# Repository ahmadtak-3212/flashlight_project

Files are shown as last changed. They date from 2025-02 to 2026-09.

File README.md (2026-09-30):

# Flashlight: high-power LED driver

A handheld flashlight built around a **Cree XHP50.3 (6 V)** LED. The repo holds two threads of work:

1. **The power converter** (finished, documented in the final report): a discrete, analog, constant-current **boost converter** that takes 3 V from two alkaline cells up to about 6–6.5 V and regulates the LED at about 1–1.5 A. It uses op-amps, a comparator and a gate driver, with no microcontroller in the loop. It was built as the final project for MIT 6.2222 (fall 2025), including the graduate extension.
2. **The product boards** (in progress): an STM32 controller with shake-to-wake, a USB-PD charger and power-path board, and an integrated v1.1 board meant to put everything on a single 21700-cell PCB.

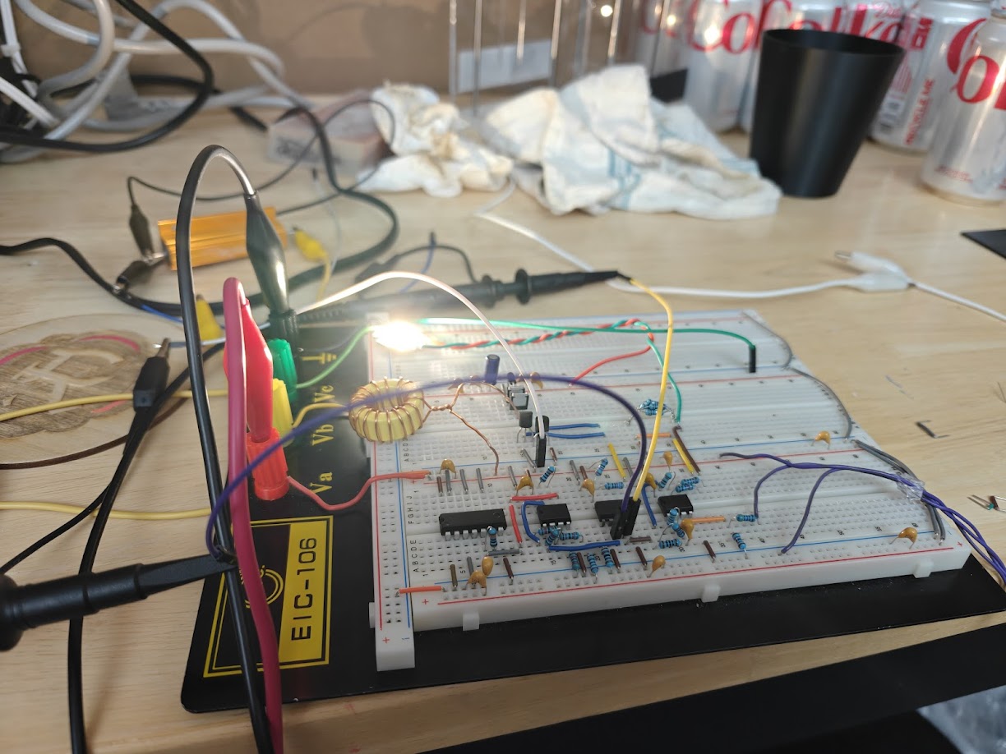
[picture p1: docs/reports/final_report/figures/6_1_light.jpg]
Flashlight running


📄 **Read the final report:** [`docs/reports/final_report/final_report.pdf`](docs/reports/final_report/final_report.pdf) (the Typst source is next to it). The original proposal is in [`docs/reports/proposal/`](docs/reports/proposal).

---

## Contents

- [Status](#status)
- [Repository layout](#repository-layout)
- [How the converter works](#how-the-converter-works)
- [Boards](#boards)
- [Firmware](#firmware)
- [Analysis](#analysis)
- [Mechanical](#mechanical)
- [Reproducing the design](#reproducing-the-design)
- [Results](#results)
- [Known issues and next steps](#known-issues-and-next-steps)

## Status

| Area | Status |
|---|---|
| Boost LED driver (report design) | ✅ Built and measured on the bench (1 A LED current, stable closed loop) |
| Dev boards (`boost-dev`, `boost-dev-2`, `stm32-dev`, `led`) | ✅ Routed, with JLCPCB fab and assembly files |
| USB-PD power-input board | 🟡 Routed (4 layers, KiCad 8/9, May 2026); fab outputs need regenerating (see [known issues](#known-issues-and-next-steps)) |
| Integrated board `flashlight-full-v1-1` | 🟡 Schematic only (14 sheets), not laid out |
| Firmware (STM32 shake-to-wake) | 🟡 Proof of concept (~100 lines) |
| Mechanical (body, head, optic) | 🟡 SolidWorks assembly, not yet built |

## Repository layout

```
flashlight_project/
├── docs/
│   └── reports/
│       ├── final_report/     Typst source + PDF + figures (6.2222 final report)
│       └── proposal/         project proposal (Typst + PDF)
├── electrical/               one KiCad project per board (see "Boards")
├── firmware/
│   └── flashlight-firmware-stm32/   PlatformIO project (STM32L151, Arduino core)
├── analysis/
│   └── sim/boost_transfer.m  MATLAB state-space model of the boost + PI loop
└── mechanical/
    └── cad/flashlight-v1.SLDASM     SolidWorks assembly (body, head, optic, cell)
```

See [docs/STRUCTURE.md](docs/STRUCTURE.md) for the folder conventions shared across my projects.

## How the converter works

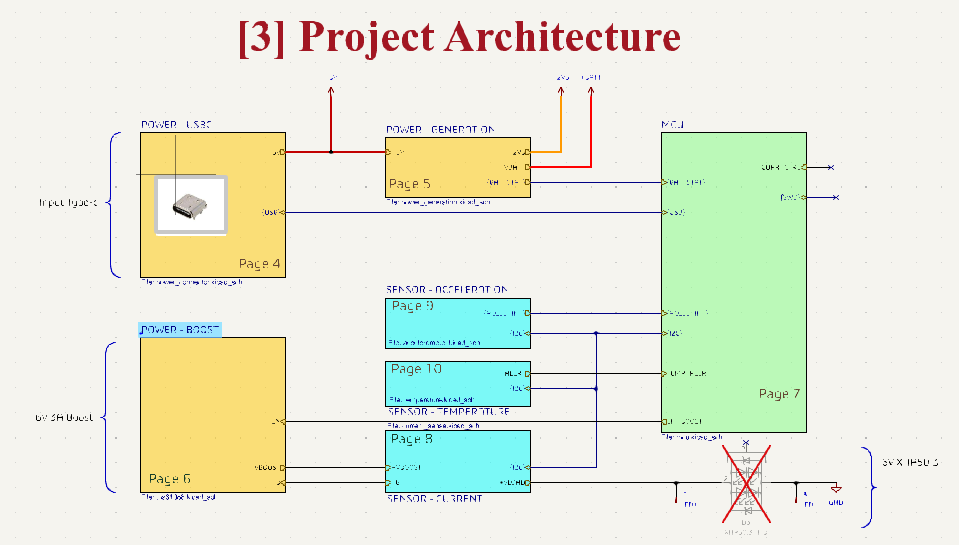
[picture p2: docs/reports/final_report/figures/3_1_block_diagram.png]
Block diagram


**Power stage.** A non-synchronous boost converter: a 22 µH inductor, a low-side switch, a Schottky rectifier and a 120 µF output capacitor. The LED returns to ground through a 0.2 Ω shunt.

| Parameter | Value |
|---|---|
| Input | 3 V (2 × alkaline cells) |
| Output | ≈ 6–6.5 V at the LED, 1–1.5 A (2 A hard ceiling) |
| Switching frequency | ≈ 100 kHz |
| Duty cycle | D ≈ 0.52 |
| Average inductor current | ≈ 3.9 A (ripple ≈ 0.7 A) |
| Inductor sizing | L_min ≈ 18 µH at 20 % ripple, so 22 µH chosen |
| Shunt dissipation | 0.45–0.8 W at 1.5–2 A |

**Control loop.** This is voltage-mode PWM with an outer LED-current loop, all built from analog parts:

1. An **LM358** amplifies the shunt voltage (current sense).
2. A second **LM358** stage acts as a PI controller and outputs V_ctrl. The model maps it with R_in = 10 kΩ and R_f = 680 Ω.
3. A third **LM358** generates a 0–1 V, ~100 kHz triangle.
4. An **LM311** comparator compares V_ctrl with the triangle to produce PWM.
5. An **IR2125** high-current gate driver drives the switch; a 12 V gate supply is needed for the GaN part.

**Switch comparison.** The same power stage was run with a silicon MOSFET (**RFD3055LESM**, ~107 mΩ) and a GaN FET (**GAN041-650WSBQ**, ~41 mΩ). Estimated device loss at the operating point is ≈ 84 mW for Si versus ≈ 18 mW for GaN, and the GaN part ran visibly cooler.

**Graduate extension.** The report adds a switched-capacitor quadrupler that charges a storage capacitor for a "flash" pulse through a 1 Ω series resistor (see “Graduate Extension” in the report).

The report also covers loop-shaping with Black's feedback formula and the boost converter's right-half-plane zero. It compares voltage-mode and current-mode control, drawing on the TI application notes it cites.

## Boards

All boards are KiCad projects under `electrical/`. Board renders are generated from the committed Gerbers.

| Board | What it is | Key parts | PCB |
|---|---|---|---|
| [`flashlight-boost-dev`](electrical/flashlight-boost-dev) | First IC-based LED boost test board | TPS61169 boost LED driver, NSR0240 Schottky, 4.7 µH WE-MAPI | 2 layers, 32 × 32 mm, JLCPCB files |
| [`flashlight-boost-dev-2`](electrical/flashlight-boost-dev-2) | Higher-power IC boost test board | TPS61500, 10 µH CDRH105R, SS36 3 A Schottky | 2 layers, 33 × 33 mm, JLCPCB files |
| [`flashlight-stm32-dev`](electrical/flashlight-stm32-dev) | "STM32L151C8 Battery Dev Board": controller and charging bring-up | STM32L151C8, BQ25185 charger/power path, MMA8452Q accelerometer, 2 × MCP1703A LDO, USB-C, ST-LINK header, 2 × 12 GPIO headers, RGB LED, 8 MHz + 32.768 kHz crystals | 6 layers, 120 × 35 mm, 99 parts, JLCPCB files |
| [`flashlight-led`](electrical/flashlight-led) | Small round LED carrier board | 3 LEDs, +18 V input | 2 layers, JLCPCB files |
| [`flashlight-power-input-dev`](electrical/flashlight-power-input-dev) | "100 W Power Delivery + Charger Module" | CYPD3177 USB-PD sink, BQ25792 buck-boost charger, BQ297xx protector, 4 × CSD16406Q3, 2 × LM5050-1 ideal diodes, TPS61222, TLV733, 21700 cell | 4 layers, 100 × 30 mm, 97 parts |
| [`flashlight-full-v1-1`](electrical/flashlight-full-v1-1) | Integrated flashlight (schematic) | STM32F070F6P, TPS61088 boost, BQ25185, BQ27220 fuel gauge, MMA8452Q, TMP102, INA180A1, MCP4017 digipot, IR2125, LM358 × 3, LM311, 74HC14, 2 × XHP50.3, 21700 cell, USB-C | 6-layer stackup, 14 schematic sheets, not laid out |
| `flashlight-hardware` | Empty placeholder project | — | — |

The early plan used TI boost-LED ICs (the two `boost-dev` boards). They could not deliver the current the XHP50.3 needs, which is why the report design went discrete.

<details>
<summary>Board renders (top and bottom)</summary>

**flashlight-boost-dev** (TPS61169)
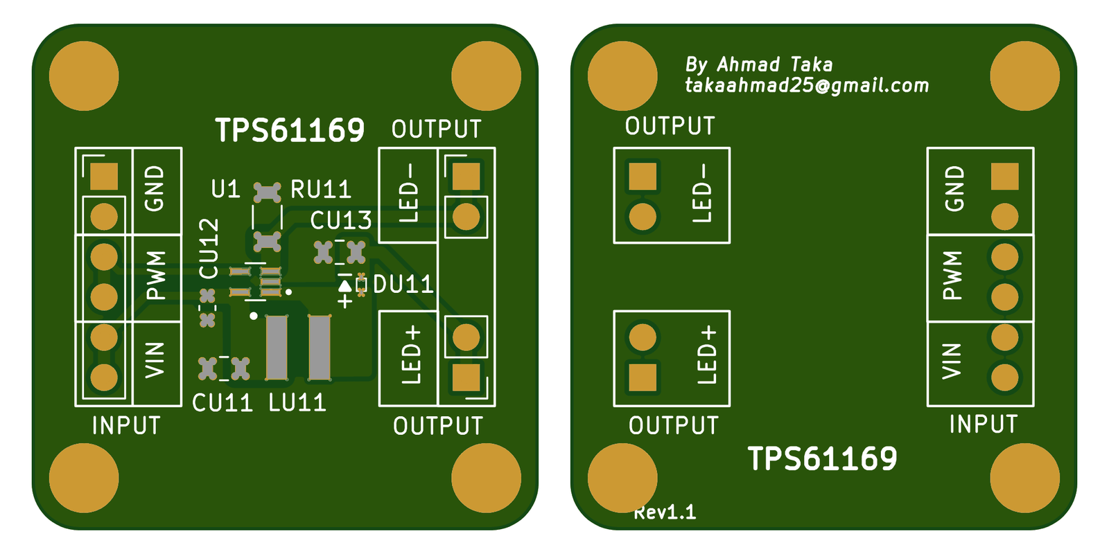
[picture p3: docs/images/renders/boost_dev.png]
boost-dev


**flashlight-boost-dev-2** (TPS61500)
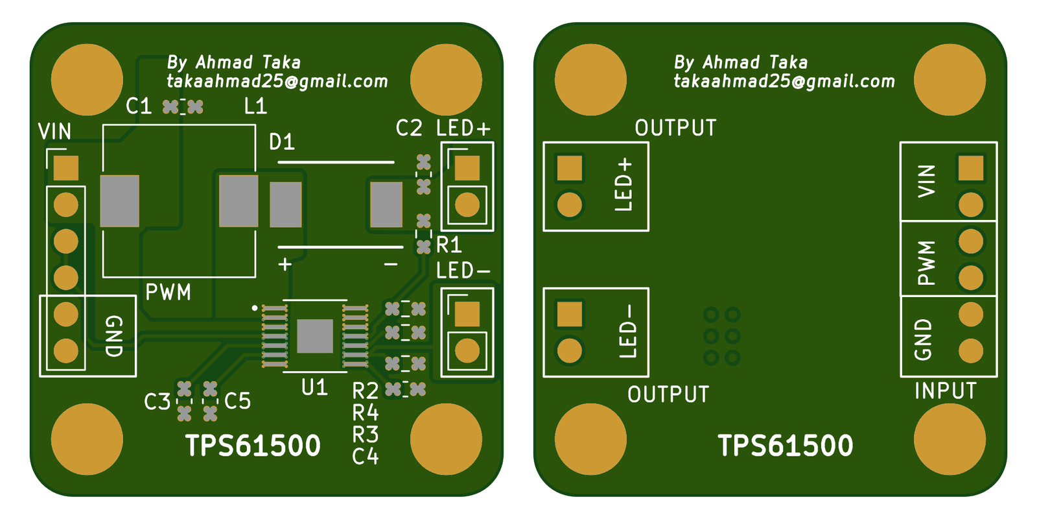
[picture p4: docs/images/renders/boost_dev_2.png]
boost-dev-2


**flashlight-stm32-dev**
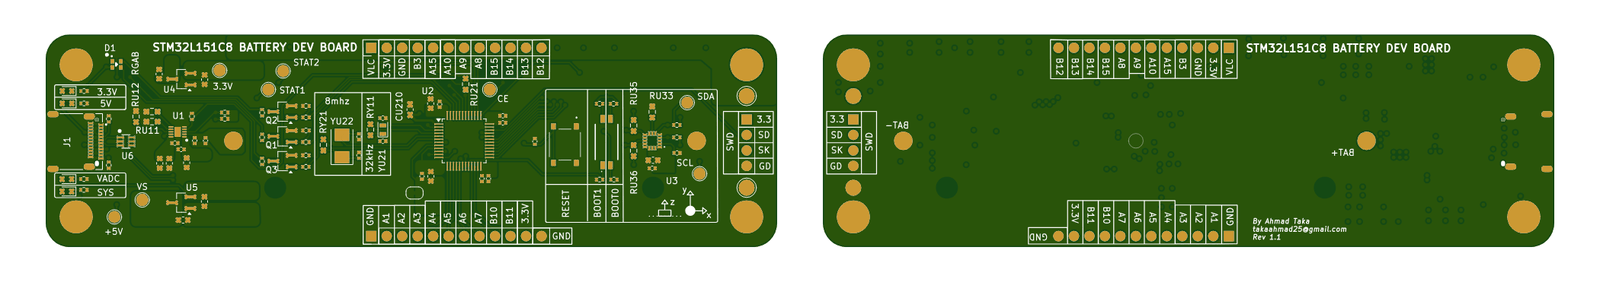
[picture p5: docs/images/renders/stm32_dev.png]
stm32-dev


</details>

## Firmware

`firmware/flashlight-firmware-stm32` is a PlatformIO project for the STM32L151 dev board. It shows the shake-to-toggle behavior:

- It configures the MMA8452Q **transient (shake) detector** over I²C on PB7/PB6: X/Y axes, threshold 12 (≈ 0.75 g), 25 × 20 ms debounce.
- The accelerometer interrupt on **PA0** wakes the MCU from deep sleep through `STM32LowPower`, and each shake toggles the output on **PB9**.

| Setting | Value |
|---|---|
| Platform | `ststm32`, Arduino framework |
| Board definition | `rak811_tracker` (an STM32L151 board used as a stand-in), with a local `boards/` directory |
| Libraries | `sparkfun/SparkFun_MMA8452Q ^1.4.0`, `stm32duino/STM32duino Low Power ^1.4.0` |
| Upload | `serial`: the STM32 ROM UART bootloader (hold BOOT0 high and reset) |

```bash
cd firmware/flashlight-firmware-stm32
pio run                     # build
pio run -t upload           # flash over the UART bootloader
# or use the board's ST-LINK header: set upload_protocol = stlink in platformio.ini
```

## Analysis

`analysis/sim/boost_transfer.m` (MATLAB) builds the averaged small-signal model of the boost, including the RHP zero. It wraps the PI controller around that model as an augmented state-space system, then plots the loop Bode response and the closed-loop setpoint step. Run it in MATLAB with the Control System Toolbox. The listing is also in the report appendix.

| Loop gain | Step response |
|---|---|
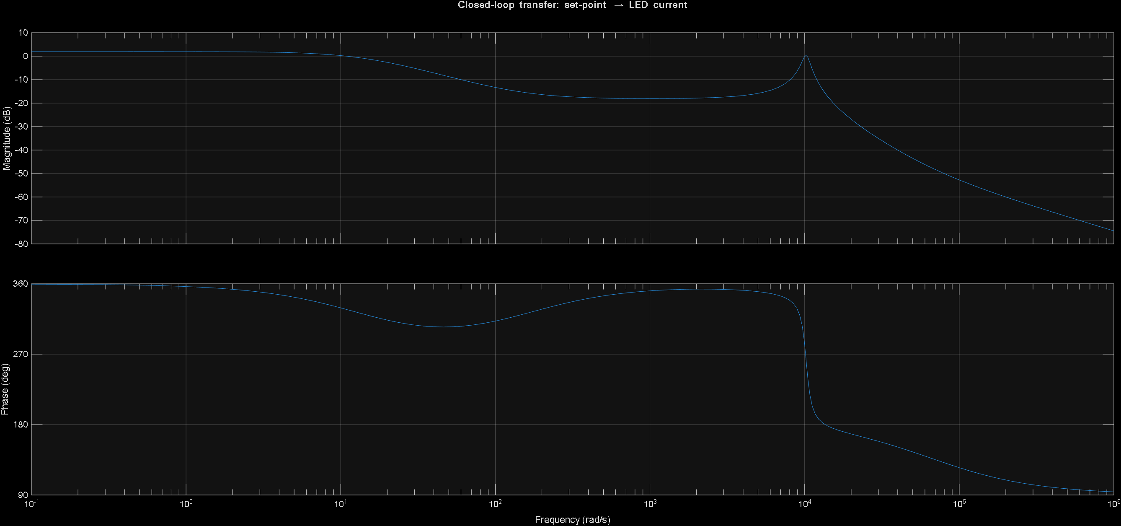
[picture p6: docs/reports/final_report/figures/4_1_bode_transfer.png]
Bode
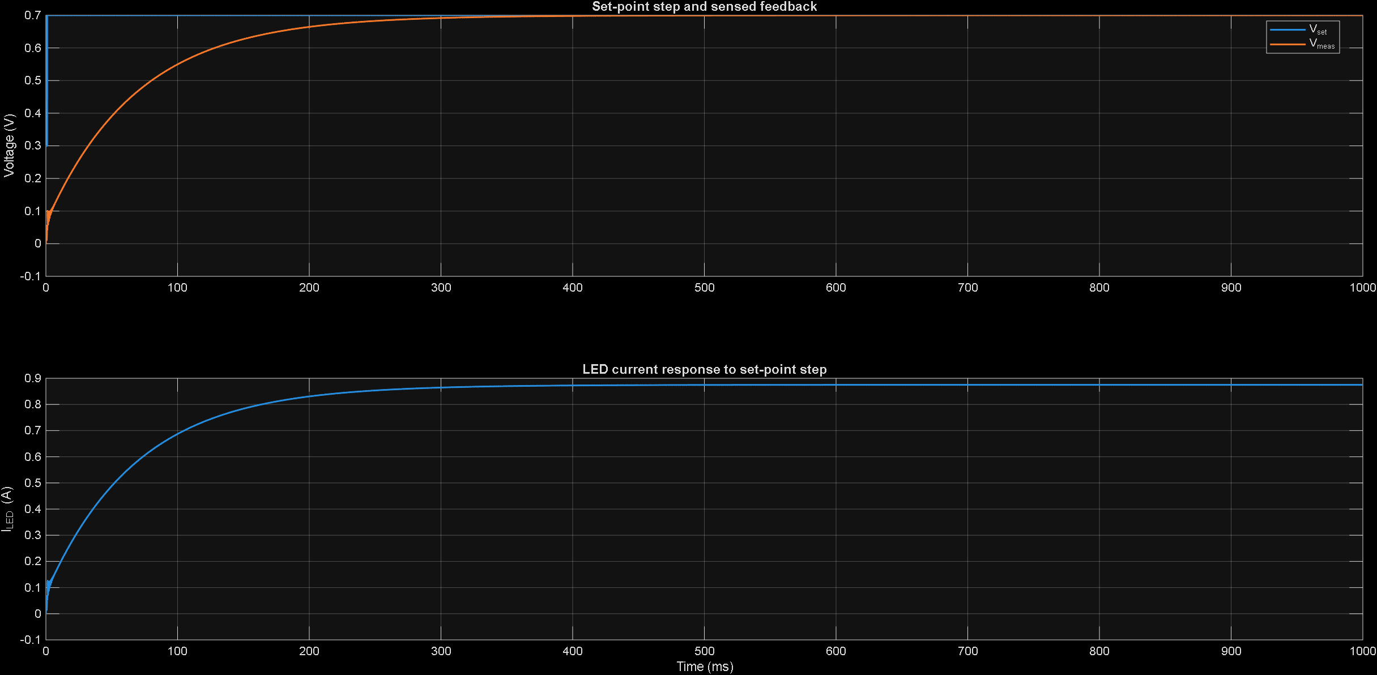
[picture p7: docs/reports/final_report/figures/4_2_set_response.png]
Step
|  |  |

## Mechanical

`mechanical/cad/flashlight-v1.SLDASM` (SolidWorks) contains the body, head, a TIR 60° optic, an 18650 cell model, a copper slug for the LED, and the LED PCB. Mounting holders for the dev boards are in `electrical/<board>/holder/` (SLDPRT and STEP).

## Reproducing the design

| What | Tool |
|---|---|
| Schematics and PCBs | KiCad 8 or newer. `flashlight-power-input-dev` was last saved in KiCad 9. Projects use `${KIPRJMOD}`-relative libraries in each board's `libs/` folder. |
| PCB fab and assembly | Each board has `jlcpcb/gerber/` and `jlcpcb/production_files/` (Gerber zip, BOM and CPL) for JLCPCB. |
| Report | [Typst](https://typst.app) (`typst compile final_report.typ`) |
| Model | MATLAB with the Control System Toolbox |
| Firmware | PlatformIO (VS Code extension or `pio` CLI) |
| CAD | SolidWorks |

**Rebuilding the report converter on a bench.** Component values and schematic blocks are in the report's “Circuit Design and Analysis” chapter, which covers the power stage, current sense and PI loop, magnetics, and switch choice. “Hardware Implementation and Measurement Setup” covers the bench setup.

Bring-up order, from the report:
1. Run the boost open-loop at a fixed duty cycle into a resistive load.
2. Close the current loop at a low setpoint.
3. Raise the setpoint to the LED operating point.

The two fixes that mattered were:
- an RC filter (100 Ω / 1 nF) on the current-sense signal, and
- hysteresis on the LM311 comparator to stop chatter.

## Results

- The loop is closed and stable at about **1 A LED current** from a 3 V input. The output is 6–6.5 V, and the measured duty cycle is ≈ 0.5, close to the 0.52 predicted.
- The setpoint step response is well damped, as the MATLAB model predicts. Remaining differences come from LM358 bandwidth, comparator delay and the non-ideal ramp.
- GaN vs Si: both reach the same operating point, and the GaN FET runs cooler.
- The LED case settles near **70 °C** at the operating point. That is acceptable, but heatsinking through the copper slug is required.

| Bench setup | Thermal |
|---|---|
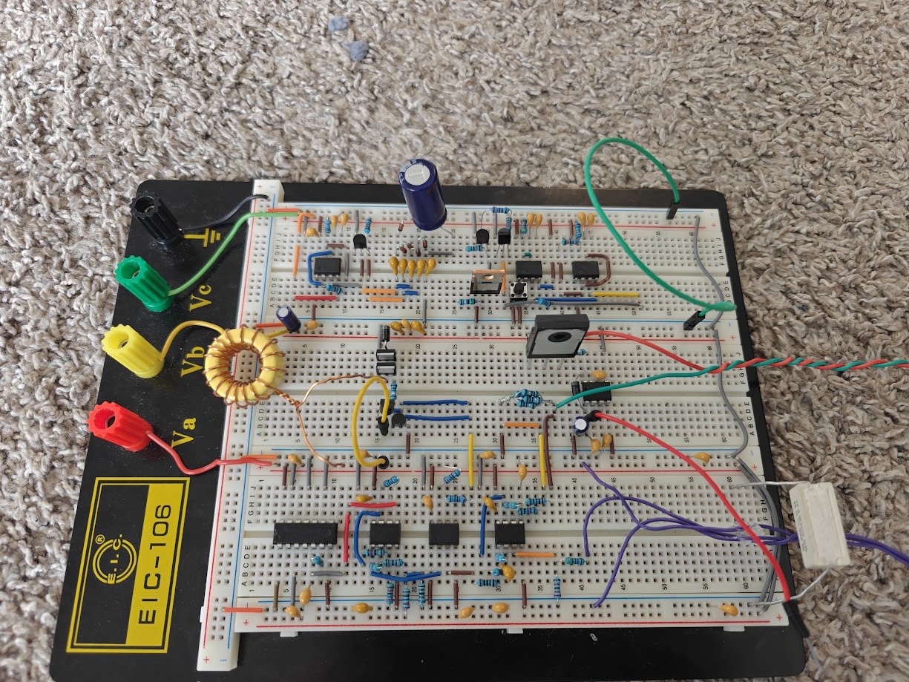
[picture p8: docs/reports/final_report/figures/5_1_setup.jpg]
Setup
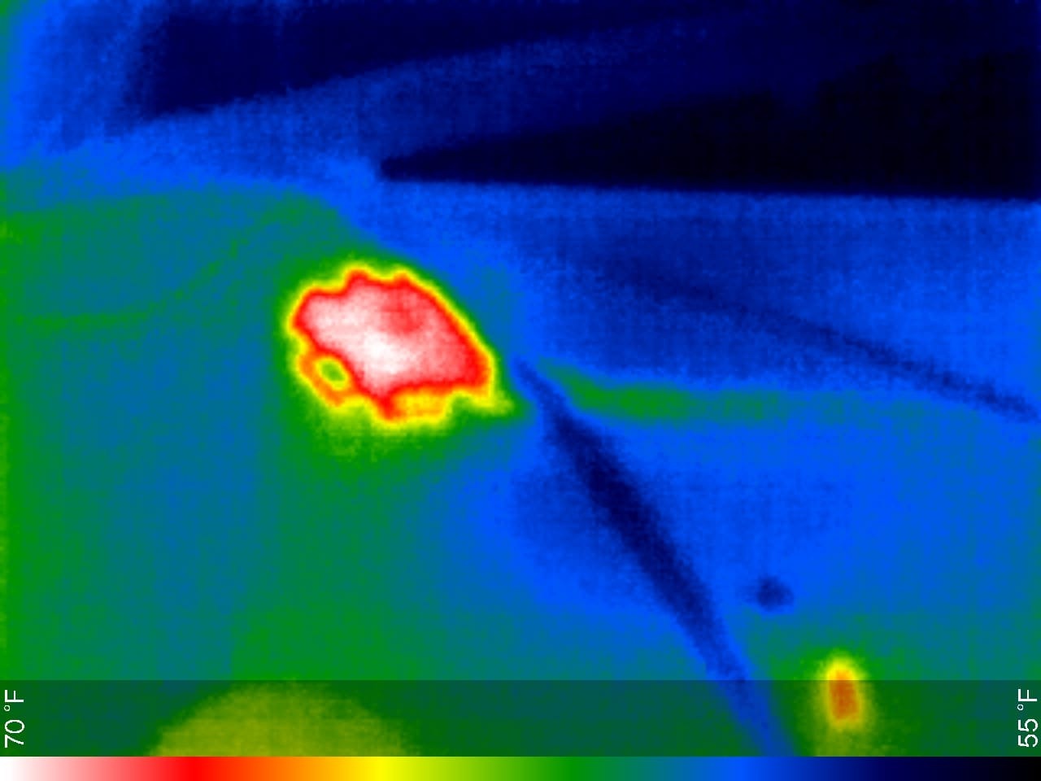
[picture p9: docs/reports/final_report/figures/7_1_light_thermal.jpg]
Thermal
|  |  |

## Known issues and next steps

- The Gerbers in `electrical/flashlight-power-input-dev/jlcpcb/` are **copies of the mp3 player board**, left over from the project template. Regenerate them from `flashlight-power-input-dev.kicad_pcb` before ordering.
- `flashlight-full-v1-1` still needs layout. It merges the report's analog current loop (LM358/LM311/IR2125) with the STM32 controller, charger and fuel gauge.
- Firmware still needs brightness control through the digipot or PWM setpoint, battery reporting from the BQ27220, and thermal limiting from the TMP102.

## Author

Ahmad Taka.

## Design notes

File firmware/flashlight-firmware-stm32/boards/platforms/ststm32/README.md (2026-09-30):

# ST STM32: development platform for [PlatformIO](https://platformio.org)



The STM32 family of 32-bit Flash MCUs based on the ARM Cortex-M processor is designed to offer new degrees of freedom to MCU users. It offers a 32-bit product range that combines very high performance, real-time capabilities, digital signal processing, and low-power, low-voltage operation, while maintaining full integration and ease of development.

* [Home](https://registry.platformio.org/platforms/platformio/ststm32) (home page in the PlatformIO Registry)
* [Documentation](https://docs.platformio.org/page/platforms/ststm32.html) (advanced usage, packages, boards, frameworks, etc.)

# Usage

1. [Install PlatformIO](https://platformio.org)
2. Create PlatformIO project and configure a platform option in [platformio.ini](https://docs.platformio.org/page/projectconf.html) file:

## Stable version

```ini
[env:stable]
platform = ststm32
board = ...
...
```

## Development version

```ini
[env:development]
platform = https://github.com/platformio/platform-ststm32.git
board = ...
...
```

# Configuration

Please navigate to [documentation](https://docs.platformio.org/page/platforms/ststm32.html).

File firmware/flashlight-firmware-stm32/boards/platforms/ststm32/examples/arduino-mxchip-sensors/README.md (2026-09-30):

How to build PlatformIO based project
=====================================

1. [Install PlatformIO Core](https://docs.platformio.org/page/core.html)
2. Download [development platform with examples](https://github.com/platformio/platform-ststm32/archive/develop.zip)
3. Extract ZIP archive
4. Run these commands:

```shell
# Change directory to example
$ cd platform-ststm32/examples/arduino-mxchip-sensors

# Build project
$ pio run

# Upload firmware
$ pio run --target upload

# Clean build files
$ pio run --target clean
```

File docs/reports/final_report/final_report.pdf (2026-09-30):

# Final Project Report: Flashlight Power Converter Design

Ahmad Taka
ahmadtak@mit.edu
MIT EECS

December 9th, 2025

## 1 Introduction and Project Motivation

For the final project, a discrete, low-voltage boost LED driver is designed and built for a Cree XHP50.3 6 V LED (XHP50D-00-0000-0D0UH240G).(Xlamp Xhp50.3 Leds 2025) The objective is to realize a compact, thermally-managed flashlight that is bright enough to illuminate a workspace or driveway while remaining efficient and comfortable to hold. Although high-power LED flashlights are widely available, most commercial designs conceal the internal power-converter behavior and provide little visibility into regulation, transient response, or thermal performance. This work instead emphasizes a transparent, measurement-friendly architecture in which the power electronics are explicitly designed, modeled, and probed, rather than relying on off-the-shelf drivers.

The project builds on prior hardware developed over the summer, where a custom STM32-based board was designed to manage a Li-ion cell, deliver up to 3 A on a power-path rail using the BQ2125, and interface with an onboard accelerometer to implement a “shake-to-wake” LED control gesture. During that effort, several commercial boost LED drivers, including the TPS61169 and TPS61500, were evaluated and found unable to deliver sufficient current to fully drive the Cree XHP50.3. These limitations motivated the development of a higher-power, constant-current architecture in which a boost converter measures LED current via a shunt resistor and regulates it directly to achieve stable brightness and predictable thermal behavior. In the present work, the prototype operates from a single 3 V rail representing a fresh pair of alkaline cells, with no upstream regulation. The converter must boost from 3 V to approximately 6–6.5 V to drive the Cree XHP50.3 in its 6 V configuration (typical forward voltage 5.6–6.2 V at 1.4 A, 3 A continuous rating), while maintaining acceptable component stress and temperature margins.(Xlamp Xhp50.3 Leds 2025)

For the 6.2222 graduate extension, the flashlight driver is used as a laboratory platform for converter modeling, control design, and energy-flow analysis. The implementation uses discrete analog building blocks (LM358 op-amps, comparator, 22 µH inductor, current shunt), alongside small-signal modeling and MATLAB state-space simulation to study loop stability and transient response. Time-domain and frequency-domain measurements (inductor current, switch node voltage, LED current, control signals) will be used to validate the models. In addition, silicon MOSFET and GaN FET devices will be compared in the same boost topology to quantify differences in switching loss and thermal performance. Tellegen’s theorem will be applied to track energy flow through the converter and verify that measured power losses are consistent with theoretical predictions. Finally, a small switched-capacitor voltage doubler will be constructed to generate short, higher-voltage flashes on the LED, extending Lab 3 concepts to examine how brief high-voltage bursts affect brightness and heating.

## 2 Independent Inquiry Background and Control-Theoretic Context

The independent inquiry drew on the 6.2222 notes, Tellegen-based energy flow arguments, and two Texas Instruments application reports on boost converter feedback loops.(Lee 2014a; 2014b) The reference material places the boost in the context of general feedback-system theory, emphasizing loop gain, sensitivity, and the special role of right-half-plane (RHP) zeros in the overall stability of the system.

### 2.1 Black’s feedback theorem and loop-shaping viewpoint

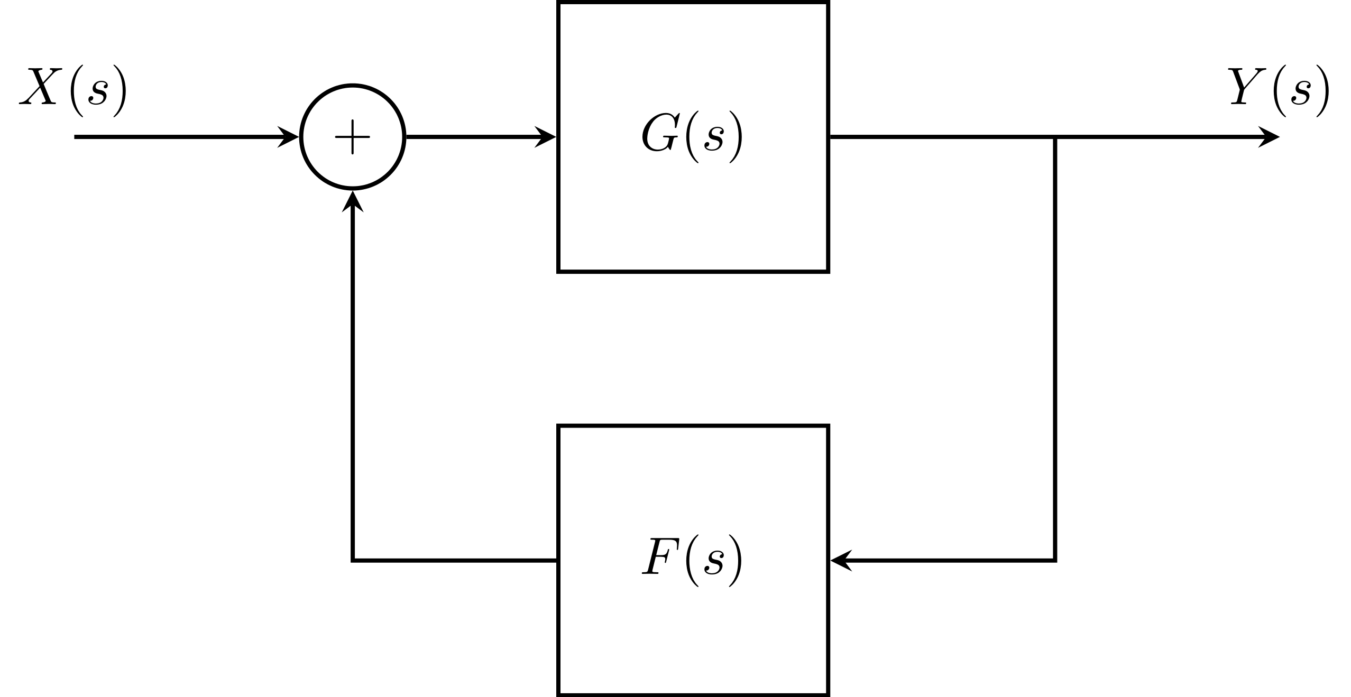
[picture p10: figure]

Figure 1: Blacks formula block diagram

Black’s classical feedback model represents the closed-loop system as a forward plant G(s), a feedback network F(s), and an input X(s) and output Y (s). The basic closed-loop relation is

T (s) =

Y (s)
X(s)

=

G(s)
1 + G(s)F(s)

(1)

Defining the loop gain
L(s) = G(s), F(s) | (2)
the sensitivity and complementary sensitivity functions are

S(s) =

1
1 + L(s)

, q T (s) =

L(s)
1 + L(s)
. | (3)

Low |S(jω)| at low frequency means good disturbance rejection and small steady-state error; the magnitude and phase of L(jω) near crossover control stability and transient behavior. In the LED driver, the plant G(s) is the averaged boost converter plus PWM modulator; the compensator and current-sense network form F(s). The design goal is a loop gain L(s) that achieves accurate current regulation (low-frequency gain and small |S|) and sufficient phase margin at crossover.

### 2.2 Voltage-mode versus current-mode control in boost converters

The TI voltage-mode report models the continuous-conduction boost as an LC output filter with ESR zero and an RHP zero whose location depends on load, inductance, and duty cycle.

(Lee 2014a) Linearization gives a control-to-output transfer function with a moving double pole at the LC resonance and a right-half-plane zero at

frhp = Rload ∗

(1 − D)

2
2 ∗ π ∗ L

(4)

This zero moves to lower frequency at heavy load, low input voltage, or large inductance. It contributes +20 dB/dec of gain but also an additional 90° of phase lag, so Black’s feedback theorem implies that the loop crossover must be kept well below this frequency (typically fc ≤

frhp
5

) to preserve adequate phase margin and avoid instability.(Lee 2014a)

The current-mode report analyzes an alternative architecture with an inner cycle-by-cycle current loop and an outer voltage loop.(Lee 2014b) From the outer-loop perspective, the inductor dynamics are “prelinearized” and the LC double pole collapses to a single dominant pole associated with the output capacitor and load. A Type-II compensator (one pole at the origin plus a pole–zero pair) suffices, with simpler design rules and improved phase margin at a given crossover.

### 2.3 Relevance to a constant-current LED boost driver

Although the final flashlight driver is not a textbook current-mode converter, the LED-current regulation problem is structurally similar to the TI voltage-mode designs: a PI controller and comparator form a voltage-mode outer loop around a boost power stage whose “load” is a nonlinear LED plus shunt resistor. Around a given operating point, the LED may be linearized as an effective resistance, so the plant still exhibits an LC double pole and an RHP zero set by L, duty cycle, and equivalent load resistance.

The inquiry applied the TI voltage-mode model to estimate frhp and the LC resonant frequency for the chosen inductance and LED operating points, setting upper bounds on crossover. It then used the current-mode compensator rules as a template for the PI design: integrator pole at the origin, a zero below crossover to add phase, and a high-frequency pole implicit in the op-amp and PWM modulator. Black’s sensitivity functions S(jω) and T (jω) provide the interpretation: low-frequency gain and small |S| translate into accurate current regulation and good line/load rejection, while adequate phase margin at crossover prevents the duty-cycle adjustments from exciting RHP-zero or half-switching-frequency pathologies.

## 3 System Requirements and Architecture Overview

### 3.1 Electrical and performance requirements

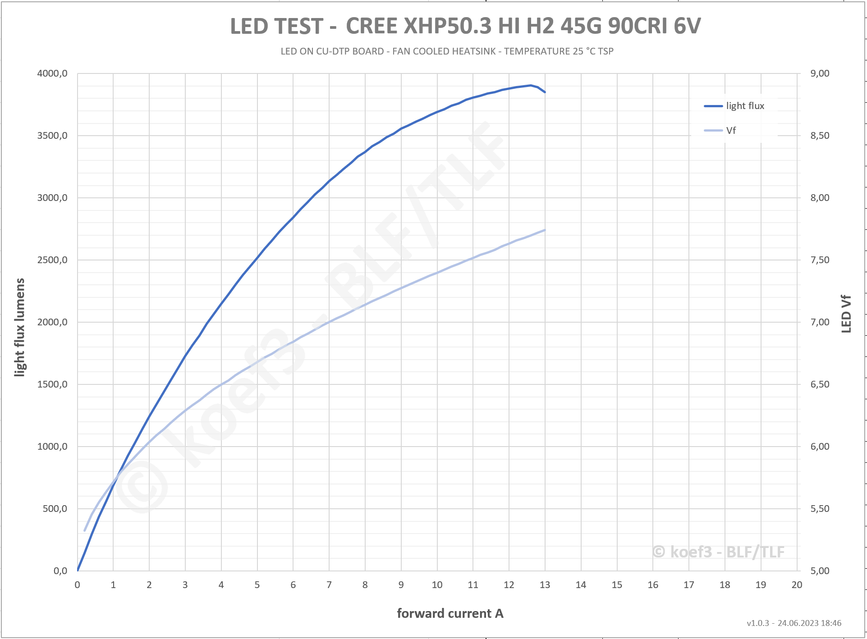
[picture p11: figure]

Figure 2: Plot of LED Load curve and operating points

The driver targets a single 3 V supply (two alkaline cells) and a Cree XHP50.3 6 V LED driven near 1–1.5 A, with a hard upper ceiling around 2 A to respect the 3 A absolute maximum rating and keep junction temperatures reasonable.(Xlamp Xhp50.3 Leds 2025) Around the design operating point the LED forward voltage is about 6 V, so the converter must provide roughly 6–6.5 V from a 3 V input.

For an ideal continuous-conduction boost converter, the dc conversion ratio is

M =

Vout
Vin

=

1
1 − D
, | (5)

so with Vin = 3, V and Vout ≈ 6.2, V the required duty cycle is

D = 1 −

Vin

Vout

≈ 1 −

3
6.2
≈ 0.52. | (6)

At Vout ≈ 6.2, V and Iout ≈ 1.5, A, the output power is ≈9.3 W. With efficiency in the 75–85% range, the input current is roughly 4–4.5 A, which sets the stress on the inductor, switch, diode, and shunt. The design goal is to keep LED current ripple below about 10% of the dc level.

### 3.2 Control and stability requirements

From a control standpoint, the driver should behave as a current regulator: the user sets an LED current, and the loop adjusts duty cycle so that the measured average current tracks over variations in LED forward voltage and input voltage. The specific objectives are:

- Continuous conduction in the main operating region.
- Crossover fc

below both the boost RHP zero and fsw
10

, with at least 45–60° of phase margin.
- Step changes in setpoint that settle without sustained oscillation and with limited overshoot.
- Hardware constraints on maximum duty cycle set by op-amp swing and ramp amplitude, even though no explicit clamp circuit is present.

The implemented structure uses LM358 op-amps at 3 V for current sense, PI controller, and triangle generator, plus a comparator and low-side switch device. The independent inquiry provides the theoretical basis for selecting PI pole and zero locations and the target loop gain shape.

### 3.3 Thermal and mechanical constraints

The LED dissipates roughly 10 W at full brightness, plus several watts of converter loss. The XHP50.3 is rated to 150 °C junction, but practical operation suggests staying well below 100 °C for long life and color stability.(Xlamp Xhp50.3 Leds 2025) The inductor and switch device must handle several amperes of current without saturation or excessive temperature rise.

Mechanically, the prototype is built on a breadboard or prototyping PCB with careful attention to minimizing loop inductances on the high-di/dt paths and providing accessible test points (Vmeas, Vset, V_tri, V_ctrl, switch node). A future PCB version would fit into a flashlight host, but the electrical requirements are already based on that form factor.

### 3.4 Architecture overview

The system is partitioned into:

1. Input stage (3 V source and local decoupling),
2. Boost power stage (22 µH inductor, rectifier diode, 120 µF output capacitor, LED, 0.2 Ω shunt),
3. Current-sense and signal-conditioning (0–1 V range),
4. PI controller and reference generation (0–1 V setpoint),
5. PWM modulator and gate drive (100 kHz ramp and comparator),
6. Measurement hooks for scope-based loop analysis.

This architecture links the requirements to specific circuit blocks and provides a clean mapping to the modeling and simulations that follow.

## 4 Circuit Design and Analysis

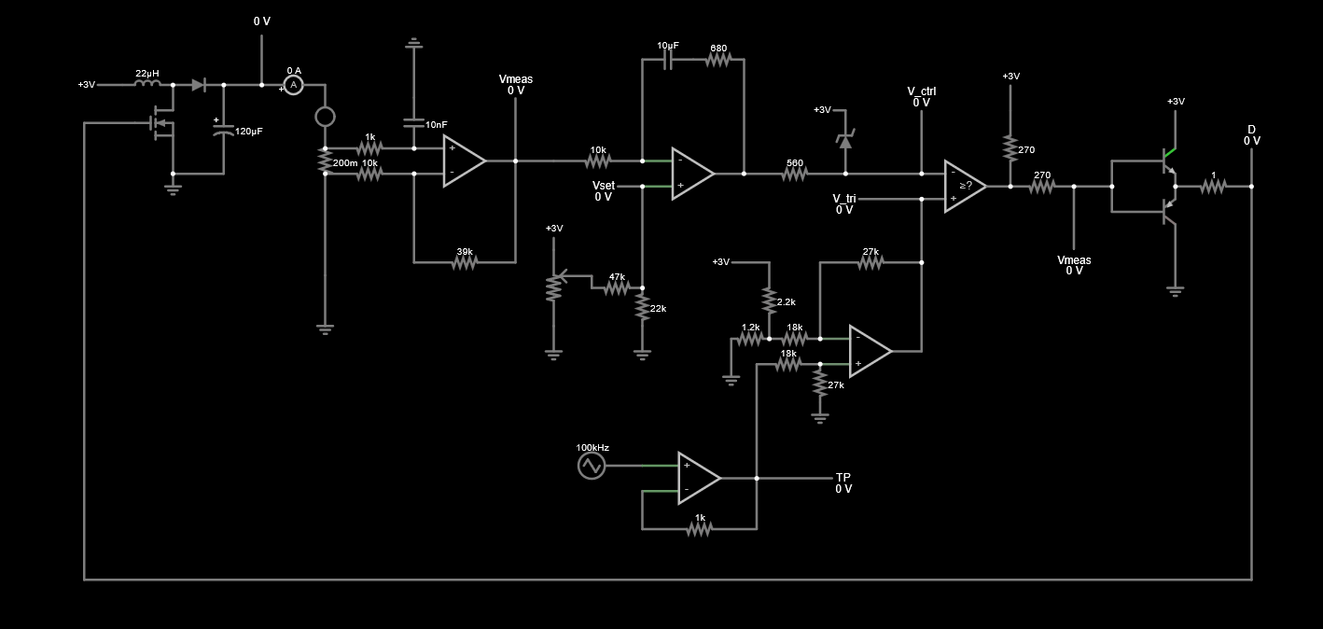
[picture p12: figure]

Figure 3: schematic of boost converter circuit

### 4.1 Power Stage (Boost Converter)

The power stage in figure 3 is a non-synchronous boost converter that steps a single 3 V source up to ≈6–6.5 V for the XHP50.3 LED.(Xlamp Xhp50.3 Leds 2025) The inductor (L = 22, µH) sits in series with the input, followed by a Schottky rectifier and an output capacitor (Cout = 120, µF) feeding the LED and 0.2 Ω sense resistor. A low-side switch periodically connects the inductor to ground; in the on interval the inductor current ramps up, and in the off interval the stored energy is delivered to the output.

Assuming Iout ≈ 1.5, A and efficiency η ≈ 0.8, the average inductor current is

IL,avg ≈ Iin ≈ Vout ∗

Iout
η ∗ Vin

≈ 6.2 ∗

1.5
0.8 ∗ 3
≈ 3.9, | (7)

The inductor ripple is set by the input voltage and duty cycle:

ΔIL = Vin ∗

D
L ∗ fsw
. | (8)

With Vin = 3, V , D ≈ 0.52, L = 22, µH, and fsw ≈ 100, kHz, this gives

ΔIL ≈ 3 ∗

0.52
22e − 6 ∗ 100e3
≈ 0.7, | (9)

so the ripple is ≈18% of IL,avg, keeping the stage comfortably in continuous conduction.

The small-signal dynamics follow the standard voltage-mode boost model. The equivalent inductance seen by the output is

Leq =

L
(1 − D)

2

, | (10)

so the power-stage double pole is at

f0 = (

1
2 ∗ π

) ∗ √
(1 − D)

2
L ∗ Cout
. | (11)

The RHP zero is

frhp = Rload ∗

(1 − D)

2
2 ∗ π ∗ L
, | (12)

where Rload is the linearized LED plus series resistance. For the chosen parameters this places f0

in the low-kilohertz range and frhp at several kilohertz, which constrains the allowable loop crossover.

### 4.2 Current Sense and PI Control Loop

The LED current flows through a fixed shunt Rs = 0.2, Ω. With ILED in the 0–2 A range, the shunt voltage vs = ILED ∗ Rs

spans 0–0.4 V. A differential amplifier with gain Asense translates this into a ground-referenced 0–1 V signal:

vmeas(s) ≈ Asense ∗ Rs ∗ ILED(s) ≡ Ksense ∗ ILED(s)

, | (13)

where Ksense = Asense ∗ Rs
is the effective current-sense gain. The setpoint is generated by a potentiometer from 0–3 V and then scaled down by a small divider to 0–1 V:

vset = vpot ∗

Rbot

Rtop + Rbot

, | (14)
with | Rbot
Rtop+Rbot

≈

1/3. An LM358 buffer provides a low impedance reference. When vmeas = vset, the loop enforces
ILED ≈

vset

Ksense

=

vset

Asense ∗ Rs

, | (15)

which matches the MATLAB normalization where vset in the 0–1 V range corresponds to the desired 0–1.25 A LED current.

The error e(t) = vset(t) − vmeas(t)
is processed by an LM358 configured as a PI controller. The input resistor Rin feeds e(t) into the inverting input, and the feedback consists of Rf in parallel
with Cf
, giving the feedback impedance

Zf(s) = Rf =

Rf
1 + s ∗ Rf ∗ Cf
. | (16)

The resulting compensator is

Gc(s) =

Vctrl(s)
E(s)

= −

Zf(s)
Rin

= −(

Rf
Rin ) ∗

1
1 + s ∗ Rf ∗ Cf
, | (17)

where the overall sign is chosen so that the feedback is negative at the comparator input. The LM311 PWM compares Vctrl to a 0–1 V triangle wave, so around the operating point the small-signal duty-cycle perturbation can be approximated as
d(s) ≈ Vctrl(s) = Gc(s) ∗ E(s). | (18)

To relate duty cycle to LED current, the boost converter is modeled in continuous conduction mode with an equivalent LED resistance Rload ≈

VLED
ILED

and steady-state duty ratio D. The averaged small-signal plant from duty perturbation d(s) to LED current is written in the standard two-pole, one right-half-plane-zero form

Gp(s) ≡

ILED(s)
D(s)

= (

Vin
Rload ∗ (1 − D)

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
Q∗ω0

+ 1

, | (19)

with

ω0 =

1 − D
√
L ∗ C

, q Q = (1 − D) ∗

Rload

√L
C

, q ωz = (1 − D)

2 ∗

Rload
L
, | (20)

where ω0

is the LC natural frequency, Q is the damping factor, and ωz is the right-half-plane
zero associated with the boost topology.

Combining the sense amplifier, compensator, and power stage yields the loop equations

e(s) = vset(s) − Ksense ∗ ILED(s)

, q d(s) = Gc(s) ∗ e(s), q ILED(s) = Gp(s) ∗ d(s). (21)

Eliminating e(s) and d(s) gives the closed-loop transfer function from setpoint to LED current:

ILED(s)

vset(s)

= Gp(s) ∗

Gc(s)

1 + Ksense ∗ Gp(s) ∗ Gc(s)

, | (22)

and, equivalently, the transfer from setpoint to sensed voltage is

vmeas(s)

vset(s)

= Ksense ∗ Gp(s) ∗

Gc(s)

1 + Ksense ∗ Gp(s) ∗ Gc(s)

. | (23)

These expressions explicitly show how the closed-loop behavior depends on the design variables L, C, Rload, Rs

, Asense, Rin, Rf

, Cf

, and the operating duty ratio D.

### 4.3 Magnetics and Component Sizing

The inductor value is chosen from a ripple constraint: ΔIL

IL,avg

= Vin ∗

D
L ∗ fsw ∗ IL,avg
≤ ρ, | (24)

with ρ the desired fractional ripple. Rearranging,

L ≥ Vin ∗

D
ρ ∗ fsw ∗ IL,avg
. | (25)

Using Vin = 3, V , D ≈ 0.52, fsw = 100, kHz, IL,avg ≈ 3.9, A, and ρ ≈ 0.2 gives a minimum L of about 18 µH; 22 µH is a natural choice.

The output capacitor size follows from ripple:

ΔVout ≈ Iout ∗

D
Cout ∗ fsw
. | (26)

With the chosen Cout, the ripple is only tens of millivolts, and the (L, C“out”, R“load”) combination yields f0

and frhp consistent with the control design.

The shunt dissipates
Ps ≈ I

2
out ∗ Rs
, | (27)
which at 1.5–2 A and 0.2 Ω is 0.45–0.8 W. This is acceptable for a 1 W sense resistor over short lab runs and provides a relatively large 1 V full-scale sense signal.

### 4.4 GaN vs Si FET comparison

The project compares an onsemi RFD3055LESM MOSFET and a Nexperia GAN041-650WSBQ GaN FET as candidate switches.(Rfd3055le, Rfd3055lesm n-Channel Logic Level Power MOSFET 2002; Gan041–650wsb / Gan041–650wsbq: 650 V, 35 m\ohm{} Gallium Nitride (Gan) FET in a TO-247 Package 2024) The RFD3055LESM has Rds,on ≈ 107mΩ at VGS = 5, V and total gate charge Qg ≈ 11.3, nC; the GAN041-650WSBQ has Rds,on ≈ 41, mΩ (35 mΩ typical) and faster edges.

Conduction loss is approximated by
Pcond ≈ D ∗ I

2
L,avg ∗ Rds,on, | (28)
so with D ≈ 0.52 and IL,avg ≈ 3.9, A:

Pcond,Si ≈ 0.52 ∗ 3.9

2 ∗ 0.107 ≈ 0.85, | (29)

Pcond,GaN ≈ 0.52 ∗ 3.9

2 ∗ 0.041 ≈ 0.32. | (30)

Switching loss is estimated as
Psw ≈ 0.5 ∗ Vin ∗ IL,avg ∗ (tr + tf
) ∗ fsw. | (31)

At 3 V, 3.9 A, 100 kHz, and ≈144 ns total edge time, the silicon device dissipates ≈84 mW; the GaN device at ≈31 ns totals ≈18 mW. At 100 kHz both are conduction-dominated, but the GaN FET cuts total device losses by more than 2×. At higher fsw the GaN advantage grows.

### 4.5 Graduate Extension: Switched-Capacitor Quadrupler Flash Supply

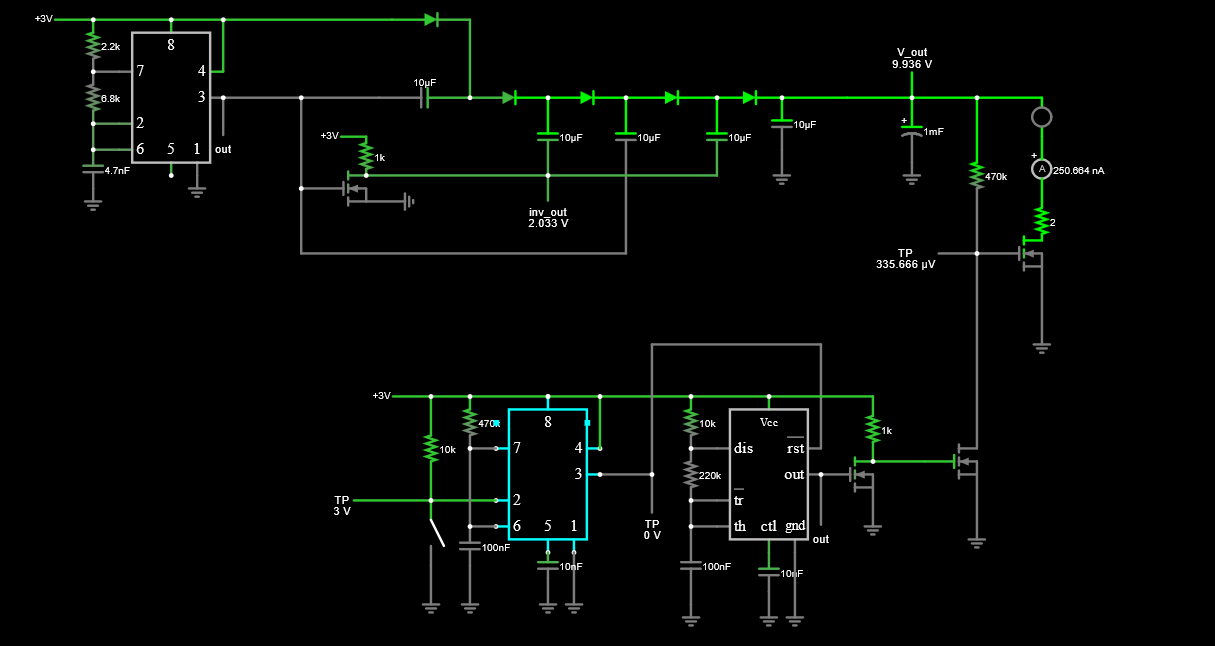
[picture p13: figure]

Figure 4: schematic of switched-capacitor quadrupler flash circuit

In this prototype the network is driven from Vin = 3V and uses four flying-capacitor stages to charge a storage capacitor Cflash to approximately Vflash,hi ≈ 10V . The flash path consists of this storage capacitor, a 1,Ω series resistor, the 6,V, 3,A LED, and a MOSFET switch. During a flash the MOSFET connects Cflash to the LED so that the capacitor discharges from Vflash,hi down toward some lower voltage Vflash,lo.

The energy extracted from the storage capacitor by a single flash is

Eflash =

1
2

⋅ Cflash(V
2
flash,hi − V

2

flash,lo). | (32)

For the measured values Cflash = 1000 μF, Vflash,hi ≈ 10V , and Vflash,lo ≈ 8V , the energy per flash is

Eflash ≈

1
2

⋅ 1000 · 10

−6 ∗ (10

2 − 8

2
) = 0.5 ⋅ 10

−3
⋅ 36 ≈ 18 mJ. | (33)

Two flashes therefore remove roughly 36 mJ from the storage capacitor before it is recharged by the switched-capacitor network.

The instantaneous LED current is set by the voltage left across the series resistance. Approximating the LED as a 6,V drop and taking the series resistance to be dominated by the explicit 1,Ω resistor (the MOSFET on-resistance and LED dynamic resistance are much smaller), the peak current at the start of the pulse is

Iflash,pk ≈

Vflash,hi − VLED
Req

≈

10 − 6
1
≈ 4A, | (34)

and the current then decays as the capacitor discharges. The decay time constant of the flash is set by the same resistance and Cflash:
τ ≈ ReqCflash ≈ 1 · 1000 · 10
−6 ≈ 1ms, | (35)

so most of the visible light is produced in the first few hundred microseconds, consistent with the short, high-current flashes seen in measurement.

The finite energy in Cflash limits how many such flashes can be produced before the voltage collapses close to the LED forward voltage. If each flash has average current Iavg over duration tp

, the charge removed per flash is ΔQ = Iavgtp
, and the resulting voltage droop is

ΔV =

ΔQ

Cflash

=

Iavgtp

Cflash

. | (36)

After N identical flashes the total droop is NΔV , so the minimum capacitor voltage is Vflash,min = Vflash,hi − NΔV . To maintain a clearly visible flash the capacitor voltage must stay at least a few volts above the LED forward voltage; here a margin of Vmargin ≈ 2V is used, so Vflash,min > VLED + Vmargin ≈ 8V . This requirement bounds the number of flashes:

N <

Vflash,hi − Vflash,min
ΔV

=

[(Vflash,hi − Vflash,min)(Cflash)]
Iavgtp
. | (37)

Using Vflash,hi = 10V , Vflash,min = 8V , Cflash = 1000 μF, Iavg ≈ 3A, and a pulse width tp ≈ 0.3 ms gives

N <

(10 − 8) ⋅ 10

−3
3 ⋅ 0.3 ⋅ 10

−3

≈ 2.2, | (38)

so in practice only two short flashes can be delivered before the capacitor voltage falls too close to the LED forward voltage and the current (and brightness) collapse. Because the charge pump feeding Cflash can only supply a small average current from the 3,V input, the capacitor recharges slowly between flash events, keeping the additional average thermal load modest while still allowing high instantaneous flash current.

## 5 Modeling, Simulation, and Control Analysis

The MATLAB script boost_cc_led_PI_stable.m encodes the averaged boost plant, the sense path, and the PI controller, and simulates both frequency response and step behavior using the same parameters as the hardware design.

### 5.1 Small-signal boost model and transfer function

With state vector x = (iL

, vC)

T
and Rload =

Vout,nom

Iout,nom

, the ON and OFF subcircuits over a switching period yield matrices A1

, A2

and input vectors b1

, b2
:
A1 = (0, 0; 0, −

1
Rload ∗ C
), | (39)

A2 = (0, −

1
L

;

1
C

, −

1
Rload ∗ C
), | (40)

Averaging gives

A = DA1 + (1 − D)A2 = (0, −

1 − D
L

;

1 − D
C

, −

1
Rload ∗ C
). | (41)

Linearizing around (IL

, Vout,nom, D) and writing small perturbations ^iL , ^vC, ^d yields
̇ ^x = A^x + Bd^d, | (42)

with
Bd = (

Vout,nom
L

; −

IL
C
). | (43)

Selecting v̂C as the output,
Cv = (0, 1), | (44)
the duty-to-output transfer function is

Gvd(s) =

(V̂out(s))

d̂(s)

= Cv

(sI − A)

−1Bd
. | (45)

This simplifies to the canonical boost form

Gvd(s) =

Vout,nom
1 − D

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
Q∗ω0

+ 1

| , | (46)

with

ω0 =

1 − D
√
L ∗ C
, | | (47)

Q = (1 − D) ∗

Rload

√L
C
, | (48)

sz = Rload ∗

(1 − D)

2
L
, frhp = | sz
| 2 ∗ π
. | (49)

The numerical values used in the script (Vin = 3, V , Vout,nom = 6, V , Iout,nom = 1, A, L = 22, µH, C = 120, µH) match the design and set ω0

and frhp in the expected ranges.(Lee 2014a)

### 5.2 State-space model used in MATLAB

The script constructs A1, A2, A, and Bd exactly as above, with Rload = Vout_nom/Iout_nom and

D = 1 −

Vin

Vout,nom

. | (50)

The steady-state inductor current is computed as

IL =

Vin
Rload ∗ (1 − D)

2

, | (51)

and the duty-perturbation input is coded as Bd = (

Vout,nom
L

; −

IL
C
). | (52)

The current sense output is modeled by

Cvsense = (0,

Rsense ∗ Ksense,amp
Rload | ), | (53)

with

Ksense,amp =

1 Rsense ∗ Imax,real | , | (54)

so that 0–1.25 A corresponds to 0–1 V at Vmeas. This matches the 0–1 V hardware scaling.

### 5.3 PI controller mapping and augmented closed-loop system

The PI controller is implemented as

GPI(s) = Kp +

Ki
s
, | (55)

with an inverting op-amp mapping

Kp =

Rf
Rin

, Ki =

1
Rin ∗ Cf
. | (56)

In the script, representative values are
Rin = 10, kΩ, Rf = 680, Ω, Cf = 10, µF, | (57)
leading to modest Kp

and Ki
consistent with stability and the hardware values.

The augmented closed-loop state is xcl = (iL

, vC, z)

T
, | (58)
where z is the integrator state. With normalized PWM gain Kpwm = 1, the closed-loop matrices are
Acl = (A − BdKpKpwmCvsense, BdKiKpwm; −Cvsense, 0), | (59)
Bcl = (BdKpKpwm; 1), | (60)

with output matrices
Cy = (Cvsense, 0), Dcl = 0, | (61)

for Vmeas, and

Ci =

Cy

Rsense ∗ Ksense,amp

, | (62)

for ILED. The MATLAB systems sysvsense = ss(Acl, Bcl, Cy

, Dcl), | (63)

sysiout = ss(Acl, Bcl, Ci

, Dcl), | (64)
are used for Bode and time-domain plots.

### 5.4 Frequency response and loop properties

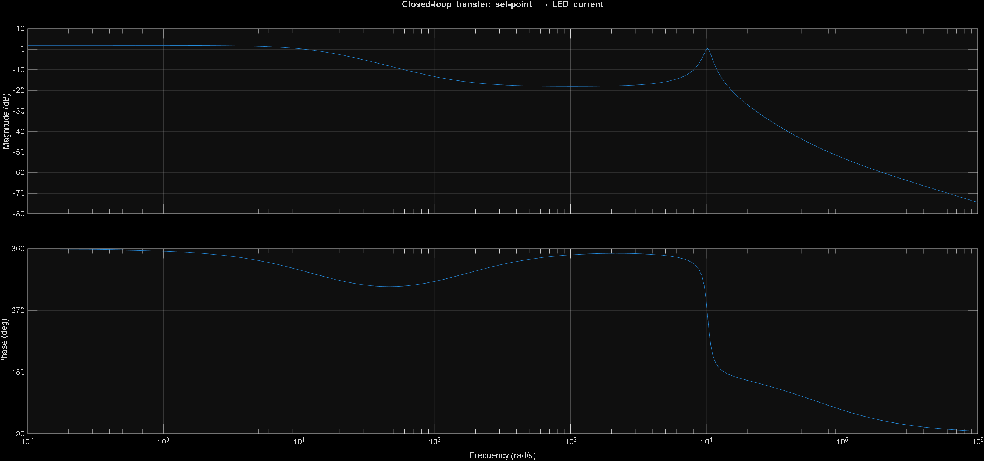
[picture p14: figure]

Figure 5: Plot of simulated Bode transfer functions from setpoint to measured voltage and LED current

The Bode plot of sys_iout (setpoint → LED current) shows a crossover frequency in the low-kilohertz range, well below both frhp and fsw
10

, and a phase margin around 50–60°. This matches the TI loop design guidelines and the qualitative goals stated earlier: low-frequency gain for good current regulation, and enough phase margin for a well-damped step response.(Lee 2014a; 2014b)

### 5.5 Step-response simulation

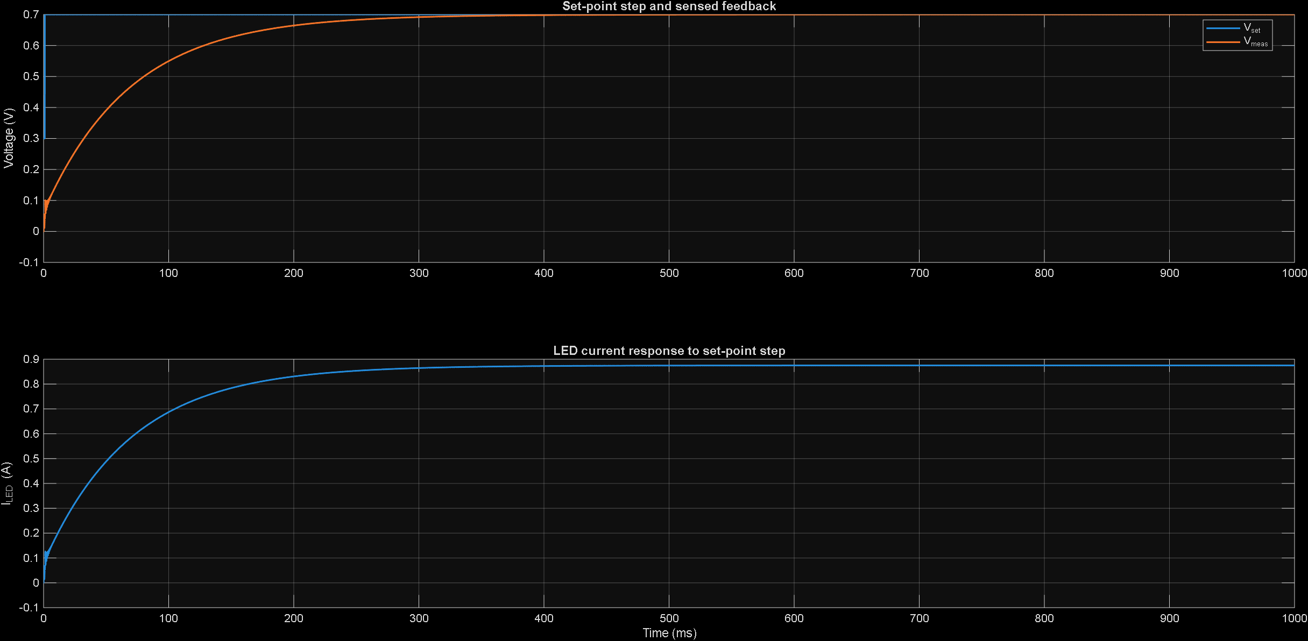
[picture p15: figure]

Figure 6: Plot of simulated step response in LED current and measured voltage

The script simulates a step in Vset from 0.3 V to 0.7 V at t = 1, ms and uses lsim to compute Vmeas and I_LED. The responses show the sensed voltage tracking the setpoint with small steady-state error and the LED current moving smoothly to the new level with modest overshoot and settling within a few milliseconds. This behavior is consistent with the Bode analysis and provides a reference for interpreting the measured scope waveforms in the hardware section.

## 6 Hardware Implementation and Measurement Setup

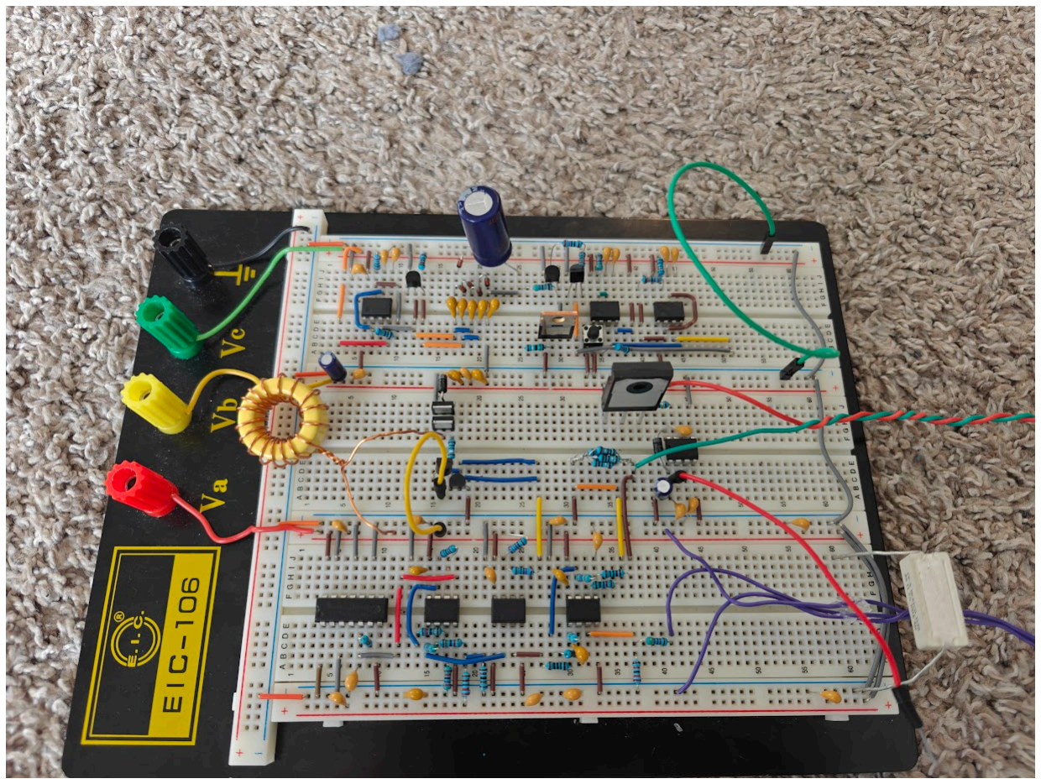
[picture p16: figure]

Figure 7: Photograph of prototype hardware setup

The prototype was built on a breadboard using the discrete boost stage and control loop from figure 3. The layout was chosen to keep the high di/dt loops compact and to expose key internal nodes for probing:

- Switch node (inductor diode switch junction),
- LED cathode (for measuring output ripple),
- Sense amplifier output Vmeas,
- Setpoint Vset,
- PI output Vctrl,
- Triangle ramp Vtri.

The 3 V input was provided by a bench supply configured to emulate a fresh pair of alkaline cells. A second channel supplied gate-drive / comparator logic during early bring-up; in the final configuration the LM358 and comparator run directly from the same 3 V rail as the power stage.

A digital oscilloscope with 10× probes was used for all waveforms. To reduce loop inductance in the high-frequency current paths, the inductor, diode, and switch device were clustered physically near each other, and short ground returns were used for both the input and output capacitors. The 0.2 Ω sense resistor was mounted with short Kelvin connections to the sense amplifier to minimize error from trace resistance.

Before closing the loop, the following incremental tests were performed:

- Open-loop switching of the boost stage at ≈100 kHz with fixed duty cycle, verifying expected duty/voltage relation and switch-node waveform.
- Standalone verification of the triangle generator (Vtri) and comparator behavior, confirming clean, monotonic PWM.
- DC transfer of the sense path (LED current → Vmeas) and setpoint path (Vset), verifying that both span 0–1 V over the intended current range.

Only after these blocks matched the model was the PI controller closed around the current sense to form a complete LED driver.

### 6.1 Implementation Challenges

During the bring-up phase, several challenges were encountered that required design iterations:

1. Noise on the Sense Line: Initially, the switching noise from the main boost loop coupled into the high-impedance input of the current sense op-amp, causing the PWM to jitter. This was resolved by adding a small R-C low-pass filter (100Ω, 1nF) at the op-amp input and improving the ground layout to separate the power ground from the signal ground.
2. Comparator Hysteresis: The comparator initially triggered multiple times on the noisy triangle wave peaks. A small amount of hysteresis was added via a positive feedback resistor to ensure clean switching transitions.

## 7 Experimental Results and Comparison to Simulation

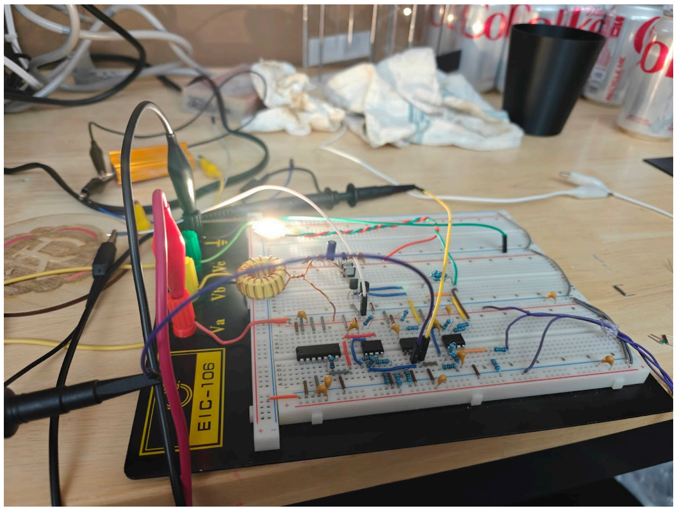
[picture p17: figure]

Figure 8: Photograph of prototype flashlight driver in operation

This section summarizes the key measured waveforms and compares them qualitatively to the MATLAB simulations of Section 5. Scope plots are referred to by figure number; each was captured at the nominal operating point with Vin ≈ 3V and the LED current in the 1–1.5 A range.

### 7.1 Operating point and steady-state waveforms

In steady state, with the setpoint adjusted to a mid-range value, the measured LED current (via the 0.2 Ω shunt) is on the order of 1 A and the output voltage approximately 6–6.5 V, consistent with the design. The switch-node waveform (not explicitly shown here but observed) shows the expected boost behavior: during the on-time the switch node is near ground; during the off-time it rises above the output voltage as the inductor current commutates through the diode.

Figure 10 shows the key signals for the PWM generation: the PI controller’s output voltage (Vctrl) (blue), which is nearly a DC level in steady-state, is compared against the sawtooth/ triangle wave (yellow). The intersection of these two signals determines the switch’s turn-off point.

The resulting gate drive signal (duty cycle) is shown in Figure . The measured duty cycle at this operating point is close to the predicted D ≈ 0.5 from

D = 1 −

Vin

Vout

. | (65)

The inductor current, reconstructed from the shunt voltage and sense gain, shows triangular ripple consistent with the 0.7 A peak-to-peak value predicted in Section 4 (actual inductor current is not shown in the figures).

The output voltage ripple is small (tens of millivolts) and primarily high-frequency, confirming that the chosen 120µF capacitance is sufficient for both LED visual performance and small-signal modeling assumptions.

—

### 7.2 Setpoint step response

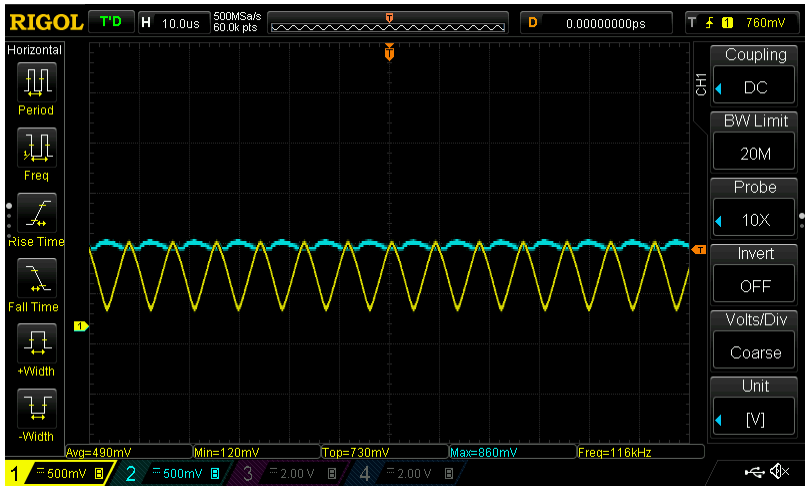
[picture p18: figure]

Figure 9: Waveform capture of the Pulse Width Modulation (PWM) generator signals. Blue (Channel 2) is the PI controller output Vctrl (the control voltage), and yellow (Channel 1) is the triangle wave (ramp signal) at 100 “kHz”.

A key test is the response to a step in Vset. On the bench, the setpoint was changed by adjusting the potentiometer from a lower to a higher voltage command, roughly analogous to the 0.3 to 0.7 V step simulated in MATLAB.

The measured Vset, Vmeas, and LED current waveforms show:

- Vmeas tracks Vset with small steady-state error, confirming that the PI controller successfully drives the sensed current toward the reference.
- The LED current exhibits a single, well-damped rise from its initial to final value, with modest overshoot and settling within a few milliseconds.
- The duty cycle increases smoothly during the transient; no subharmonic oscillations or sustained ringing near half the switching frequency were observed, which is consistent with the absence of a current-mode inner loop and the conservative choice of crossover frequency.

Qualitatively, the measured step response matches the MATLAB predictions: the simulated sysiout step in Section 5 shows a similar rise time, overshoot, and settling behavior. Small discrepancies (slightly slower settling and slightly higher overshoot on hardware) are attributable to LM358 finite bandwidth, comparator propagation delay, and nonideal ramp shape—effects that were neglected in the idealized averaged model.

### 7.3 Comparison of GaN vs Si switch behavior

GaN Gate Waveform | Si Gate Waveform

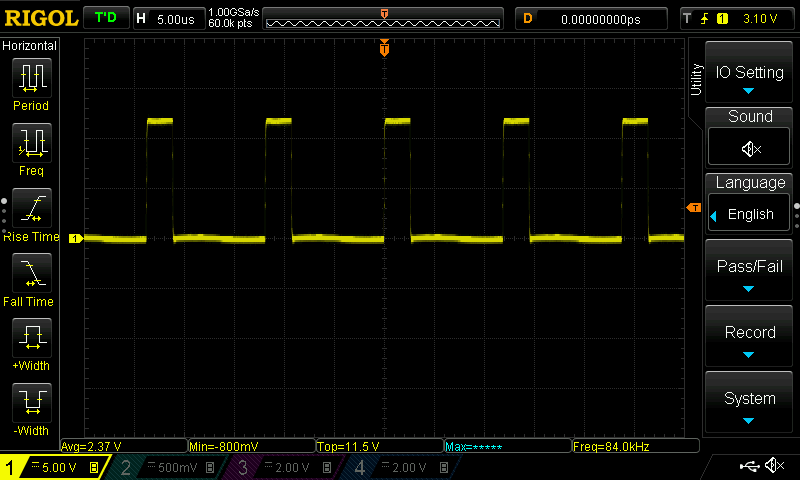
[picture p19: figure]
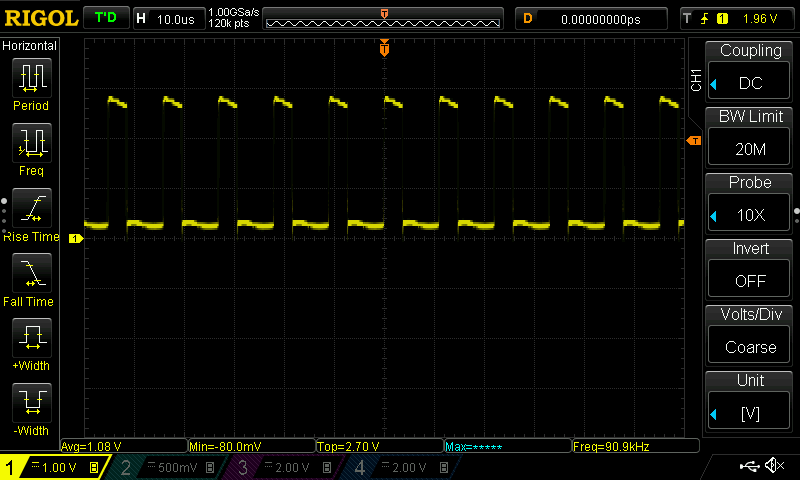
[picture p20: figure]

Table 1: Post-synthesis SAIF-based power breakdown at 10 ns.

When the silicon MOSFET was replaced with the GaN FET, the primary observable differences on the scope were:

- Faster switch-node transitions (shorter rise/fall times),
- Slightly reduced switching-node ringing due to lower charge storage,
- Lower device temperature for the same output current, consistent with the reduced conduction and switching losses discussed in Section 4.

At the relatively low 100 kHz switching frequency, both devices allowed the converter to reach the same operating point, but the GaN FET did so with noticeably less self-heating over a multi-minute run. This matches the loss-estimation trends and illustrates how even at a few volts and a few amps, device parasitics and transition speeds are important.

## 8 Energy-Flow and Graduate Extension Discussion

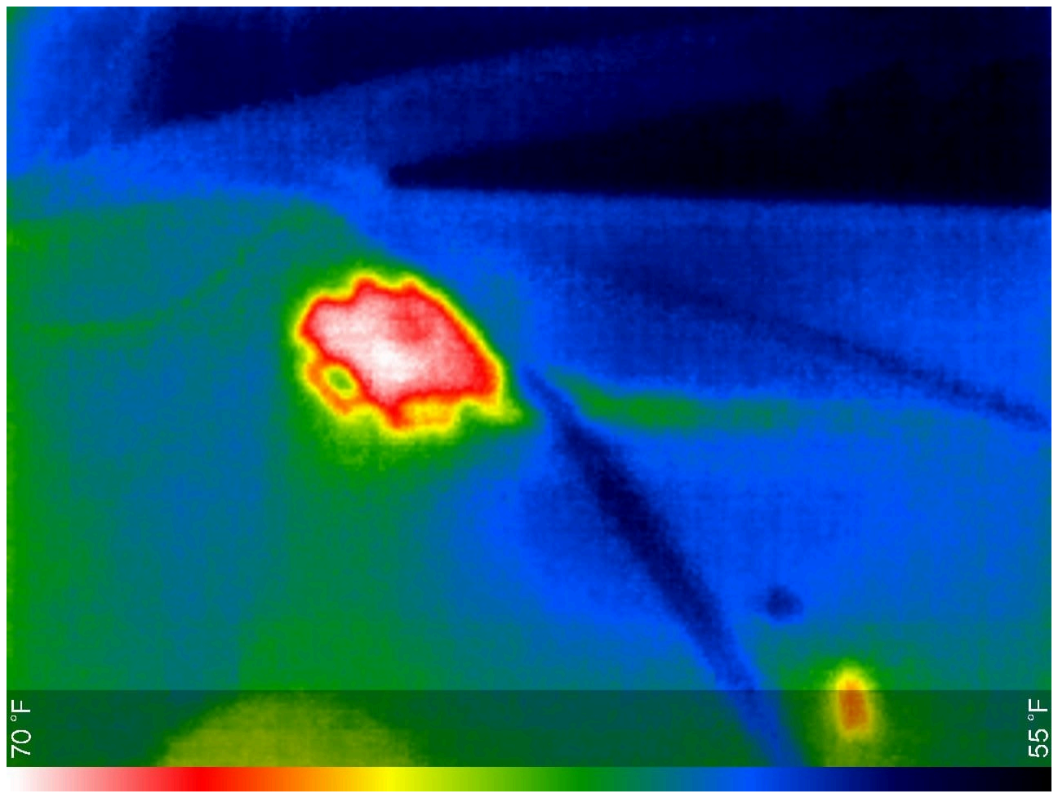
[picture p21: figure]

Figure 12: Thermal performance of LED

A central 6.2222 theme is energy conservation and Tellegen-style reasoning about networks. For the flashlight driver, it is natural to divide the steady-state input power into useful LED power and losses in individual elements. Figure 12 illustrates the measured thermal behavior of the LED: at the nominal operating point the LED case stabilizes near 70,°C, which is consistent with the expected electrical-to-thermal conversion and the measured optical output.

At a representative operating point, the input power is
Pin = Vin ∗ Iin, | (66)
the LED optical/electrical power is approximated by
PLED ≈ Vf ∗ ILED, | (67)
and the remainder is partitioned into conduction and switching losses in the switch, diode, inductor copper loss, control power, and sense resistor loss. Section 4 provided analytical estimates for the switch and shunt losses; qualitative thermal observations on the bench are consistent with those estimates (the shunt runs warm, the silicon MOSFET runs appreciably warmer than the GaN device).

From a Tellegen perspective, the averaged boost network plus control circuitry form a larger multiport network in which the sum over all branch power vk ∗ ik
is zero at each instant.
Integrating over a switching period and grouping terms by element yields
Pin = PLED + Pswitch + Pdiode + PL,loss + Psense + Pctrl, | (68)

where each term can be estimated either from measured currents and voltages or from datasheet parameters. The GaN vs Si comparison is naturally expressed in these terms: substituting a lower–Rds,on, faster device reduces Pswitch for fixed Pin, allowing either a higher PLED at the same thermal limit or a cooler-running converter for the same LED power.

The switched-capacitor flash extension can also be viewed through energy flow. Over a full charge–discharge cycle, the net energy delivered to the LED during the flash must be drawn from the 3 V input via the doubler network. The “equivalent resistance” of the doubler chain determines how much extra input power is needed to support repeated flashes, and Tellegen ensures that averaged over many cycles, this additional power appears as either extra LED optical output or additional losses in the charge pump elements.

## 9 Discussion and Conclusion

This project implemented and analyzed a discrete boost converter for a high-power LED, with emphasis on modeling, loop design, and energy-flow interpretation rather than purely maximizing flux. Starting from a 3 V “battery” and a 6 V Cree XHP50.3 LED, the design chose a 22 µH inductor, a 120 µF output capacitor, a 0.2 Ω sense resistor, and LM358-based current sense, PI control, and PWM generation to build a complete current-regulated driver.(Xlamp Xhp50.3 Leds 2025)

The independent inquiry into TI voltage-mode and current-mode boost controllers, together with Black’s feedback theorem and the 6.2222 reference material, provided a framework for choosing loop crossover frequency and PI parameters that respect the boost RHP zero and LC resonance.(Lee 2014a; 2014b) A small-signal averaged model was derived and encoded in MATLAB, and the resulting Bode plots and step responses matched the measured hardware behavior to first order. The main discrepancies were attributable to nonidealities intentionally omitted from the model (op-amp bandwidth limits, comparator delay, ramp distortion).

On the device side, comparing a silicon MOSFET to a GaN FET in the same topology highlighted that even in a “low-voltage” 3→6 V converter, parasitic resistances and transition times significantly affect efficiency and thermal performance. The GaN device reduced total switch loss by a factor of about two at 100 kHz, and the benefit would grow at higher frequency.

From a 6.2222 perspective, the project demonstrates how a familiar consumer object—a flashlight—can be used as a concrete platform for applying classical control, averaged converter modeling, energy-flow reasoning, and device-level loss analysis. Possible extensions include a PCB implementation with improved layout, a fully current-mode control scheme with slope compensation, closed-loop flash control using the switched-capacitor quadrupler, and more systematic efficiency measurements across load and input-voltage conditions.

## 10 Appendix section

### 10.1 Matlab Code Listing

%% boost_cc_led_PI_stable.m
% Small-signal averaged model of boost -> current sense -> PI -> PWM

clear; clc; close all;

%% ====== Power stage and sense parameters ===============================
Vin | = 3; | % V, battery
Vout_nom = 6; | % V, nominal LED voltage
Iout_nom = 1; | % A, nominal LED current (you can leave this)
L | = 22e-6;
C | = 120e-6;
fsw | = 100e3;
Rload | = Vout_nom / Iout_nom;
Rsense | = 0.2; | % Ohm, current-sense resistor
Imax_real | = 1.25; | % A, max LED current you see in hardware
K_sense_amp = 1/(Rsense * Imax_real); | % => 0..1 V for 0..1.25 A
% K_sense_amp = 4 in this case

%% ====== PI controller as hardware ===================================== % We implement: G_PI(s) = Kp + Ki/s
% with a series Rf-Cf in the feedback and an input resistor Rin:
% Kp = Rf/Rin, Ki = 1/(Rin*Cf)
Rin = 10e3; | % Ohm
Rf = 680; | % Ohm
Cf = 10e-6; | % F
Kp | = Rf / Rin;
Ki = 1/(Rin * Cf);

% (These values give roughly Kp = 0.5, Ki = 500 – stable for this plant.)

%% ====== Linearized CCM boost converter model =========================== % Steady-state
D | = 1 - Vin / Vout_nom; | % duty
V_o = Vout_nom;
I_o = V_o / Rload;
I_L = Vin / (Rload * (1-D)^2);
% ON: | diL/dt = Vin/L, dvC/dt = -vC/(R C)
A1 = [ 0, | 0;
0, | -1/(Rload*C) ];

% OFF: diL/dt = (Vin - vC)/L, dvC/dt = iL/C - vC/(R C)
A2 = [ 0, | -1/L;
1/C, | -1/(Rload*C) ];

% Duty-averaged A
A = D*A1 + (1-D)*A2;

% Duty perturbation input (Erickson/Maksimovic form) Bd = [ V_o / L;
-I_L / C ];

% Sense output: Vmeas = K_sense_amp * Rsense * i_out, i_out ≈ vC/Rload C_vsense = [0, (Rsense*K_sense_amp)/Rload]; % 1×2
D_vsense = 0;

%% ====== Build loop in state space (add PI integrator state) ============ K_pwm = 1; % normalized PWM gain (0–1 V triangle & control)

% States: [ x ; z ], x = [iL; vC], z = integrator state
% x_dot = A x + Bd*K_pwm*(Kp*(r - y) + Ki*z)
% z_dot = r - y, | y = C_vsense x
%
% => A_cl = [A - Bd*Kp*K_pwm*C, | Bd*Ki*K_pwm;
% | -C_vsense, | 0]
A_cl = [A - Bd*Kp*K_pwm*C_vsense, | Bd*Ki*K_pwm;
-C_vsense, | 0 | ];

B_cl = [Bd*Kp*K_pwm;
1 | ]; | % input is setpoint r
C_y | = [C_vsense, 0]; | % output y = Vmeas
C_i | = C_y / (Rsense * K_sense_amp); % LED current (A) from Vmeas

D_cl = 0;

% State-space systems
sys_vsense = ss(A_cl, B_cl, C_y, D_cl); | % Vmeas / Vset
sys_iout | = ss(A_cl, B_cl, C_i, D_cl); | % I_LED / Vset

%% ====== Check poles and frequency response ============================ fprintf('Closed-loop poles (Vset -> Vmeas):\n'); disp(pole(sys_vsense));

figure;
bode(sys_iout);
grid on;
title('Closed-loop transfer: set-point \rightarrow LED current');

%% ====== Time-domain step in set-point ==============================
t_end = 1000e-3; | % 5 ms total sim time
Ts | = 1e-5; | % 10 us sample time | << 1.2e-4 from warning
t | = 0:Ts:t_end; | % time vector
Vset_low | = 0.3;
Vset_high = 0.7;
t_step = 1e-3;

r = Vset_low * ones(size(t)); r(t >= t_step) = Vset_high;

[y_vsense, ~] = lsim(sys_vsense, r, t);
y_iout | = lsim(sys_iout, | r, t);

figure;
subplot(2,1,1);
plot(t*1e3, r, 'LineWidth', 1.5); hold on; plot(t*1e3, y_vsense, 'LineWidth', 1.5); ylabel('Voltage (V)');
legend('V_{set}','V_{meas}','Location','Best'); grid on;
title('Set-point step and sensed feedback');

subplot(2,1,2);
plot(t*1e3, y_iout, 'LineWidth', 1.5); xlabel('Time (ms)');
ylabel('I_{LED} (A)');
grid on;
title('LED current response to set-point step');

## Bibliography

[1] “XLamp XHP50.3 LEDs.” 2025.
[2] S. W. Lee, “Practical Feedback Loop Analysis for Voltage-Mode Boost Converter,” technical report SLVA633, 2014a.
[3] S. W. Lee, “Practical Feedback Loop Analysis for Current-Mode Boost Converter,” technical report SLVA636, 2014b.
[4] “RFD3055LE, RFD3055LESM N-Channel Logic Level Power MOSFET.” 2002.
[5] “GAN041–650WSB / GAN041–650WSBQ: 650 V, 35 m\ohm{} Gallium Nitride (GaN) FET in a TO-247 package.” 2024.

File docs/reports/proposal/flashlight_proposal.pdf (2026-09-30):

# Flashlight Project Proposal

Ahmad Taka
ahmadtak@mit.edu
MIT EECS

October 28, 2025

## 1 Summary

For my final project, I will design and build a compact, thermally-managed boost LED driver for a Cree XHP50.3 6V LED (XHP50D-00-0000-0D0UH240G). The goal is to create a highpowered flashlight that is practical for everyday use, bright enough to light up a workspace or driveway, but efficient and cool enough to hold comfortably. I’ve always liked the idea of having a personal, custom-built light that’s powerful yet portable, and I want to design the power electronics myself rather than rely on off-the-shelf flashlight drivers.

Over the summer, I prototyped the lipo and controller on an STM32 dev board I designed. It can charge a Li-ion cell, supply up to 3 A on a Power Path rail (Built using the BQ2125), and read an onboard accelerometer that I used to turn on an LED with a simple “shake-to-wake” gesture. I also tested several commercial boost drivers, including the TPS61169 and TPS61500, but they failed to deliver enough current to reach full LED brightness. That experience pushed me toward developing my own higher-power, constant-current driver architecture. The new design uses a boost converter that measures LED current through a shunt resistor and regulates it directly for consistent brightness and thermal performance. Initially for this project, it will run from 3 V to 4.3 V rail from a bench top power supply. The battery and digital control integration planned as a later extension once the converter stage is proven stable and thermally efficient.

For the graduate extension of the project, I plan to use Tellegen’s theorem to track how energy moves through the converter and confirm that the measured power losses match the theory. This approach will help ensure that every part of the circuit, from the switches to the inductor contributes predictably to the total energy flow, making it easier to identify where thermal improvements can be made. I also want to build a small switched capacitor voltage doubler to create short, high-voltage flashes on the LED and study how these quick bursts affect brightness and heat (Building on the work in Lab 3).

## 2 Hardware and System Diagram

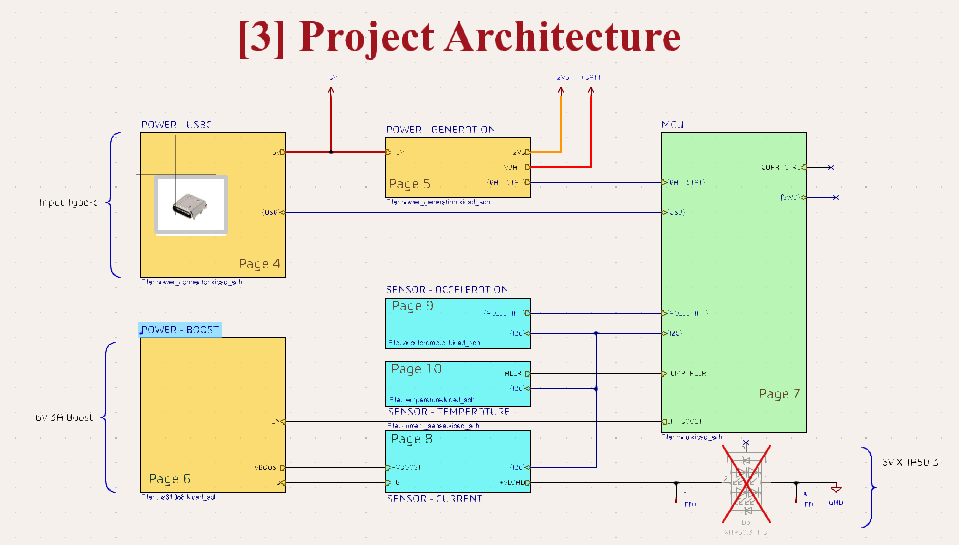
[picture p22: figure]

Figure 1: Block diagram of the flashlight system, showing power and control subsystems.

This block diagram outlines the overall flashlight system, including power input, sensing, and control subsystems. For the final project, the primary focus is on the Boost Converter block, shown as the section responsible for stepping up the voltage and providing constant-current regulation to drive the Cree XHP50.3 LED. The converter senses output current through a shunt resistor and feeds this information back to maintain stable LED brightness across varying input voltages.

This design is an initial draft architecture, where only the boost stage will be developed, tested, and characterized within the current project scope. Future integration with the STM32-based logic, sensors, and battery management circuitry will come later. A key part of this phase is evaluating whether GaN FETs or traditional silicon MOSFETs offer better performance in terms of thermal handling, switching frequency, and overall circuit footprint for the synchronous boost topology.

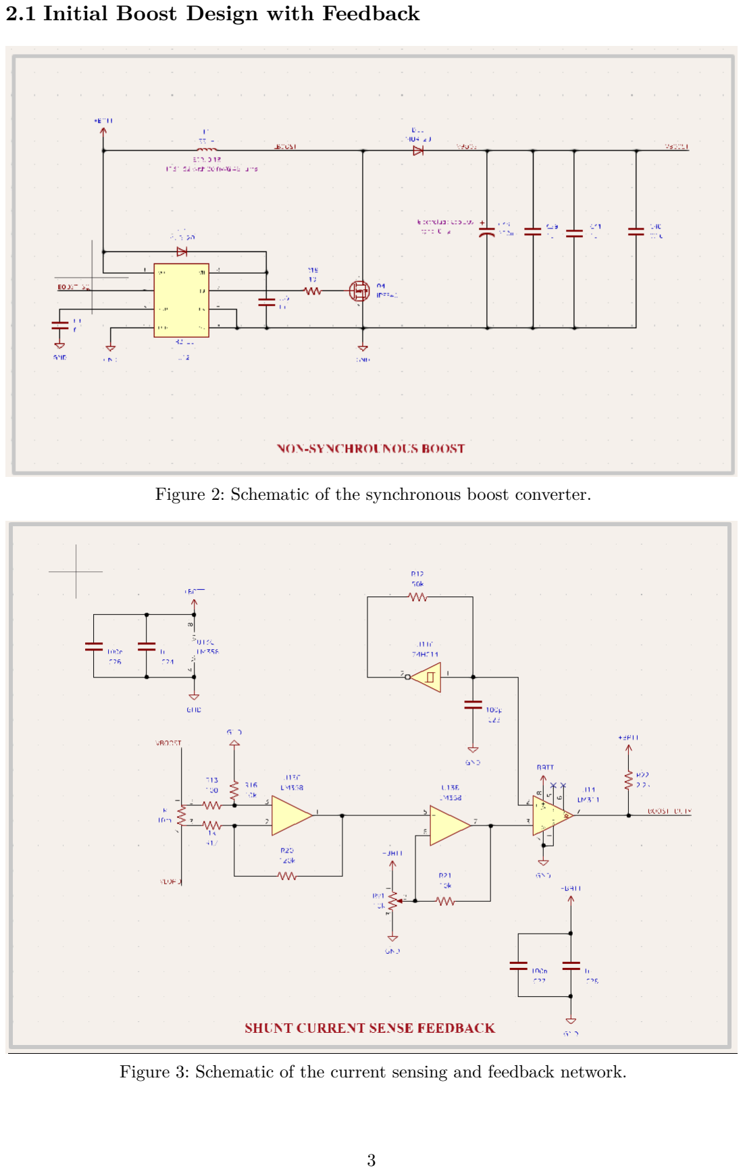
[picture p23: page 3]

### 2.1 Initial Boost Design with Feedback

Figure 2: Schematic of the synchronous boost converter.

Figure 3: Schematic of the current sensing and feedback network.

This initial design uses a version of the boost converter in Lab 2, a high-current, nonsynchronous boost converter, as the main power stage that steps the input voltage (3–4.3 V) up above the 5.6 V (forward-voltage) required by the Cree XHP50.3 LED. However unlike the lab, the conververter operates in current-mode control. The LED current is sensed through a high-side shunt resistor, whose voltage drop represents the real-time LED current. The high-side placement of the shunt allows for accurate current measurement without interfering with the LED ground reference.

That sense voltage feeds into a dual op-amp circuit configured as a differential amplifier and comparator. The amplifier conditions the shunt voltage and compares it against a reference voltage generated by a potentiometer. By adjusting the potentiometer, the reference voltage changes, effectively controlling the output current setpoint. The op-amp’s output is routed through a variable duty cycle control circuitry where the duty cyvle can range from 0.5 to 0.85 to maintain the desired LED current.

In summary, the system forms a closed-loop constant-current boost converter, where the boost stage supplies the main power conversion, and the op-amp plus digital potentiometer network provides adjustable current regulation.

### 2.2 GaN Vs Tradional FETs

GaN lets you push 3× higher switching frequency, which cuts L or output cap size by 3× and lowers total FET heat at this power. Silicon at lower fSW pays more in switching and gate-drive loss, so even with similar RDS(on), total FET loss is higher. Although not a fair comparison the table below shows how a QFN GaN Chip (EPC2302) stacks up against a larger, older Si FET (IRF540N) in this application. Estimates below isolate the power switches only and ignores how the gate is driven.

Parameter | Si FET (IRF540N) | GaN FET (EPC2302)
fSW (MHz) | 0.4 | 1.2
L (µH), Vin=3.3V | 2.27 | 0.76
RDS(on) (mΩ) | 44 | 3.8
Qg·Vg (nC·V) | 630 | 40
Switching (W) | 0.79 | 0.12
Gate-drive loss (W) | 0.50 | 0.10
Total loss (W) | 1.29 | 0.22
Size note | Baseline | 3× smaller L/C

Table 1: Table comparing estimated losses and component sizes between Silicon and GaN FETs in the boost converter application.

## 3 Special Components and BOM

TC4426 High-speed Low side driver for the GaN FET.

Current-sense shunt R1 = 10 mΩ Sets LED current for the op-amp loop. Requires Kelvin sense.

Part | Quantity | Price $
TC4426 (Sync Boost IC, U6) | 1 | 2.20
Shunt Resistor 10 mΩ (R1) | 1 | 0.54
EPC2302 eGaN FET | 10 | 34.58
INA180A1 (Current-Shunt Amp, U8) | 1 | -
Cree XHP50.3 HD 6 V LED (D3) | 5 | 37.95

Table 2: Bill of materials excerpt highlighting the essential boost IC, sense shunt, GaN option (EPC2302), and notable system parts used in the flashlight driver

## 4 Project Scope and Management

For this project, I will focus on designing, building, and testing the boost converter stage with constant-current feedback to drive the Cree XHP50.3 LED. I will also design two other supplies to explore the use of alternate power converters. The first is the same boost topology however with GaN FETts to compare performance and thermal characteristics against the traditional silicon FET design. The second is a small switched-capacitor voltage doubler to create high-voltage pulses for the LED, building on the switched-capacitor concepts from Lab 3.

In the first phase, I’ll build a basic prototype using the Totem Board from Lab 4 and a 250 kHz switching circuit with current feedback, implemented entirely in analog. This setup will build directly on the work from Lab 3, where I developed and tested the fundamental switching and sensing stages. The goal is to verify that the constant-current feedback loop operates as expected before integrating the full boost converter. Once the analog prototype is stable, I’ll measure temperature rise and efficiency across different loads and input voltages to guide the final design.

In the second phase, I’ll build a GaN-based version of the boost converter to compare performance. Using GaN FETs should allow higher switching frequencies, reducing inductor/ capacitor size and improving thermal performance. I’ll follow a similar testing procedure to evaluate efficiency and heat dissipation.

Finally, I’ll design and test a switched-capacitor voltage doubler to create short, high-voltage pulses for the LED. This stage will explore how pulsed operation affects brightness and thermal characteristics, building on the switched-capacitor concepts from Lab 3.

## 5 Timetable

- Week starting Nov 10: Lock in Schematic and design choices. Finalize BOM and order parts (DONE).
- Week starting Nov 17: Began modeling and circuit construction (IN PROGRESS).
- Week starting Nov 24: Design mechanical enclosure. Make GaN version and switchcap version.
- Week starting Dec 1: Test Boards and integrate into system.

- Week starting Dec 8: Show off flashlight.

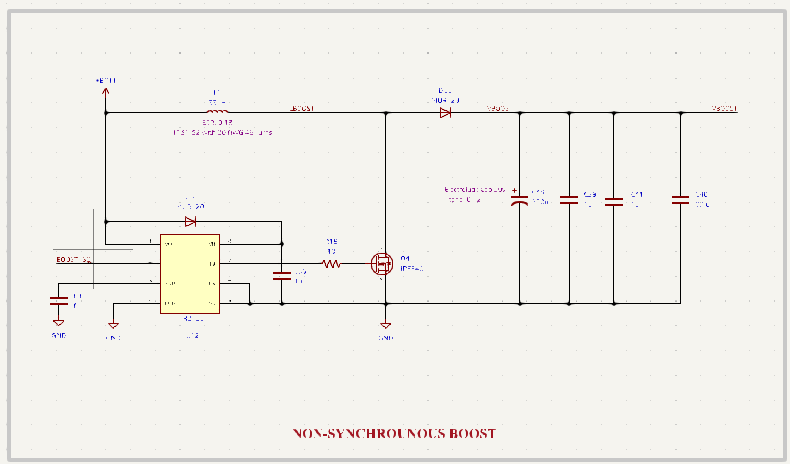
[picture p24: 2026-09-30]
docs/reports/proposal/figures/boost.png

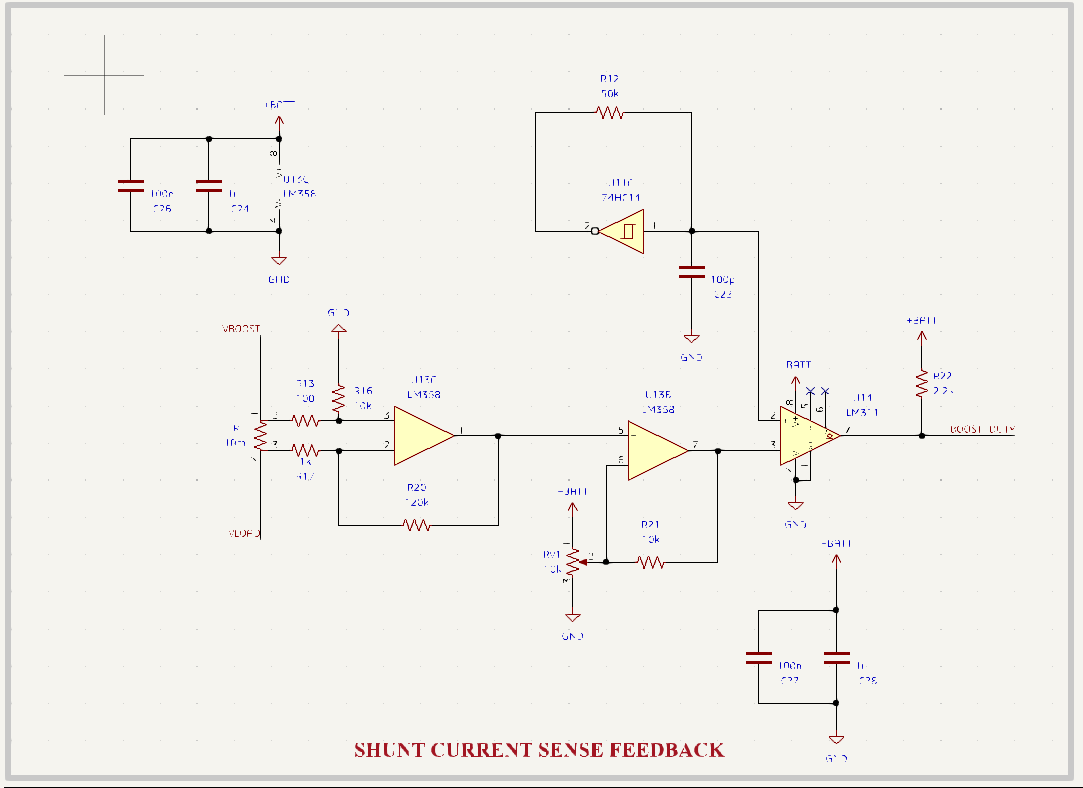
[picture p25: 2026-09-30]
docs/reports/final_report/figures/3_3_current_sense.png

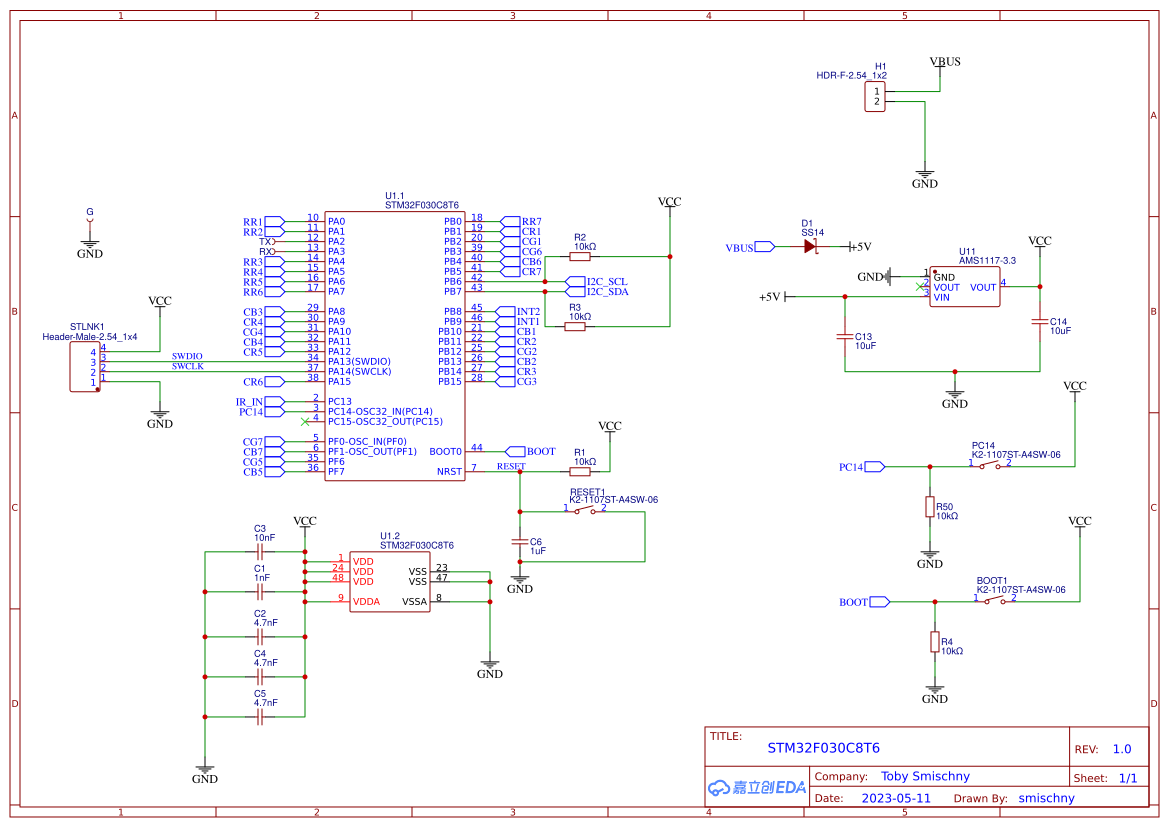
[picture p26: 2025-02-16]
electrical/flashlight-hardware/docs/reference-design-stm32.png

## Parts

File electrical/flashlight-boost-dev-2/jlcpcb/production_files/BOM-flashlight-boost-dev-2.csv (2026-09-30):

Comment | Designator | Footprint | LCSC | Quantity
1u | C5 | C_0603_1608Metric_Pad1.08x0.95mm_HandSolder | C15849 | 1
47n | C3 | C_0603_1608Metric_Pad1.08x0.95mm_HandSolder | C1622 | 1
470n | C4 | C_0603_1608Metric_Pad1.08x0.95mm_HandSolder | C1623 | 1
10uH | L1 | L_10.4x10.4_H4.8 | C171589 | 1
4.7u | C1 | C_0603_1608Metric_Pad1.08x0.95mm_HandSolder | C19666 | 1
150k | R1 | R_0603_1608Metric_Pad0.98x0.95mm_HandSolder | C22807 | 1
51k | R4 | R_0603_1608Metric_Pad0.98x0.95mm_HandSolder | C23196 | 1
10k | R2 | R_0603_1608Metric_Pad0.98x0.95mm_HandSolder | C25804 | 1
60V 3A | D1 | DIOM7959X262N | C35722 | 1
400m | R3 | R_0603_1608Metric_Pad0.98x0.95mm_HandSolder | C57344 | 1
TPS61500PWPR | U1 | IC_TPS27S100BPWPR | C71160 | 1
10u | C2 | C_0603_1608Metric_Pad1.08x0.95mm_HandSolder | C96446 | 1

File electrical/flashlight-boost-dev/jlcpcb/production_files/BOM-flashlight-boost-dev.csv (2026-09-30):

Comment | Designator | Footprint | LCSC | Quantity
1u | CU12 | C_0603_1608Metric | C15849 | 1
4.7u | CU11,CU13 | C_0805_2012Metric_Pad1.18x1.45mm_HandSolder | C1779 | 2
0.5 | RU11 | R_1206_3216Metric_Pad1.30x1.75mm_HandSolder | C25340 | 1
WE-MAPI_4030 | LU11 | WE-MAPI_4030 | C6707914 | 1
TPS61169DCKR | U1 | SOT65P210X110-5N | C71045 | 1
NSR0240P2T5G | DU11 | SOD-923 | C896425 | 1

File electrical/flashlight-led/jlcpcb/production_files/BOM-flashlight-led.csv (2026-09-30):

Comment | Designator | Footprint | LCSC | Quantity
GND | J3 | TestPoint_THTPad_D3.0mm_Drill1.5mm |  | 1
GND | J2 | TestPoint_THTPad_D3.0mm_Drill1.5mm |  | 1
+18V | J1 | TestPoint_THTPad_D3.0mm_Drill1.5mm |  | 1
LED_WARM | D1 | JR5050CWTEB30EB0000N0000001 |  | 1
LED_WARM | D2 | JR5050CWTEB30EB0000N0000001 |  | 1
LED_WARM | D3 | JR5050CWTEB30EB0000N0000001 |  | 1

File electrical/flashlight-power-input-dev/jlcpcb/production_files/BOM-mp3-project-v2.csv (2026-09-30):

Comment | Designator | Footprint | LCSC | Quantity
600 @100MHz | FB1,FB2 | L_0603_1608Metric | C1002 | 2
PAM8302AADCR | U10 | SOP-8_L4.9-W3.9-P1.27-LS6.0-BL | C112137 | 1
NC7WZ16P6X | U9 | SC-70-6_L2.2-W1.3-P0.65-LS2.1-BR | C114148 | 1
1k | RS11,RS21,RY11 | R_0402_1005Metric | C11702 | 3
100n | CU45 | C_0402_1005Metric | C1525 | 1
33p | CY11,CY12 | C_0402_1005Metric | C1562 | 2
1u | CU101,CU102,CU106,CU44,CU74 | C_0603_1608Metric | C15849 | 5
SMF05CT1G | U6 | SOT65P210X110-6N | C15879 | 1
220p | CU103,CU104 | C_0603_1608Metric | C1603 | 2
TYPE-C-31-M-12 | J1 | USB-C_SMD-TYPE-C-31-M-12 | C165948 | 1
47u | CU93,CU95 | C_0805_2012Metric | C16780 | 2
27 | RU11,RU12 | R_0805_2012Metric | C17594 | 2
4.7u | CU41,CU42,CU46,CU47 | C_0603_1608Metric | C19666 | 4
10u | CJ21,CU31,CU32,CU43,CU51,CU52,CU81,CU82 | C_0603_1608Metric | C19702 | 8
BQ25185DLHR | U4 | SON40P220X200X80-11N | C19725033 | 1
RP2040 | U1 | QFN-56-1EP_7x7mm_P0.4mm_EP3.2x3.2mm | C2040 | 1
13k | RU45 | R_0603_1608Metric | C22797 | 1
RED | D1 | LED_0603_1608Metric | C2286 | 1
300 | RU46 | R_0603_1608Metric | C23025 | 1
470 | RD21,RD22 | R_0603_1608Metric | C23179 | 2
2.2u | CU71 | R_0603_1608Metric | C23630 | 1
100 | RU92,RU95 | R_0402_1005Metric | C25076 | 2
220 | RU91,RU94 | R_0402_1005Metric | C25091 | 2
470 | RD11 | R_0402_1005Metric | C25117 | 1
10K | RU13,RU14,RU15,RU17,RU18,RU19,RU42 | R_0402_1005Metric | C25744 | 7
10k | RJ27,RU44,RU72 | R_0603_1608Metric | C25804 | 3
47k | RJ21,RJ22,RJ23,RJ24,RJ25,RJ26 | R_0603_1608Metric | C25819 | 6
5.1k | RJ11,RJ12 | R_0402_1005Metric | C25905 | 2
LTST-S310F2KT | D2 | LED-SMD_4P-L3.2-W1.5_LTST-S310F2KT | C284950 | 1
TLV733285PDBV | U3,U8 | SOT-23-5 | C2860615 | 2
100n | CBT11,CU11,CU12,CU17,CU18,CU21,CU72,CU91,CU92,CU94 | C_0402_1005Metric | C307331 | 10
BOOT | S1,S2 | TS1187ABAB | C318884 | 2
1.8k | RU93,RU96 | R_0603_1608Metric | C4177 | 2
Micro_SD_Card_Det2 | J2 | TF-008 | C428465 | 1
BQ27220YZFR | U7 | DSBGA-9_L1.7-W1.6-R3-C3-P0.50-BL | C528617 | 1
1u | CBT12,CU110,CU111,CU13,CU14,CU15,CU16,CU19 | C_0402_1005Metric | C52923 | 8
XC6206PxxxMR | U5 | SOT-23-3 | C5446 | 1
10m | RU71 | R_1206_3216Metric | C7467248 | 1
2N7002 | Q1,Q2 | SOT-23 | C8545 | 2
Crystal_GND24 | Y1 | Crystal_SMD_Abracon_ABM8G-4Pin_3.2x2.5mm | C9002 | 1
10u | CU105 | C_0603_1608Metric | C96446 | 1
W25Q128JVS | U2 | SOIC-8_5.3x5.3mm_P1.27mm | C97521 | 1

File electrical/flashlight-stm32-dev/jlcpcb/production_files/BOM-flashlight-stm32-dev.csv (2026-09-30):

Comment | Designator | Footprint | LCSC | Quantity
MMA8452QR1 | U3 | PQFN50P300X300X100-16N | C11360 | 1
LED_BARG | D1 | LED-SMD_4P-L1.6-W1.6-BR-RD | C114830 | 1
8mHz 20pf | YU22 | Crystal_SMD_5032-2Pin_5.0x3.2mm | C115962 | 1
100n | CU210 | C_0603_1608Metric_Pad1.08x0.95mm_HandSolder | C14663 | 1
100n | CSW11,CU13,CU15,CU23,CU24,CU25,CU26,CU27,CU29,CU32,CU33 | C_0402_1005Metric | C1525 | 11
8p | CY11,CY12 | C_0402_1005Metric | C1578 | 2
1u | CU12,CU28 | C_0603_1608Metric | C15849 | 2
SMF05CT1G | U6 | SOT65P210X110-6N | C15879 | 1
BQ25185DLHR | U1 | SON40P220X200X80-11N | C19725033 | 1
0 | RU33,RY11,RY21 | R_0603_1608Metric_Pad0.98x0.95mm_HandSolder | C21189 | 3
13k | RU11 | R_0603_1608Metric_Pad0.98x0.95mm_HandSolder | C22797 | 1
RED | D2,D3,D4,D5 | LED_0603_1608Metric | C2286 | 4
374 | RU12 | R_0603_1608Metric_Pad0.98x0.95mm_HandSolder | C23149 | 1
100 | RQ12,RQ22,RQ32,RSW22,RSW32 | R_0402_1005Metric | C25076 | 5
220 | RD11,RD12,RD13,RD21,RD31,RD41,RD51 | R_0402_1005Metric | C25091 | 7
10k | RQ11,RQ21,RQ31,RSW21,RSW31,RU13,RU14,RU15,RU31,RU32 | R_0402_1005Metric | C25744 | 10
5.1k | RJ12 | R_0402_1005Metric | C25768 | 1
10k | RU16 | R_0603_1608Metric_Pad0.98x0.95mm_HandSolder | C25804 | 1
5.1k | RJ11 | R_0402_1005Metric | C25905 | 1
BOOT | SW2 | 2182LPSTR | C2961921 | 1
RESET | SW1 | TS1187ABAB | C318884 | 1
USB_C_Receptacle | J1 | AMPHENOL_12401832E402A | C464604 | 1
1u | CU14,CU17 | C_0402_1005Metric | C52923 | 2
MCP1703Ax-120xxTT | U4,U5 | SOT-23_Handsoldering | C5446 | 2
20p | CY21,CY22 | C_0402_1005Metric | C76959 | 2
2N7002H | Q1,Q2,Q3 | SOT-23_Handsoldering | C8545 | 3
STM32L151C8Tx | U2 | LQFP-48_7x7mm_P0.5mm | C95578 | 1
32.768 kHz 9pf | YU21 | Crystal_SMD_2012-2Pin_2.0x1.2mm | C96341 | 1
10u | CU11,CU16,CU22,CU31,CU41,CU42,CU51,CU52 | C_0603_1608Metric | C96446 | 8

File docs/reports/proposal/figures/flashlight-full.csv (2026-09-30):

Reference | Value | Footprint | Datasheet | Qty | DNP
BT1 | 21700 5000mah | BISTOOK_BATTERY_HOLDER_21700:BISTOOK_BATTERY_HOLDER_21700 | ~ | 1
CBT11,CSW11,CU1,CU2,CU3,CU45,CU53,CU66,CU67,CU611 | 100n | Capacitor_SMD:C_0402_1005Metric,Capacitor_SMD:C_0603_1608Metric | ~ | 10
CBT12,CU5,CU41,CU44,LU61 | 1u | Capacitor_SMD:C_0402_1005Metric,Capacitor_SMD:C_0603_1608Metric,Inductor_SMD:L_Sunlord_MWSA0603S | ~ | 5
CU6,CU31,CU32,CU42,CU43,CU52 | 10u | Capacitor_SMD:C_0603_1608Metric | ~ | 6
CU62,CU63,CU612 | 47u | Capacitor_SMD:C_1210_3225Metric | ~ | 3
CU64 | 2.2u | Capacitor_SMD:C_0603_1608Metric | ~ | 1
CU65 | 47p | Capacitor_SMD:C_0603_1608Metric | ~ | 1
CU68 | 47n | Capacitor_SMD:C_0603_1608Metric | ~ | 1
CU71 | 100P | Capacitor_SMD:C_0603_1608Metric | ~ | 1
CU101 | 10n | Capacitor_SMD:C_0402_1005Metric | ~ | 1
CY11,CY12 | 20p | Capacitor_SMD:C_0402_1005Metric | ~ | 2
D1,D2 | RED | LED_SMD:LED_0603_1608Metric | ~ | 2
D3 | XHP50.3_HD | LED_SMD:LED_Cree-XHP50_6V | http://www.cree.com/%7E/media/Files/Cree/LED%20Components%20and%20Modules/XLamp/Data%20and%20Binning/ds%20XHP50.pdf | 1 | DNP
J1 | USB_C_Receptacle | 12401832E402A:AMPHENOL_12401832E402A | https://www.usb.org/sites/default/files/documents/usb_type-c.zip | 1
J2 | LED+ | Connector_Wire:SolderWire-0.25sqmm_1x01_D0.65mm_OD2mm | ~ | 1
J3 | LED- | Connector_Wire:SolderWire-0.25sqmm_1x01_D0.65mm_OD2mm | ~ | 1
RD1,RD2 | 470 | Resistor_SMD:R_0402_1005Metric | ~ | 2
RJ11,RJ12 | 5.1k | Resistor_SMD:R_0402_1005Metric | ~ | 2
RSW21 | 1000k | Resistor_SMD:R_0402_1005Metric | ~ | 1
RSW22,RU41,RU42,RU43,RU44 | 10k | Resistor_SMD:R_0402_1005Metric,Resistor_SMD:R_0603_1608Metric_Pad0.98x0.95mm_HandSolder | ~ | 5
RU11,RU12,RU64,RU101 | 4.7k | Resistor_SMD:R_0402_1005Metric,Resistor_SMD:R_0603_1608Metric_Pad0.98x0.95mm_HandSolder | ~ | 4
RU45 | 13k | Resistor_SMD:R_0603_1608Metric_Pad0.98x0.95mm_HandSolder | ~ | 1
RU46 | 300 | Resistor_SMD:R_0603_1608Metric_Pad0.98x0.95mm_HandSolder | 375 | 1
RU53 | 0 | Resistor_SMD:R_0603_1608Metric_Pad0.98x0.95mm_HandSolder | ~ | 1
RU61 | 470k | Resistor_SMD:R_0603_1608Metric_Pad0.98x0.95mm_HandSolder | ~ | 1
RU62 | 118k | Resistor_SMD:R_0603_1608Metric_Pad0.98x0.95mm_HandSolder | ~ | 1
RU63 | 24k | Resistor_SMD:R_0603_1608Metric_Pad0.98x0.95mm_HandSolder | ~ | 1
RU65 | 110k | Resistor_SMD:R_0603_1608Metric_Pad0.98x0.95mm_HandSolder | ~ | 1
RU66 | 270k | Resistor_SMD:R_0603_1608Metric_Pad0.98x0.95mm_HandSolder | ~ | 1
RU71 | 10K | Resistor_SMD:R_0603_1608Metric_Pad0.98x0.95mm_HandSolder | ~ | 1
RU72 | 50 | Resistor_SMD:R_0603_1608Metric_Pad0.98x0.95mm_HandSolder | ~ | 1
RU81 | 10m |  | ~ | 1
SW1 | RESET | TS-1187A-B-A-B:TS1187ABAB | ~ | 1
SW2 | BOOT0 | TS-1187A-B-A-B:TS1187ABAB | ~ | 1
TP1 | STAT1 | TestPoint:TestPoint_Pad_D1.0mm | ~ | 1
TP2 | STAT2 | TestPoint:TestPoint_Pad_D1.0mm | ~ | 1
TP3 | INT1 | TestPoint:TestPoint_Pad_D1.0mm | ~ | 1
TP4 | INT2 | TestPoint:TestPoint_Pad_D1.0mm | ~ | 1
TP5 | VSENSE | TestPoint:TestPoint_Pad_D1.0mm | ~ | 1
TP6 | FB | TestPoint:TestPoint_Pad_D1.0mm | ~ | 1
TP7 | EN_BOOST | TestPoint:TestPoint_Pad_D1.0mm | ~ | 1
TP8 | TEMP_ALERT | TestPoint:TestPoint_Pad_D1.0mm | ~ | 1
TP9 | CURR_CTRL | TestPoint:TestPoint_Pad_D1.0mm | ~ | 1
U1 | STM32F070F6Px | Package_SO:TSSOP-20_4.4x6.5mm_P0.65mm | https://www.st.com/resource/en/datasheet/stm32f070f6.pdf | 1
U2 | SMF05CT1G | SMF05CT1G:SOT65P210X110-6N |  | 1
U3 | MCP1700x-250xxTT | Package_TO_SOT_SMD:SOT-23-3 | http://ww1.microchip.com/downloads/en/DeviceDoc/20001826D.pdf | 1
U4 | BQ25185DLHR | BQ25185DLHR:SON40P220X200X80-11N | https://www.ti.com/lit/ds/symlink/bq25185.pdf?ts=1706857561339 | 1
U5 | MMA8452QR1 | MMA8452QR1:PQFN50P300X300X100-16N |  | 1
U6 | TPS61088RHLR | TPS61088:IC_TPS61088RHLR |  | 1
U7 | LTC721XT5/R6 | LTC721XT5R6:SOT-23-5_L2.9-W1.6-P0.95-LS2.8-BL |  | 1
U8 | INA180A1 | Package_TO_SOT_SMD:SOT-23-5 | http://www.ti.com/lit/ds/symlink/ina180.pdf | 1
U9 | MCP4017T-103E/LT | Package_TO_SOT_SMD:SOT-363_SC-70-6 | http://ww1.microchip.com/downloads/en/DeviceDoc/22147a.pdf | 1
U10 | TMP102xxDRL | Package_TO_SOT_SMD:SOT-563 | https://www.ti.com/lit/ds/symlink/tmp102.pdf | 1
Y1 | 8MHz 20pf | Crystal:Crystal_SMD_5032-2Pin_5.0x3.2mm | ~ | 1

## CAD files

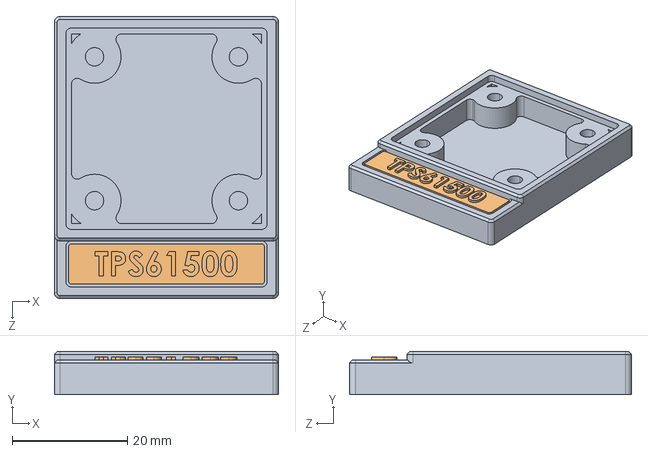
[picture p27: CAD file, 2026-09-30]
electrical/flashlight-boost-dev-2/holder/pcb-mural-board-holder-tps61500.STEP
39.0 x 7.50 x 49.0 mm

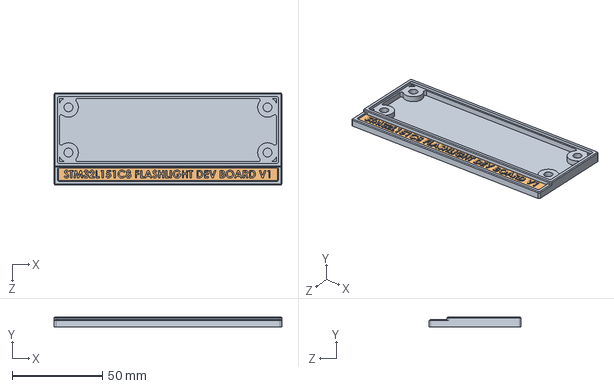
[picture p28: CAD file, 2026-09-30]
electrical/flashlight-full-v1-1/cad/holder/pcb-mural-board-holder-stm32-dev.STEP
126.0 x 5.50 x 51.0 mm

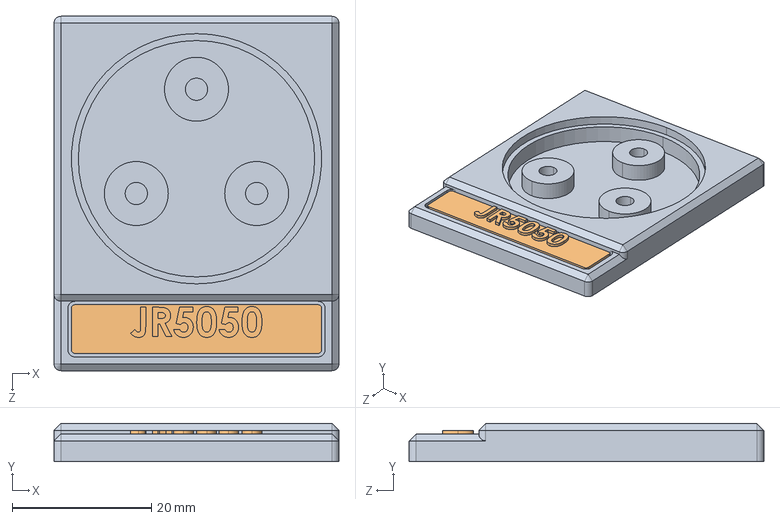
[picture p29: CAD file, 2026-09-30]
electrical/flashlight-led/holder/pcb-mural-board-holder-led.STEP
41.0 x 5.50 x 51.0 mm

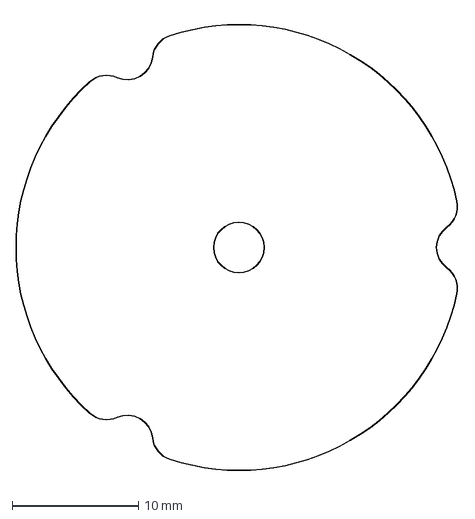
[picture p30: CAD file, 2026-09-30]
electrical/flashlight-led/outline_dxf.DXF
35.1 x 36.6 mm

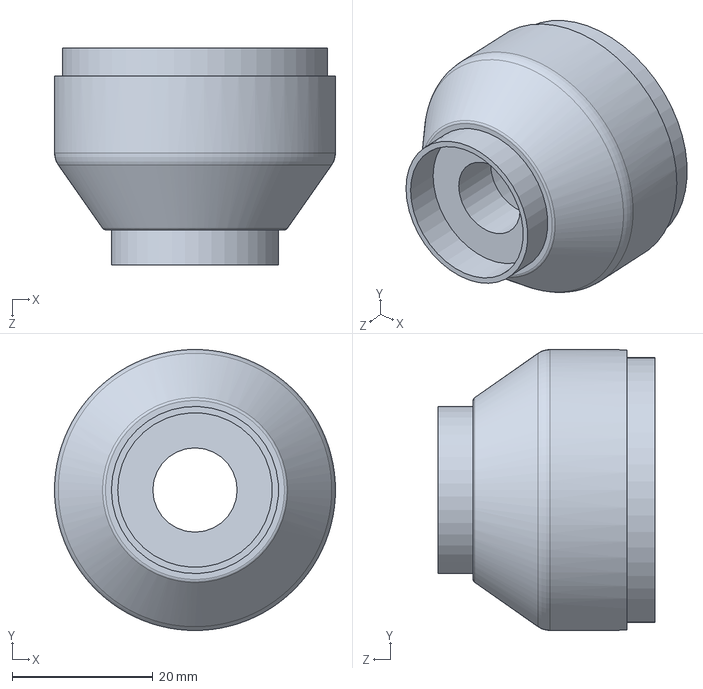
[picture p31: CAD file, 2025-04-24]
mechanical/cad/parts/head.SLDPRT
40.0 x 40.0 x 30.9 mm

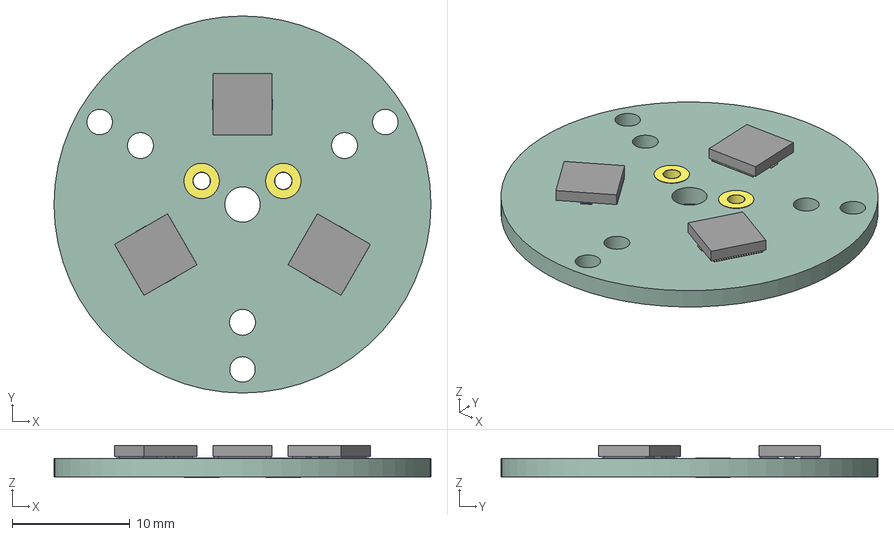
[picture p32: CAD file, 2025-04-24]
electrical/flashlight-led/flashlight-led.step
32.0 x 32.0 x 2.74 mm
ASSEMBLY x 3
flashlight-led_pad_1
flashlight-led_pad_2
flashlight-led_pad_3
flashlight-led_pad_4
flashlight-led_pad_5
flashlight-led_pad_6
flashlight-led_pad_7
flashlight-led_pad_8
flashlight-led_pad_9
flashlight-led_pad_10
flashlight-led_pad_11
flashlight-led_pad_12
flashlight-led_pad_13
flashlight-led_pad_14
flashlight-led_pad_15
flashlight-led_pad_16
flashlight-led_pad_17
flashlight-led_pad_18
flashlight-led_pad_19
flashlight-led_pad_20
flashlight-led_pad_21
flashlight-led_PCB

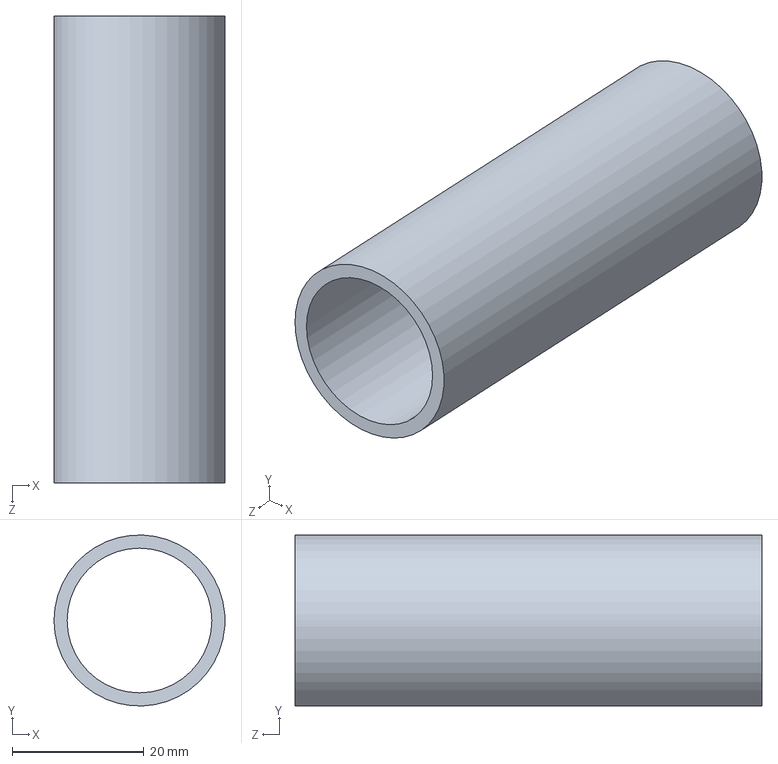
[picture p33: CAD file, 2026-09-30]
mechanical/cad/body.SLDPRT
26.0 x 26.0 x 71.0 mm

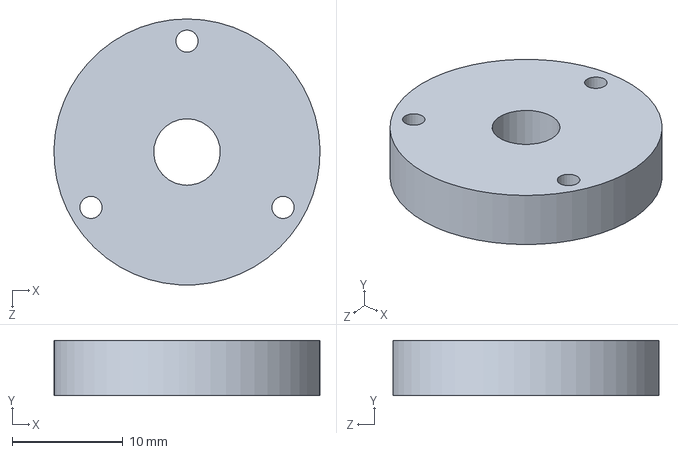
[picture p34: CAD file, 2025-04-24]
mechanical/cad/parts/slug.SLDPRT
24.0 x 5.00 x 24.0 mm

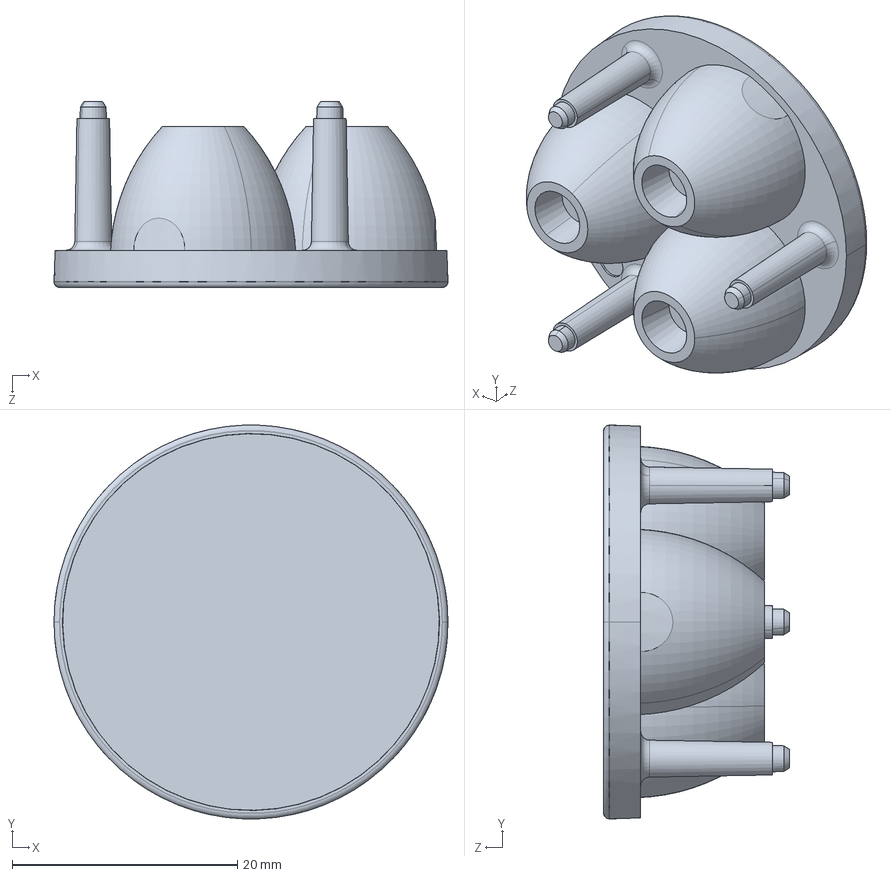
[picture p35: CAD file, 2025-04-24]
mechanical/cad/parts/TIR_60D.SLDPRT
35.0 x 35.0 x 16.5 mm

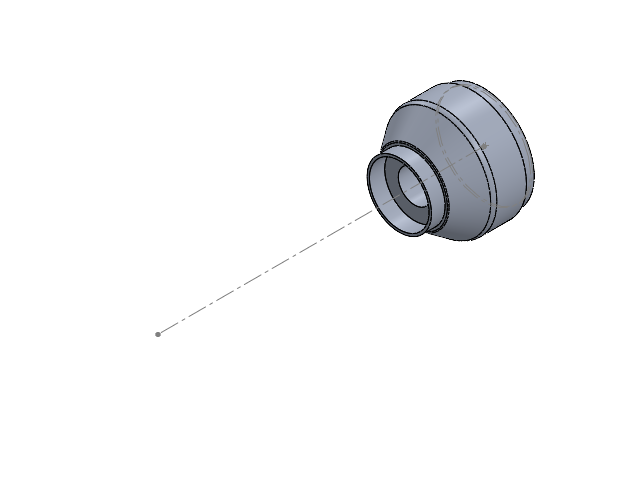
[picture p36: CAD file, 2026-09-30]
mechanical/cad/flashlight-v1.SLDASM
TIR_60D
ASSEMBLY x 3
flashlight-led_pad_1
flashlight-led_pad_2
flashlight-led_pad_3
flashlight-led_pad_4
flashlight-led_pad_5
flashlight-led_pad_6
flashlight-led_pad_9
flashlight-led_pad_10
flashlight-led_pad_11
flashlight-led_pad_14
flashlight-led_pad_15
flashlight-led_pad_16
flashlight-led_pad_19
flashlight-led_pad_20
flashlight-led_pad_21
flashlight-led_PCB
head

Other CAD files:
mechanical/cad/parts/pcbs/led/ASSEMBLY.SLDPRT
mechanical/cad/parts/pcbs/led/JR5050CWT-E-B30EB0000-N0000001.SLDASM
mechanical/cad/parts/pcbs/led/flashlight-led_pad_6.SLDPRT
mechanical/cad/parts/pcbs/led/flashlight-led_pad_10.SLDPRT
mechanical/cad/parts/pcbs/led/flashlight-led_pad_1.SLDPRT
mechanical/cad/parts/pcbs/led/flashlight-led_pad_21.SLDPRT
mechanical/cad/parts/pcbs/led/flashlight-led_pad_16.SLDPRT
electrical/flashlight-boost-dev-2/holder/pcb-mural-board-holder-tps61500.SLDPRT
electrical/flashlight-full-v1-1/cad/holder/pcb-mural-board-holder-stm32-dev.SLDPRT
electrical/flashlight-led/holder/pcb-mural-board-holder-led.SLDPRT
electrical/flashlight-stm32-dev/holder/pcb-mural-board-holder-stm32-dev.SLDPRT
mechanical/cad/parts/18650-battery.SLDPRT
mechanical/cad/parts/pcbs/led/flashlight-led(2).SLDASM
mechanical/cad/parts/pcbs/led/flashlight-led.SLDASM
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

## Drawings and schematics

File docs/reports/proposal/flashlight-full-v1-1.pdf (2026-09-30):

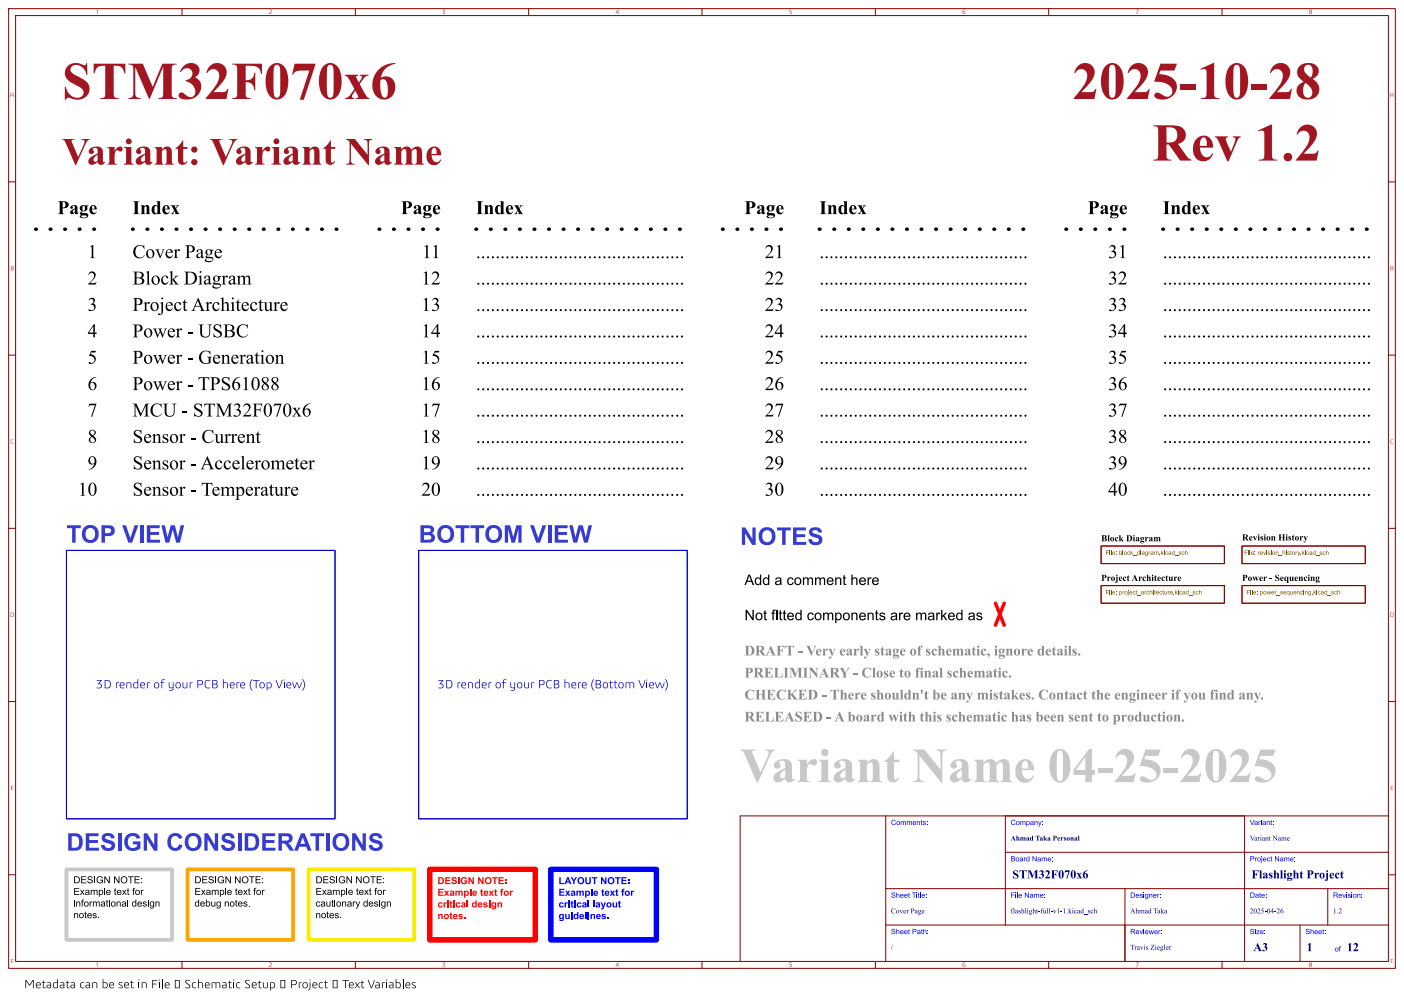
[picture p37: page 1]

Not fitted components are marked as

DRAFT - Veryearlystageof schematic,ignoredetails.
PRELIMINARY - Closetofinal schematic.
VariantName04-25-2025

Revision: 1.2 Date: Project Name: 2025-04-26 Reviewer: TravisZiegler

Metadata canbe setin Fileþÿ!’ SchematicSetupþÿ!’ Projectþÿ!’ TextVariables

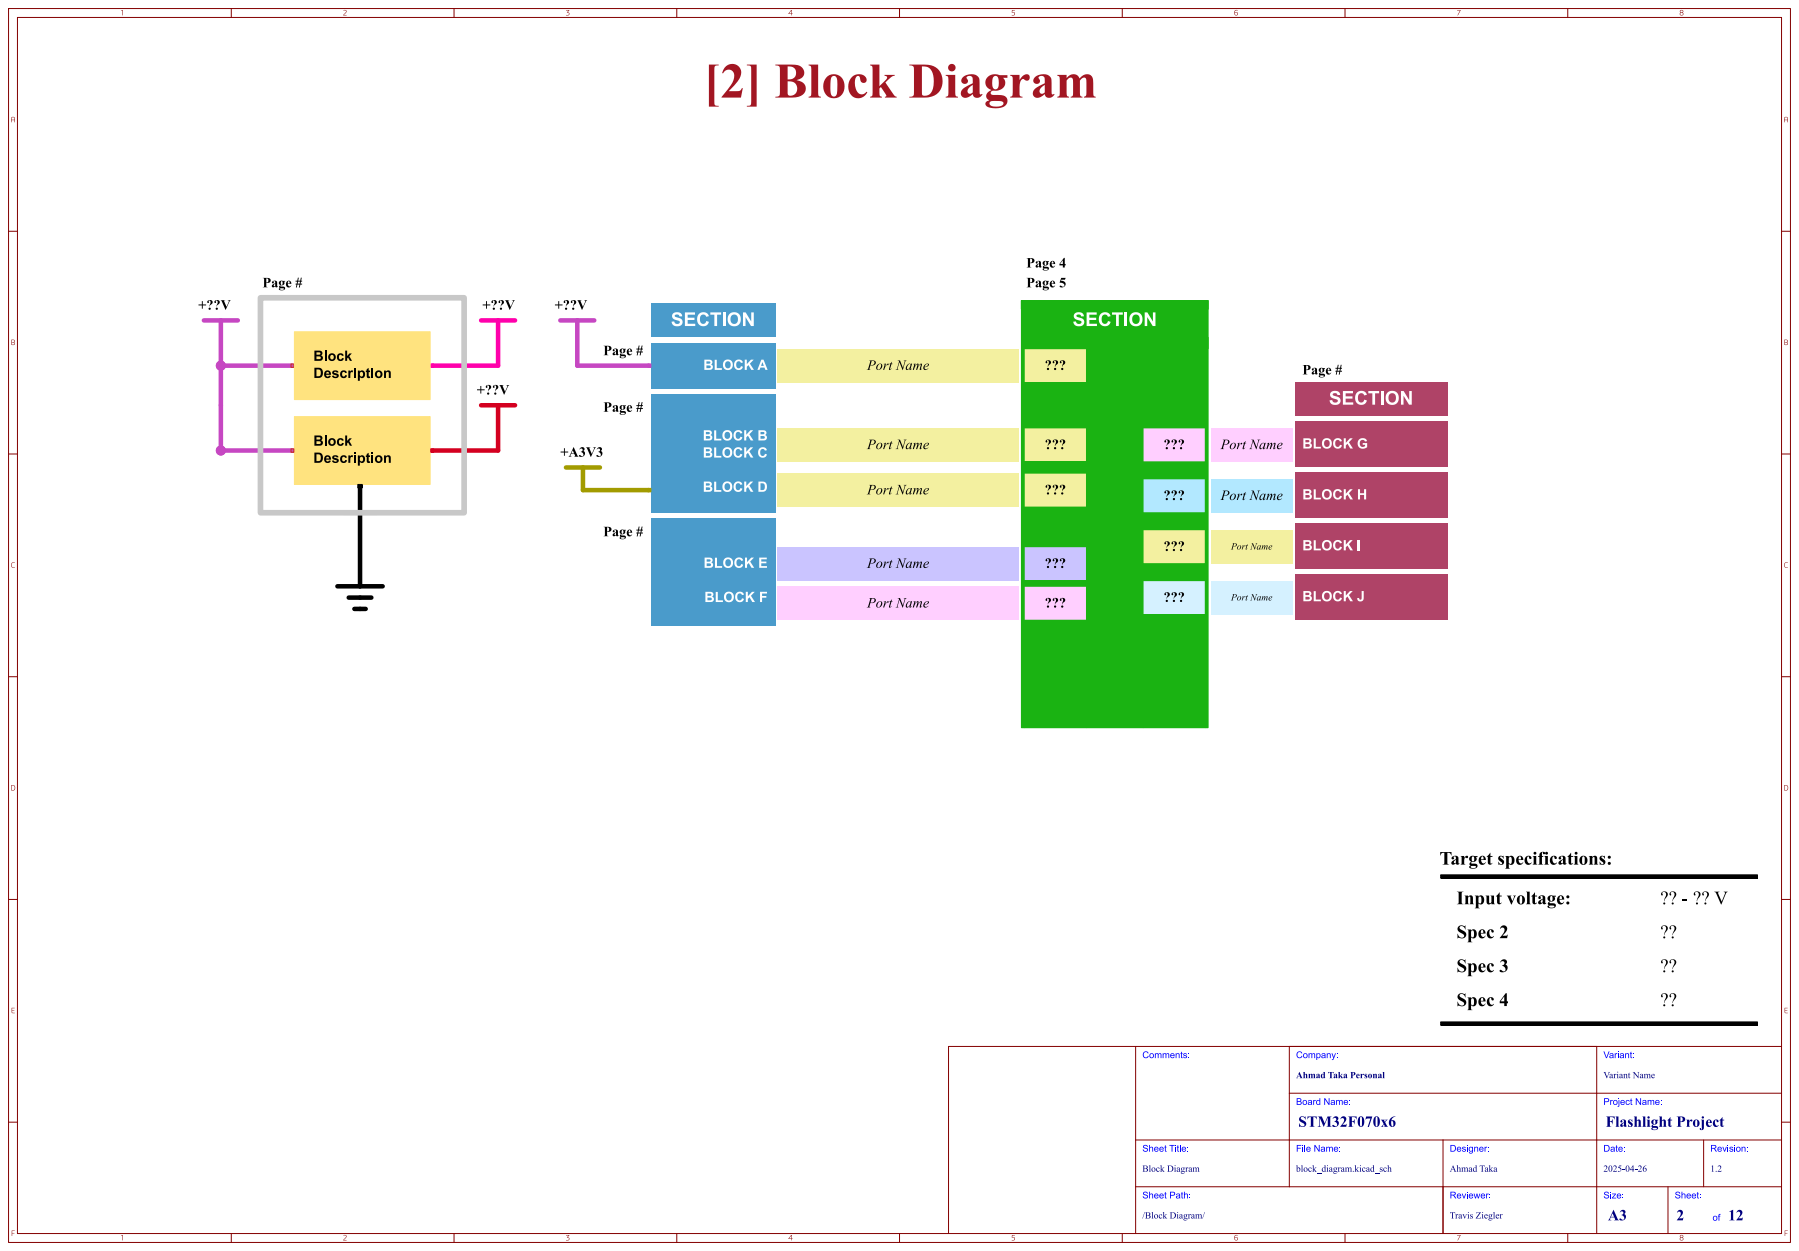
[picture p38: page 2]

Port Name | ??? | ??? | Port Name

BLOCK G

Revision: 1.2 Date: Project Name: 2025-04-26 Reviewer: TravisZiegler

/Block Diagram/ Sheet Path: Block Diagram

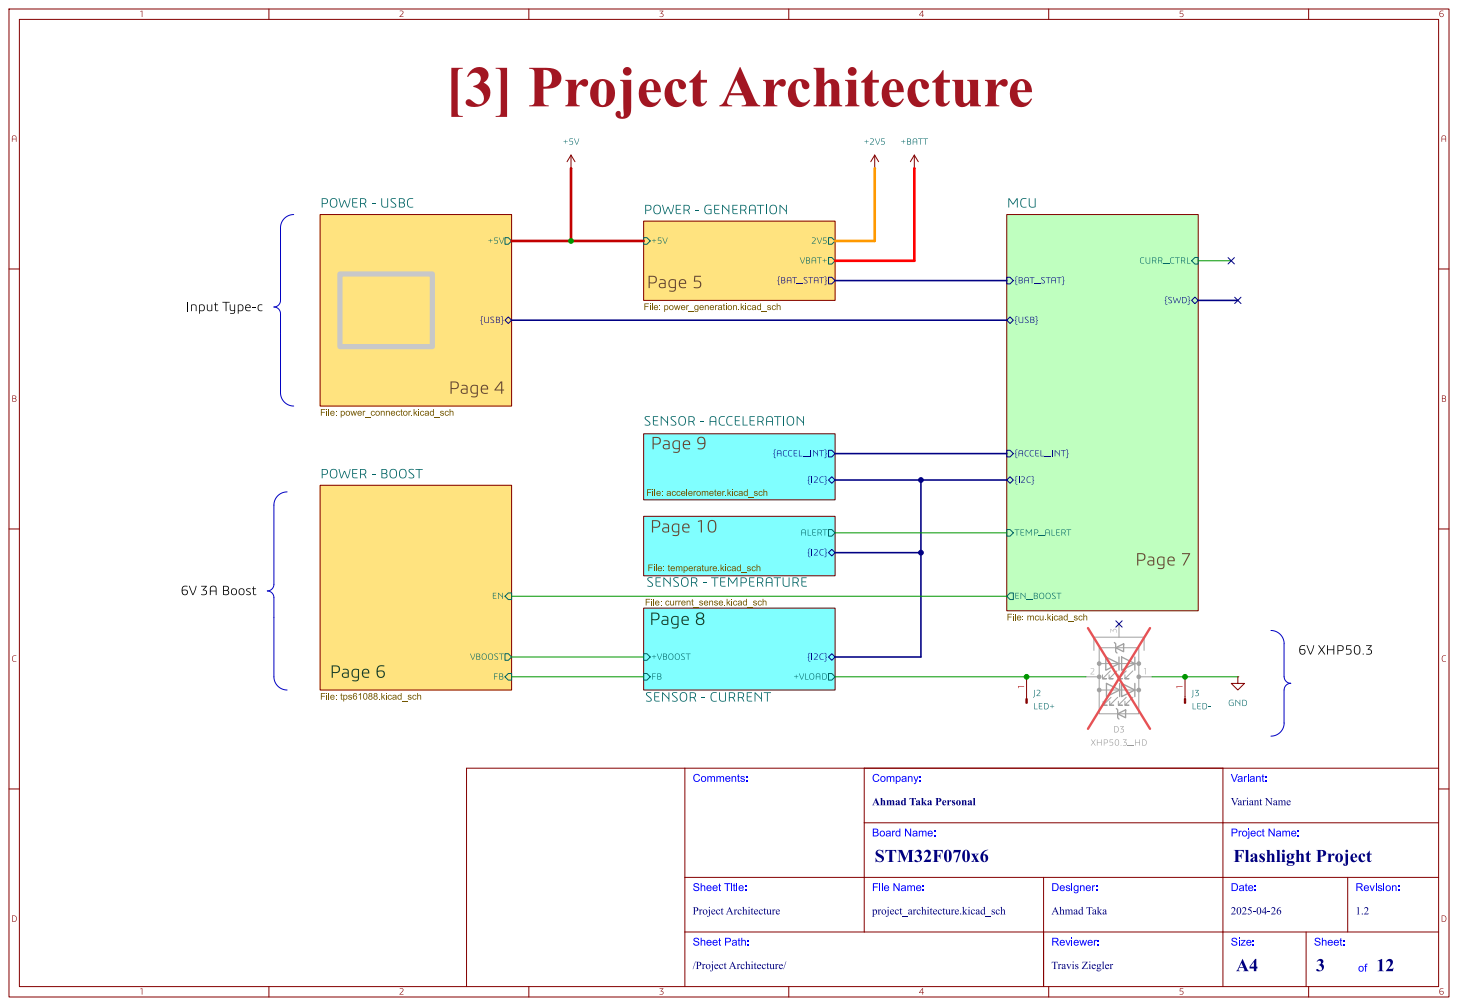
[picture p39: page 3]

/ProjectArchitecture/ Sheet Path: ProjectArchitecture Comments: FB
SENSOR- CURRENT

Revision: 1.2 Date: Project Name: 2025-04-26 Reviewer: TravisZiegler

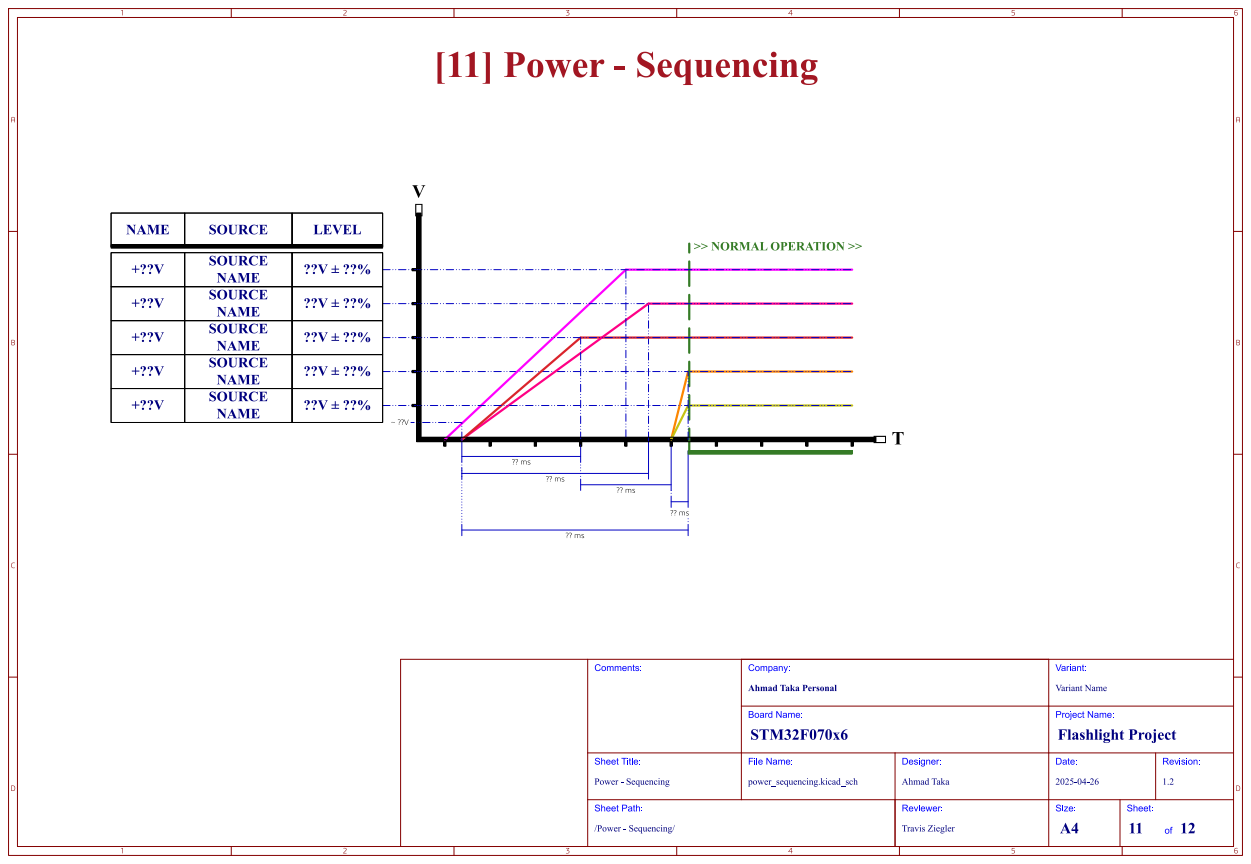
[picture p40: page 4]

SOURCE NAME +??V | ??Vþÿ±??%

+??V | SOURCE NAME | ??Vþÿ±??%

SOURCE NAME | ??Vþÿ±??% | ~ ??V +??V

/Power- Sequencing/ Sheet Path: Power- Sequencing Comments: ??ms Tip:you cansetNetClassColorsfor differentvoltagerailsin Fileþÿ!’ SchematicSetupþÿ!’ Projectþÿ!’ Net Classes

Revision: 1.2 Date: Project Name: 2025-04-26 Reviewer: TravisZiegler

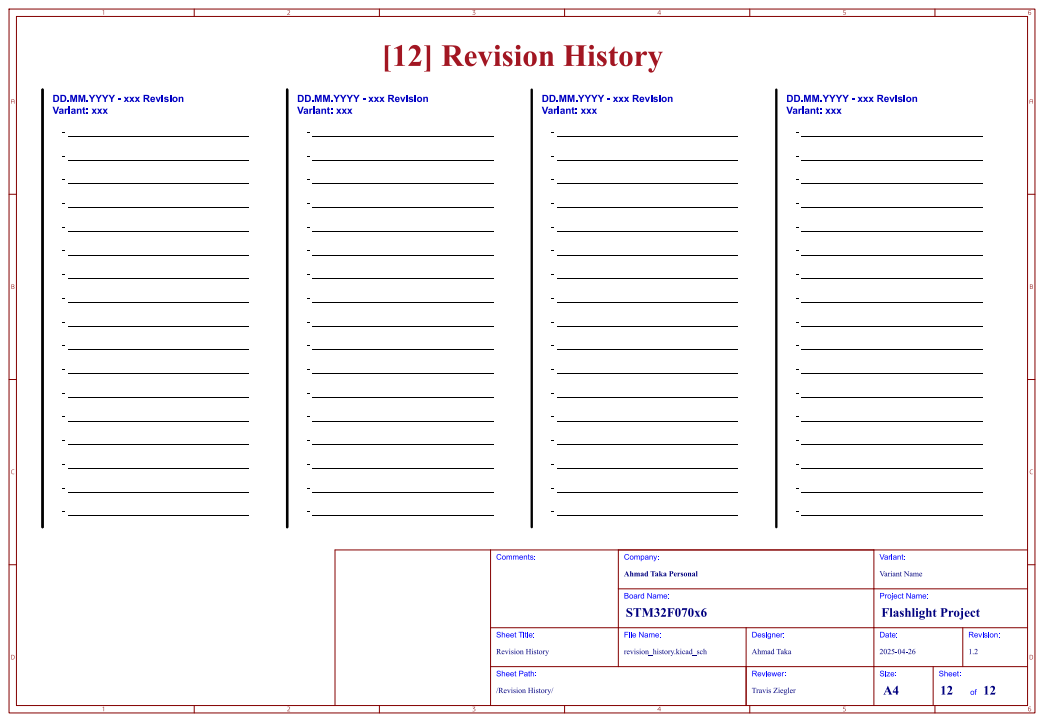
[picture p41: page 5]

- _________________________________ DD.MM.YYYY - xxx Revision

DD.MM.YYYY - xxx Revision
Variant: xxx

/RevisionHistory/ Sheet Path: RevisionHistory Comments:

Revision: 1.2 Date: Project Name: 2025-04-26 Reviewer: TravisZiegler

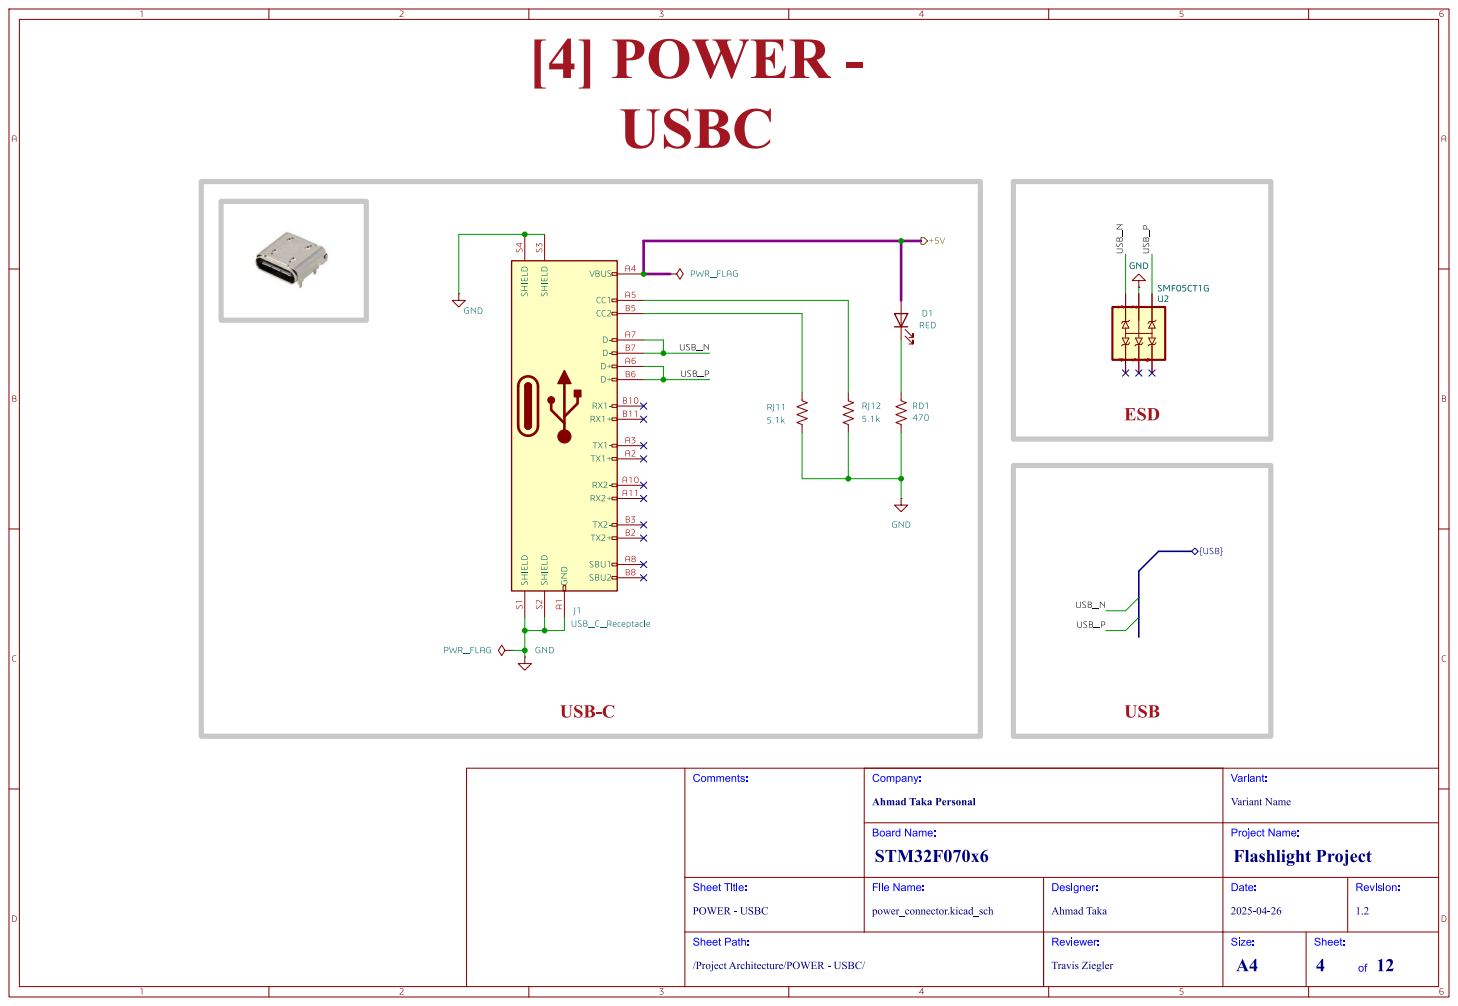
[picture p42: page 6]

Revision: 1.2 Date: Project Name: 2025-04-26 Reviewer: TravisZiegler

/ProjectArchitecture/POWER- USBC/ Sheet Path: POWER- USBC

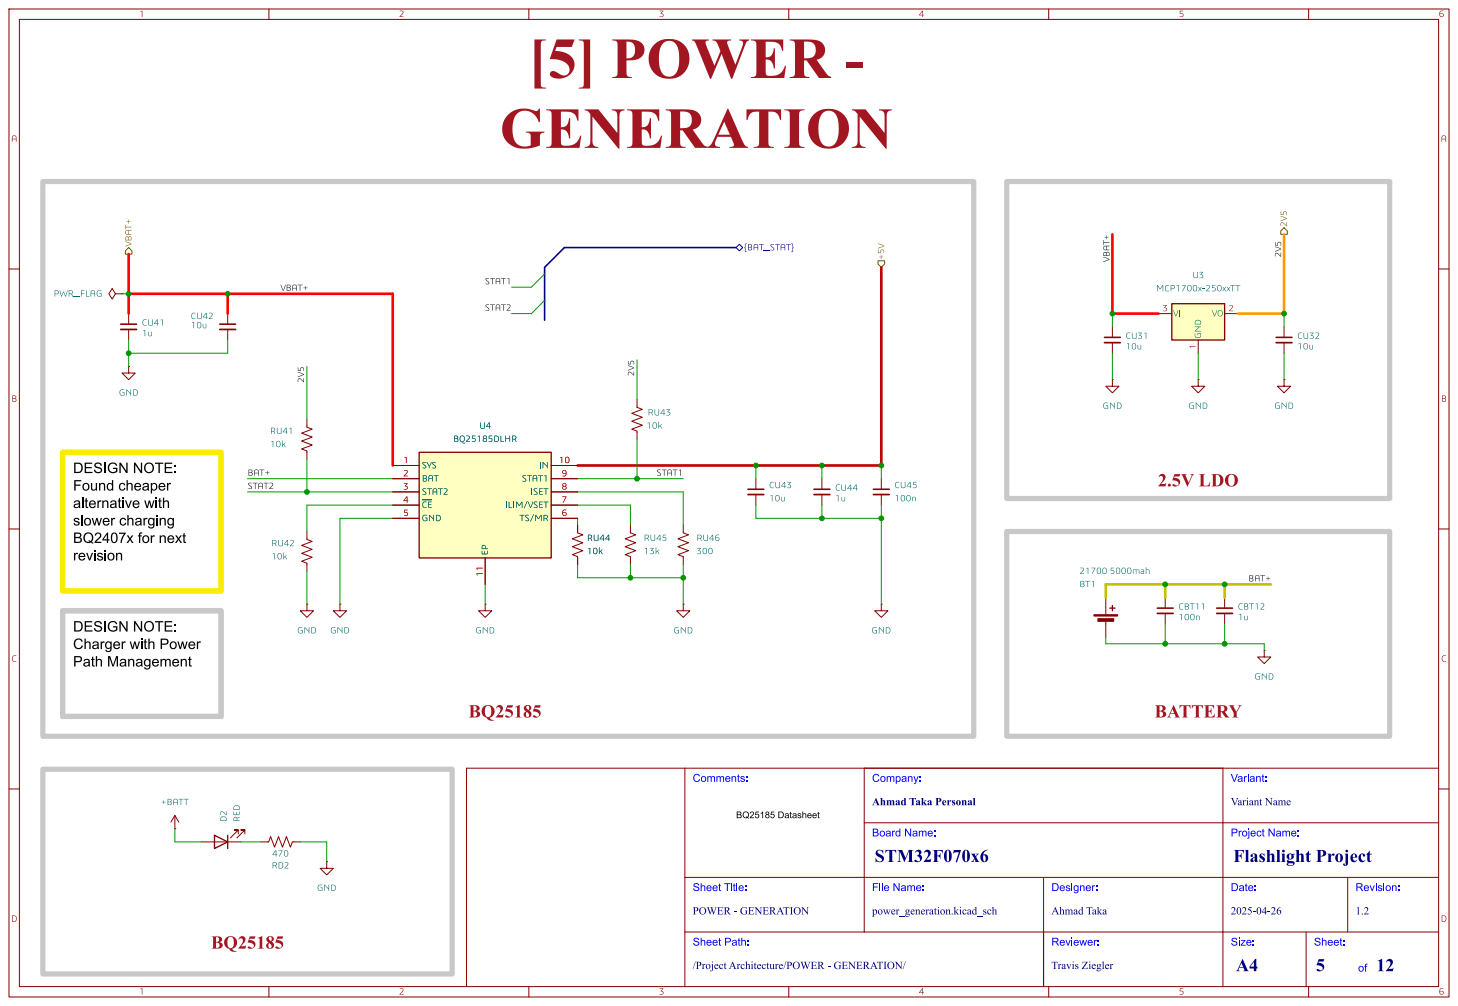
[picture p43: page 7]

Revision: 1.2 Date: Project Name: 2025-04-26 Reviewer: TravisZiegler

/ProjectArchitecture/POWER- GENERATION/ Sheet Path: POWER- GENERATION

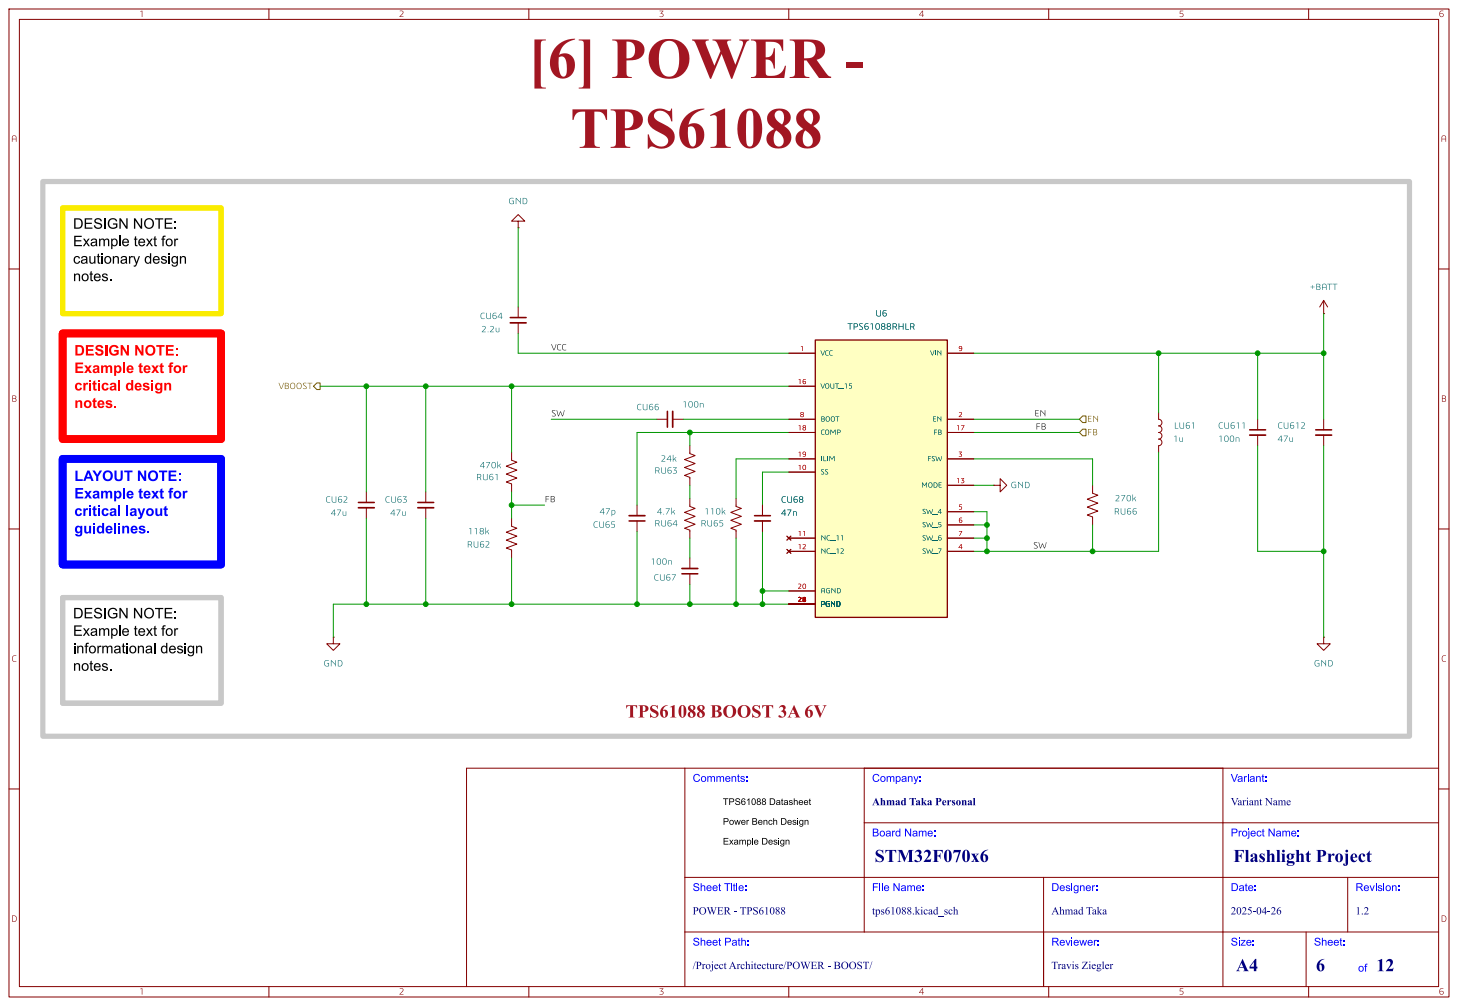
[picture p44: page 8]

/ProjectArchitecture/POWER- BOOST/ Sheet Path: POWER- TPS61088 Comments: CU63

Example Design (https://loneoceans.com/labs/sales/gxb20v1/) Power Bench Design TPS61088 Datasheet

Revision: 1.2 Date: Project Name: 2025-04-26 Reviewer: TravisZiegler

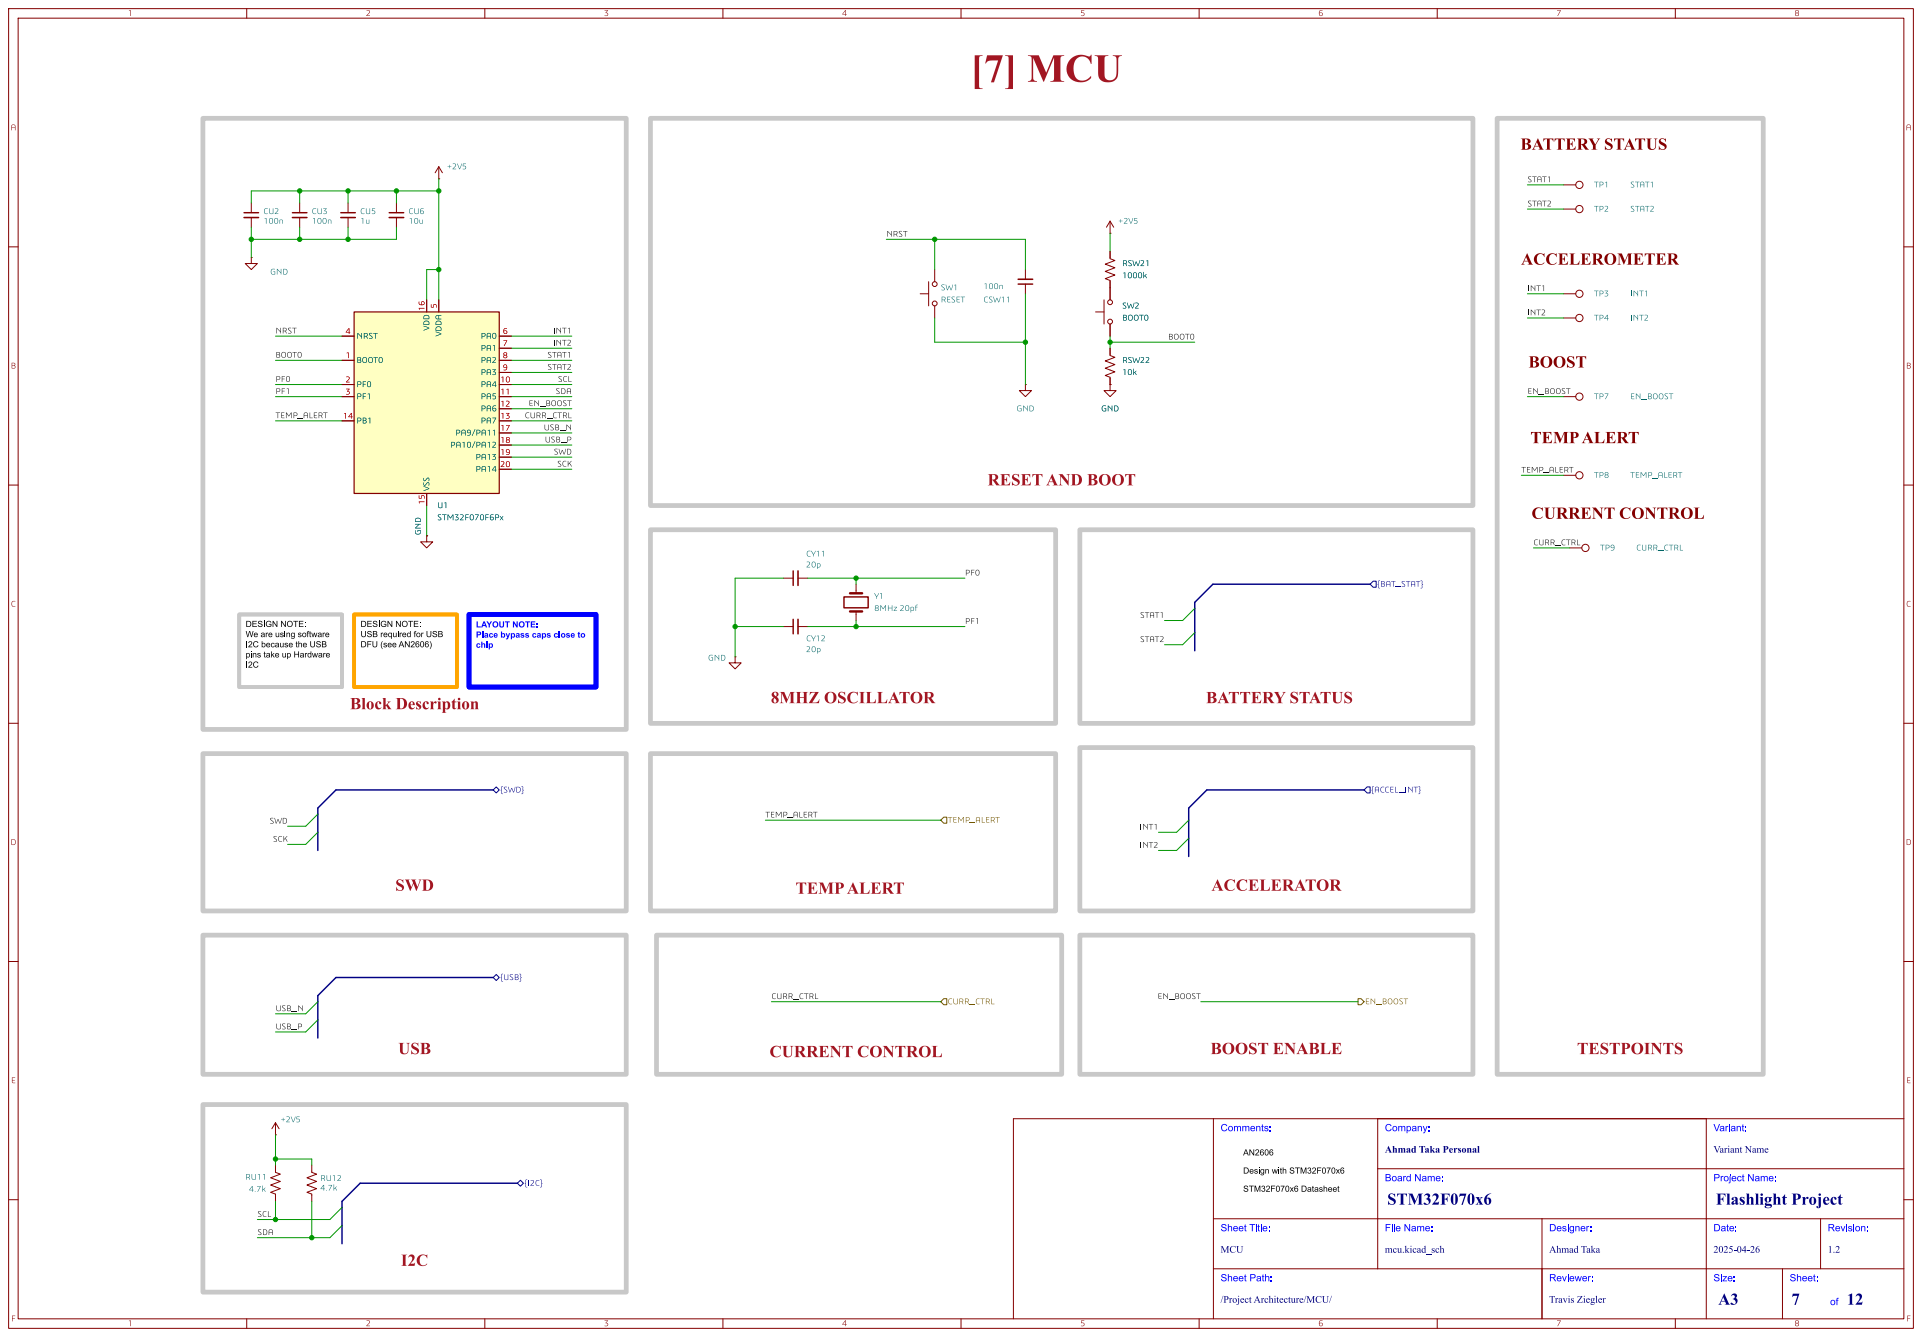
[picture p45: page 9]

DESIGN NOTE: We are using software

DESIGN NOTE: USB required for USB DFU (see AN2606)

LAYOUT NOTE: Place bypass caps close to

I2C because the USB
pins take up Hardware

Revision: 1.2 Date: Project Name: 2025-04-26 Reviewer: TravisZiegler

/ProjectArchitecture/MCU/ Sheet Path: MCU

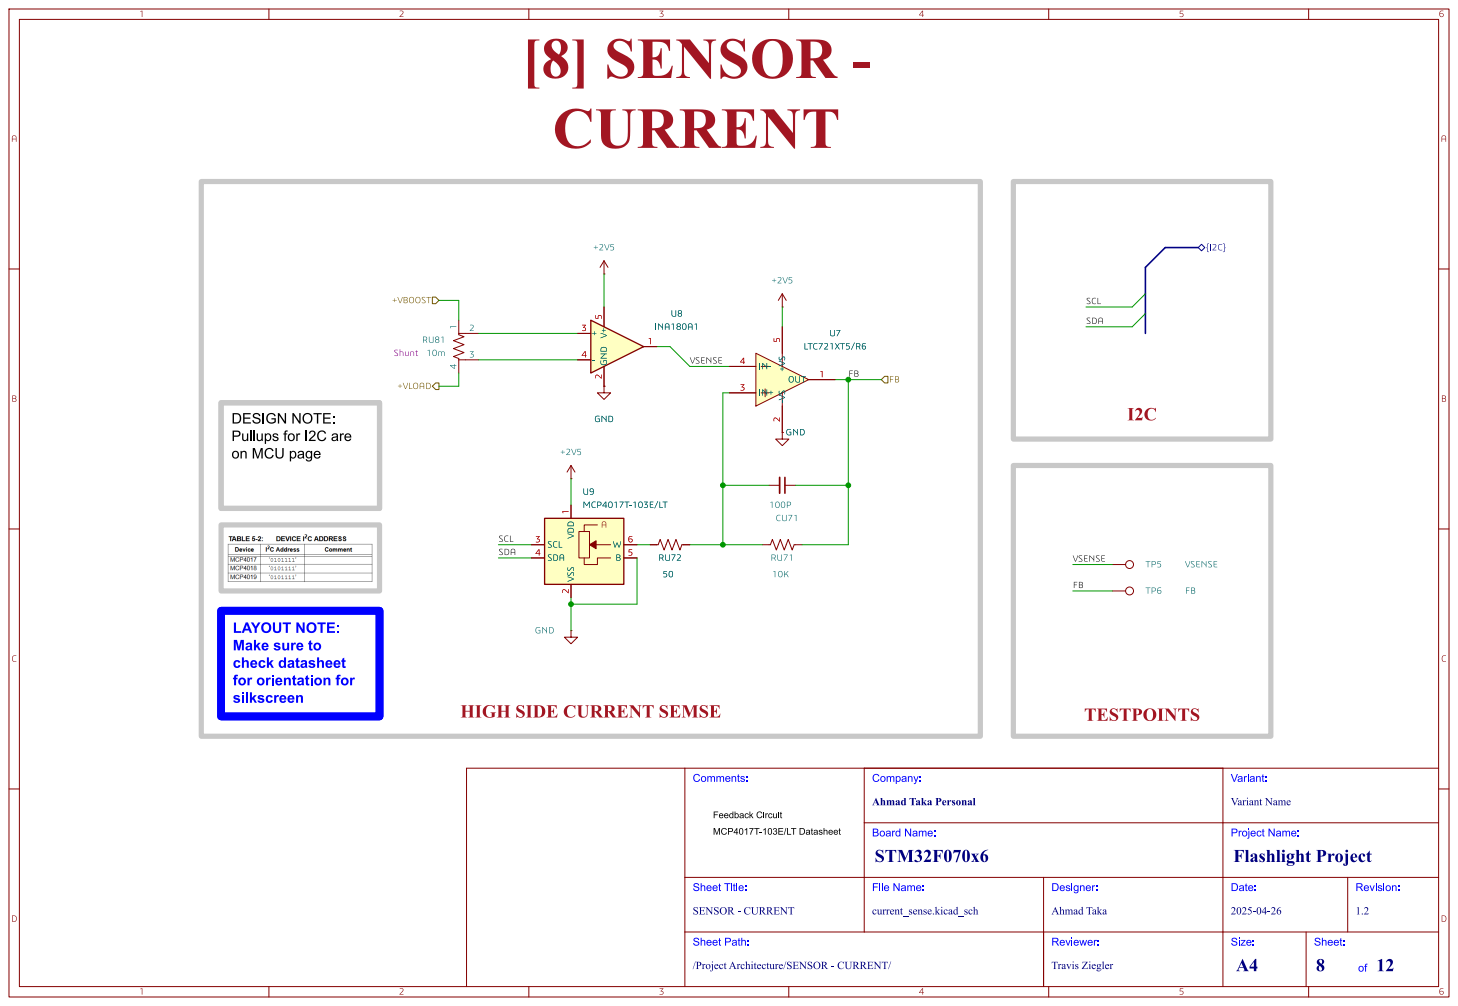
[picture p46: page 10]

Feedback Circuit (https://tinyurl.com/2a93747n) MCP4017T-103E/LT Datasheet GND

HIGH SIDE CURRENT SEMSE

Revision: 1.2 Date: Project Name: 2025-04-26 Reviewer: TravisZiegler

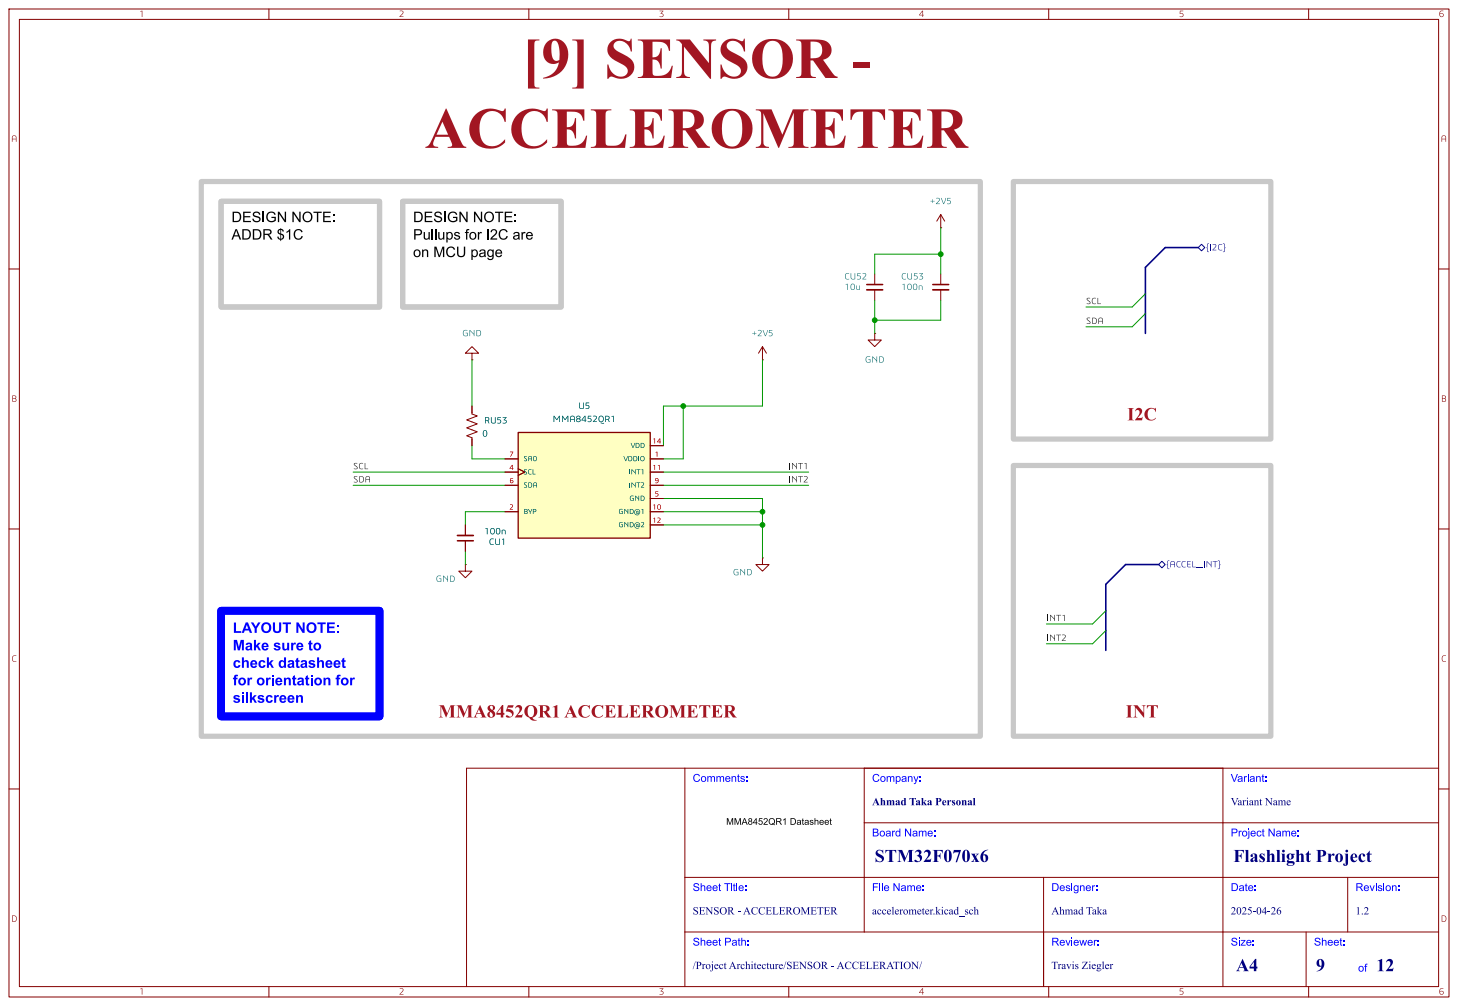
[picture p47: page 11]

Revision: 1.2 Date: Project Name: 2025-04-26 Reviewer: TravisZiegler

/ProjectArchitecture/SENSOR- ACCELERATION/ Sheet Path: SENSOR- ACCELEROMETER

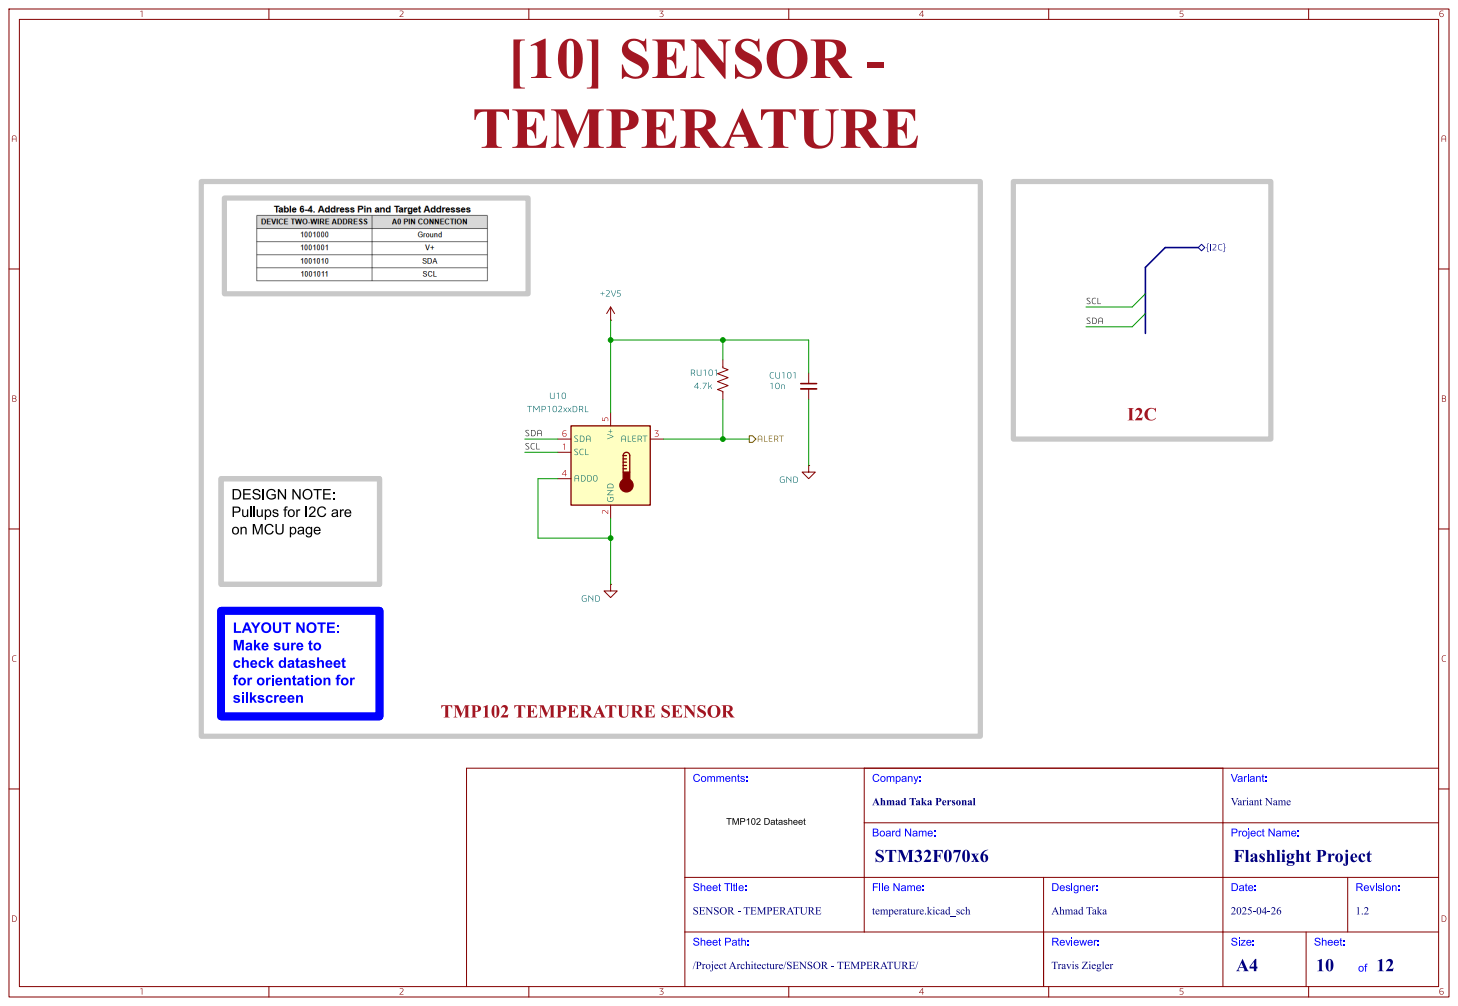
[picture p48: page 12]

/ProjectArchitecture/SENSOR- TEMPERATURE/ Sheet Path: SENSOR- TEMPERATURE Comments: GND

Revision: 1.2 Date: Project Name: 2025-04-26 Reviewer: TravisZiegler

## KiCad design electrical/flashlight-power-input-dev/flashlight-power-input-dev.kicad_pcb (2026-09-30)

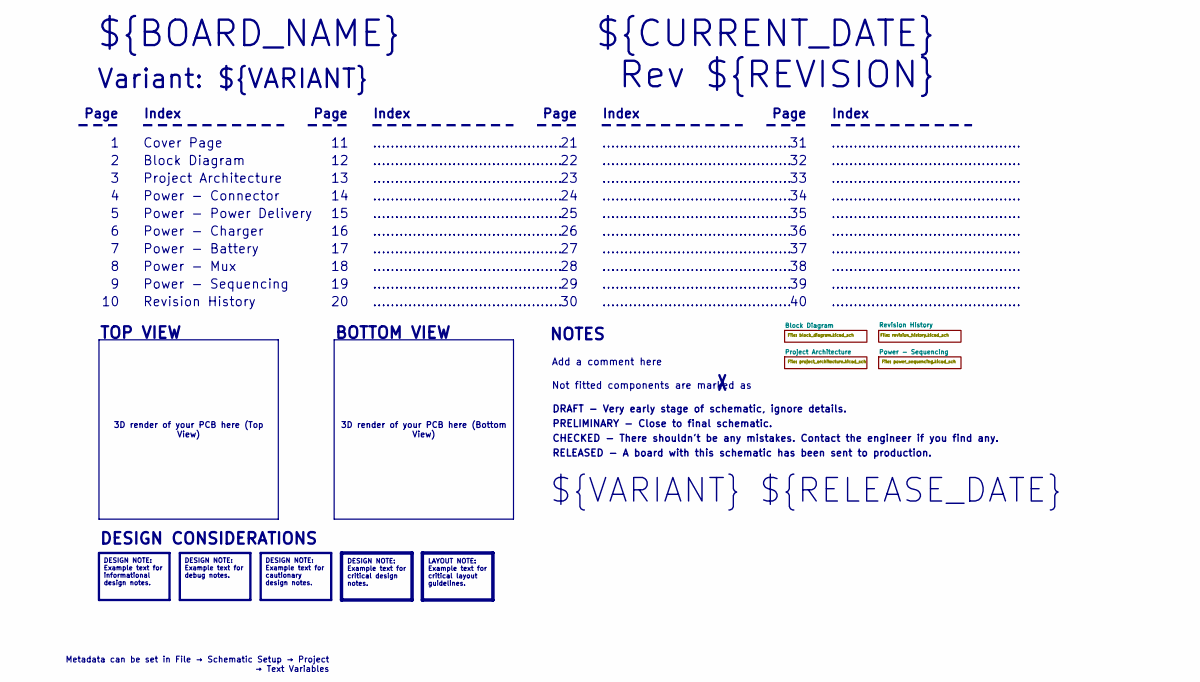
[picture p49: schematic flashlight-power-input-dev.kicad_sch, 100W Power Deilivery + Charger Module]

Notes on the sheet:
BOTTOM VIEW
...........................................
RELEASED - A board with this schematic has been sent to production.
Page
TOP VIEW
Revision History
Power - Sequencing
Power - Mux
Not fitted components are marked as
Index
PRELIMINARY - Close to final schematic.
${VARIANT} ${RELEASE_DATE}
Power - Connector
${CURRENT_DATE}
Variant: ${VARIANT}
Rev ${REVISION}
Power - Power Delivery
${BOARD_NAME}
DRAFT - Very early stage of schematic, ignore details.
Power - Charger
Block Diagram
Add a comment here
Cover Page
NOTES
Project Architecture
CHECKED - There shouldn't be any mistakes. Contact the engineer if you find any.
DESIGN CONSIDERATIONS
Power - Battery
3D render of your PCB here (Bottom View)
3D render of your PCB here (Top View)
Metadata can be set in File → Schematic Setup → Project → Text Variables
DESIGN NOTE: Example text for informational design notes.
LAYOUT NOTE: Example text for critical layout guidelines.
DESIGN NOTE: Example text for cautionary design notes.
DESIGN NOTE: Example text for debug notes.
DESIGN NOTE: Example text for critical design notes.

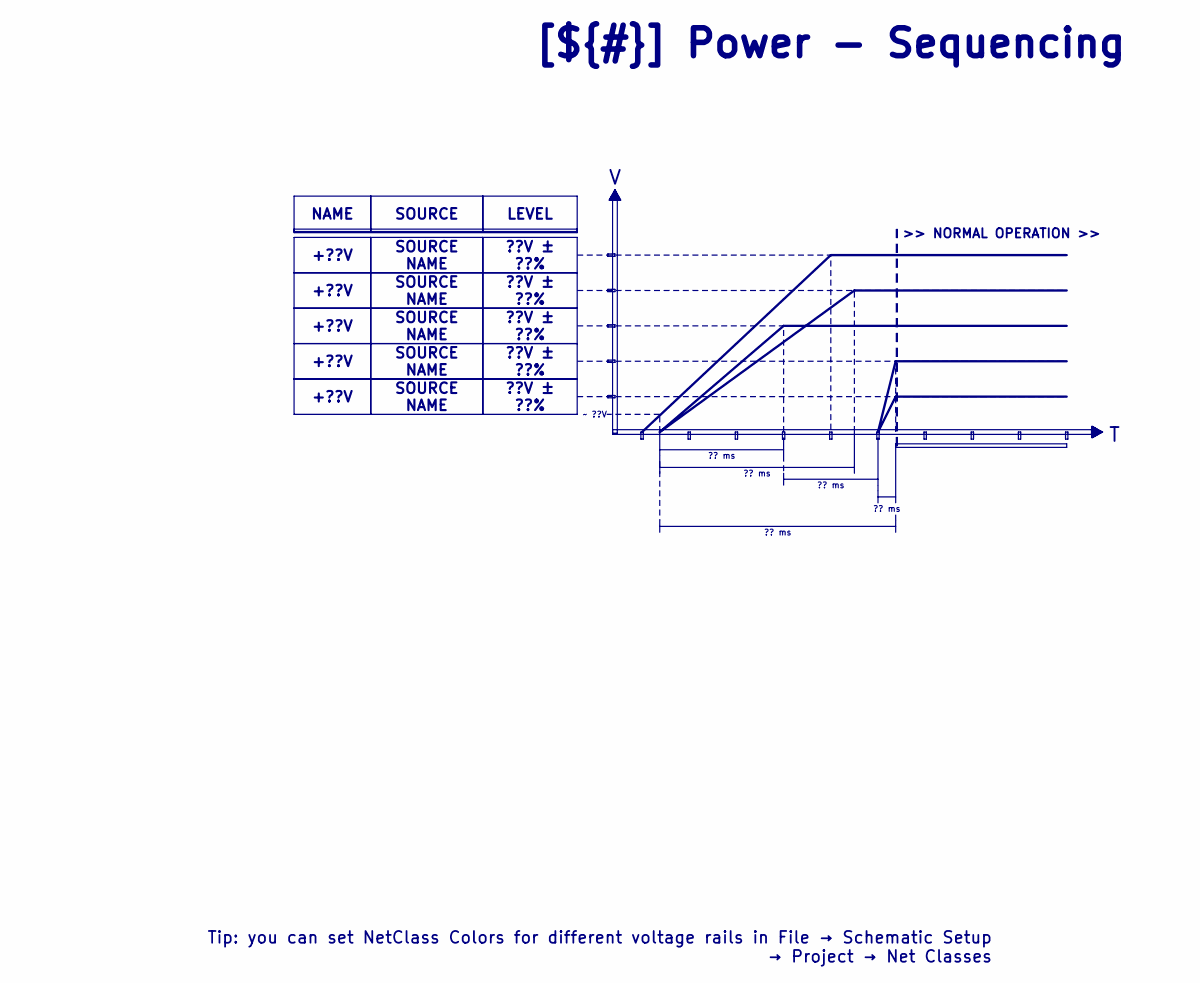
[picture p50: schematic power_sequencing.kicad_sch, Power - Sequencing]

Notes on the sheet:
>> NORMAL OPERATION >>
LEVEL
+??V
SOURCE NAME
?? ms
??V ± ??%
[${#}] ${TITLE}
~ ??V
NAME
SOURCE
Tip: you can set NetClass Colors for different voltage rails in File → Schematic Setup → Project → Net Classes

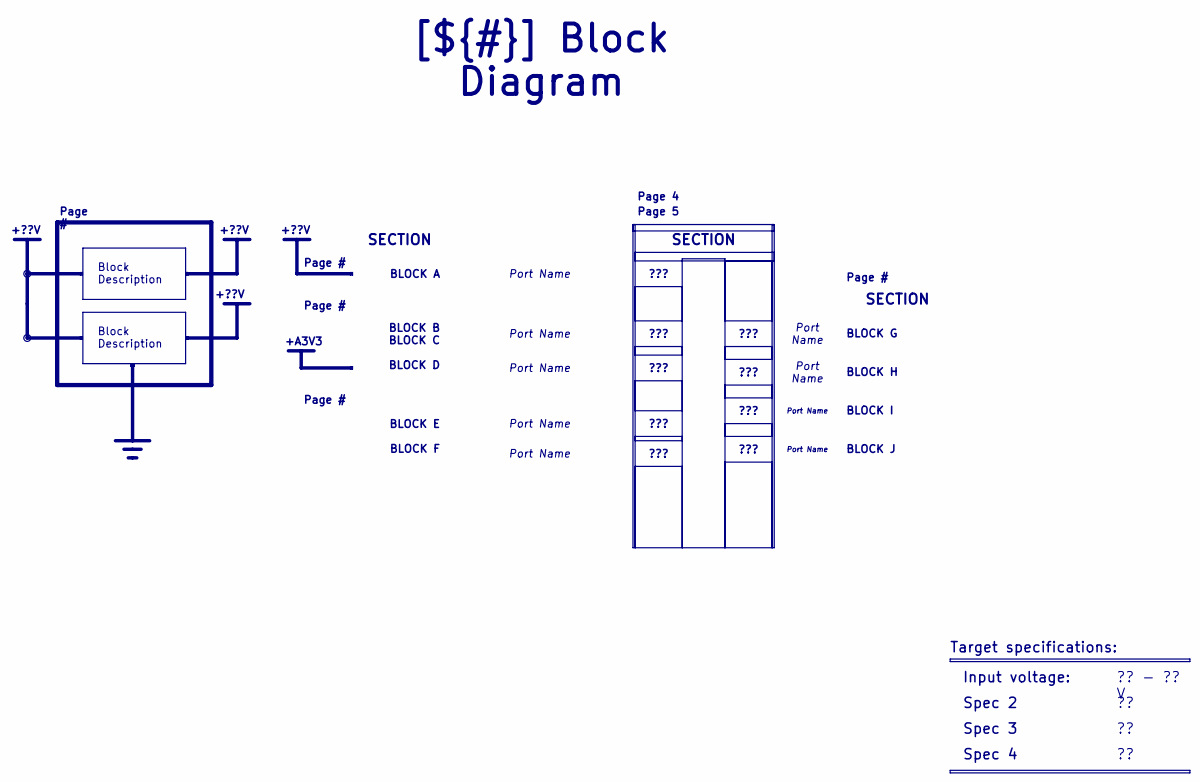
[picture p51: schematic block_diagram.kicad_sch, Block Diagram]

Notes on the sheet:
+??V
+A3V3
Spec 3
Block Description
???
Spec 2
Port Name
SECTION
Page #
Input voltage:
BLOCK E BLOCK F
BLOCK A
BLOCK I
BLOCK G
[${#}] ${TITLE}
Target specifications:
?? - ?? V
Page 4
BLOCK J
Page 5
BLOCK B BLOCK C BLOCK D
Spec 4
BLOCK H

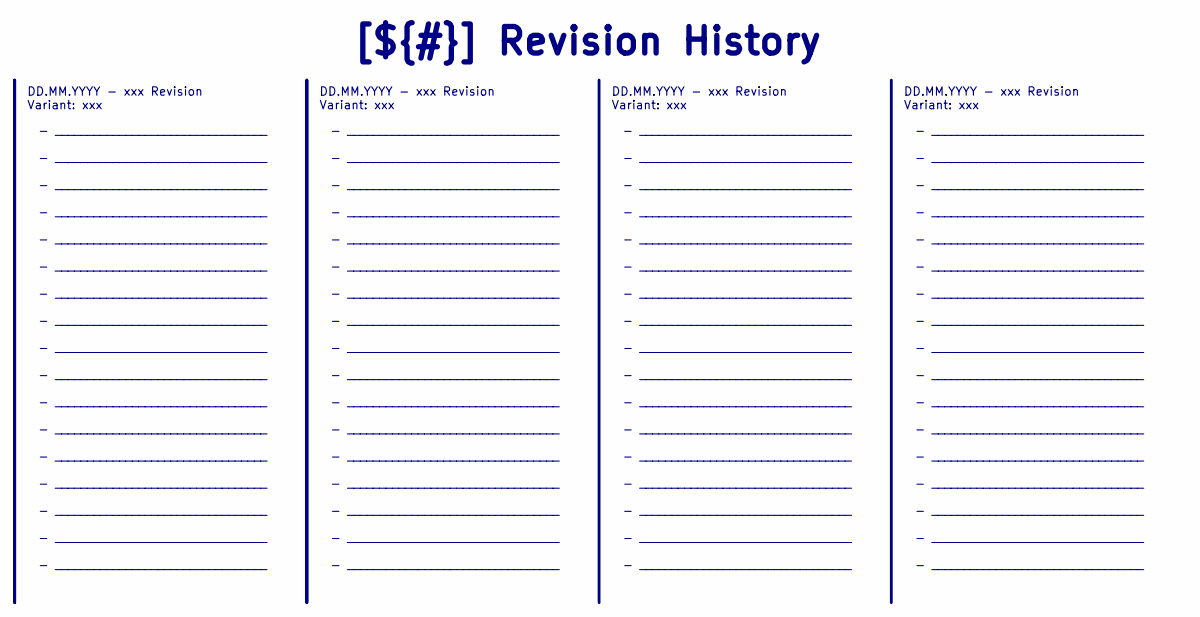
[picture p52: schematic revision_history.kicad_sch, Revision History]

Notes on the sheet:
- _________________________________ - _________________________________ - _________________________________ - _________________________________ - _________________________________ - _________________________________ - _________________________________ - _________________________________ - _________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
DD.MM.YYYY - xxx Revision Variant: xxx
[${#}] ${TITLE}

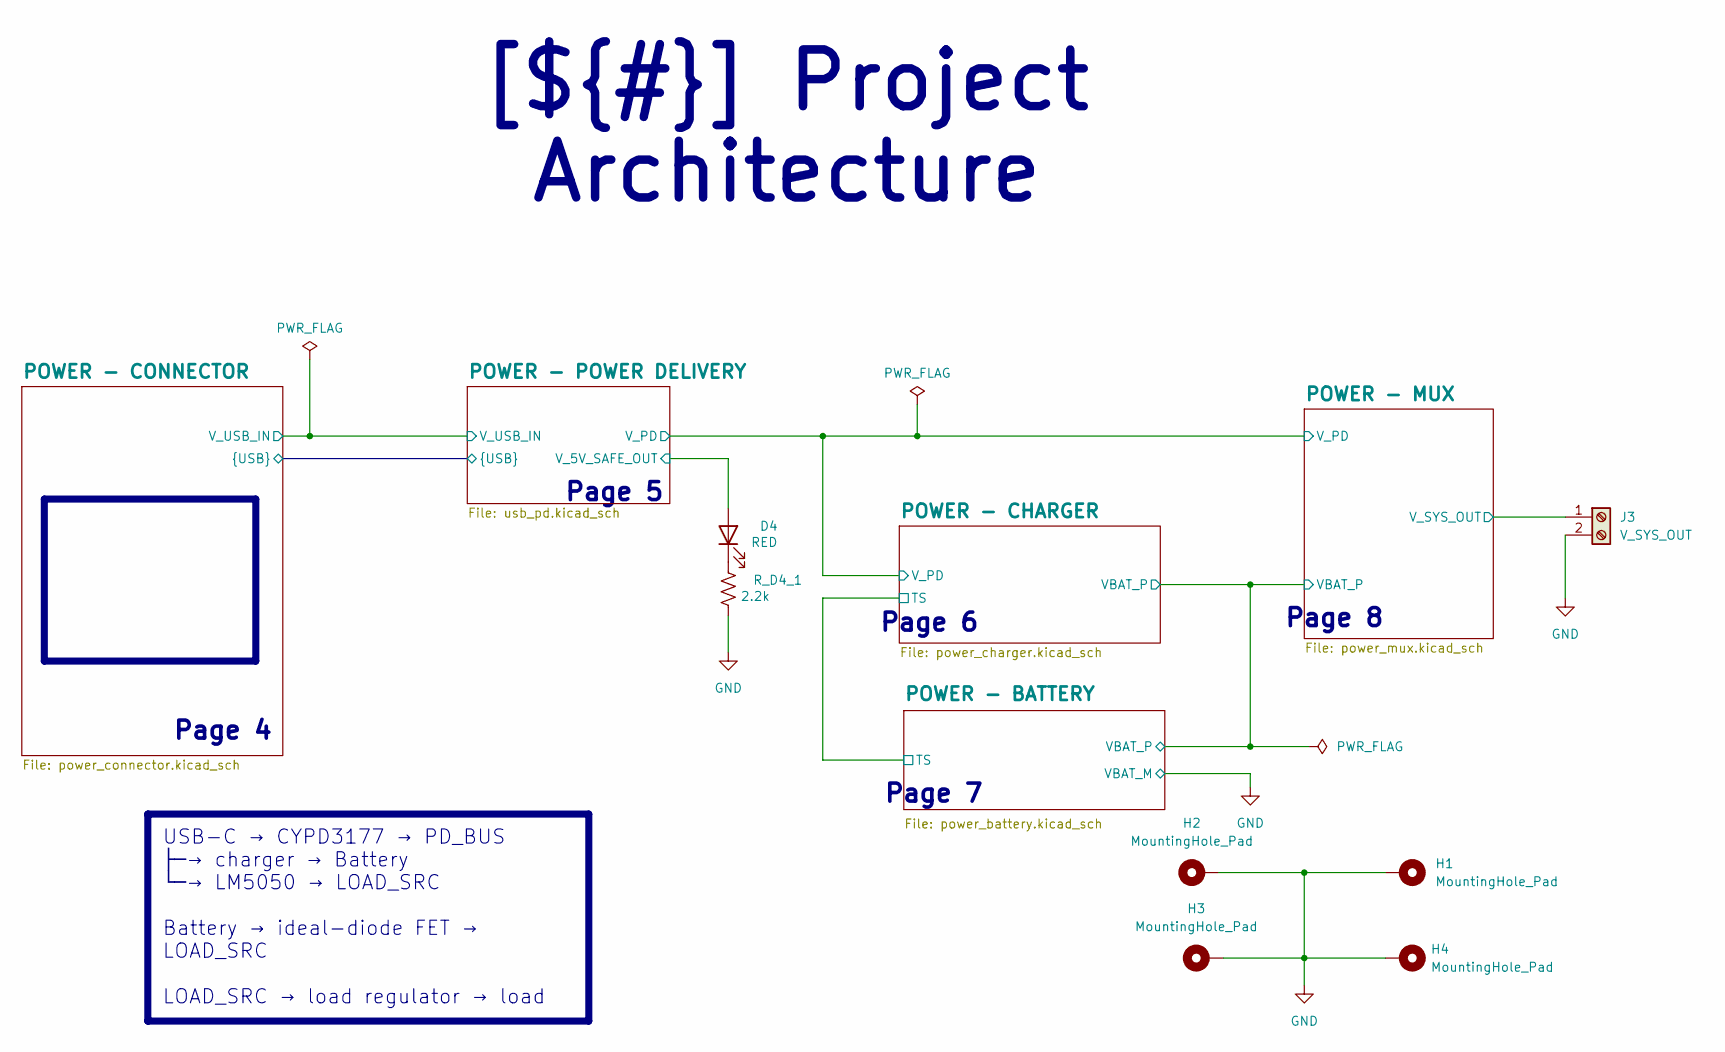
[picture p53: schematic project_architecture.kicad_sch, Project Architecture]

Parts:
D4: RED; LED_0603_1608Metric; LCSC C2286
H1, H2, H3, H4: MountingHole_Pad; MountingHole_3.2mm_M3_DIN965_Pad
J3: V_SYS_OUT; TerminalBlock_Phoenix_MKDS-1,5-2-5.08_1x02_P5.08mm_Horizont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
R_D4_1: 2.2k; R_0402_1005Metric; LCSC C25091

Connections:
/Project Architecture/POWER - MUX/V_SYS_OUT: J3.1; also elsewhere on the board
/Project Architecture/POWER - POWER DELIVERY/V_5V_SAFE_OUT: D4.2 (A); also elsewhere on the board
GND: H1.1 (1_1), H2.1 (1_1), H3.1 (1_1), H4.1 (1_1), J3.2, R_D4_1.1; also elsewhere on the board
unnamed: D4.1 (K), R_D4_1.2

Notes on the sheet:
Page 8
Page 5
Page 4
Page 6
Page 7
USB-C → CYPD3177 → PD_BUS ├─→ charger → Battery └─→ LM5050 → LOAD_SRC Battery → ideal-diode FET → LOAD_SRC LOAD_SRC → load regulator → load
[${#}] ${TITLE}

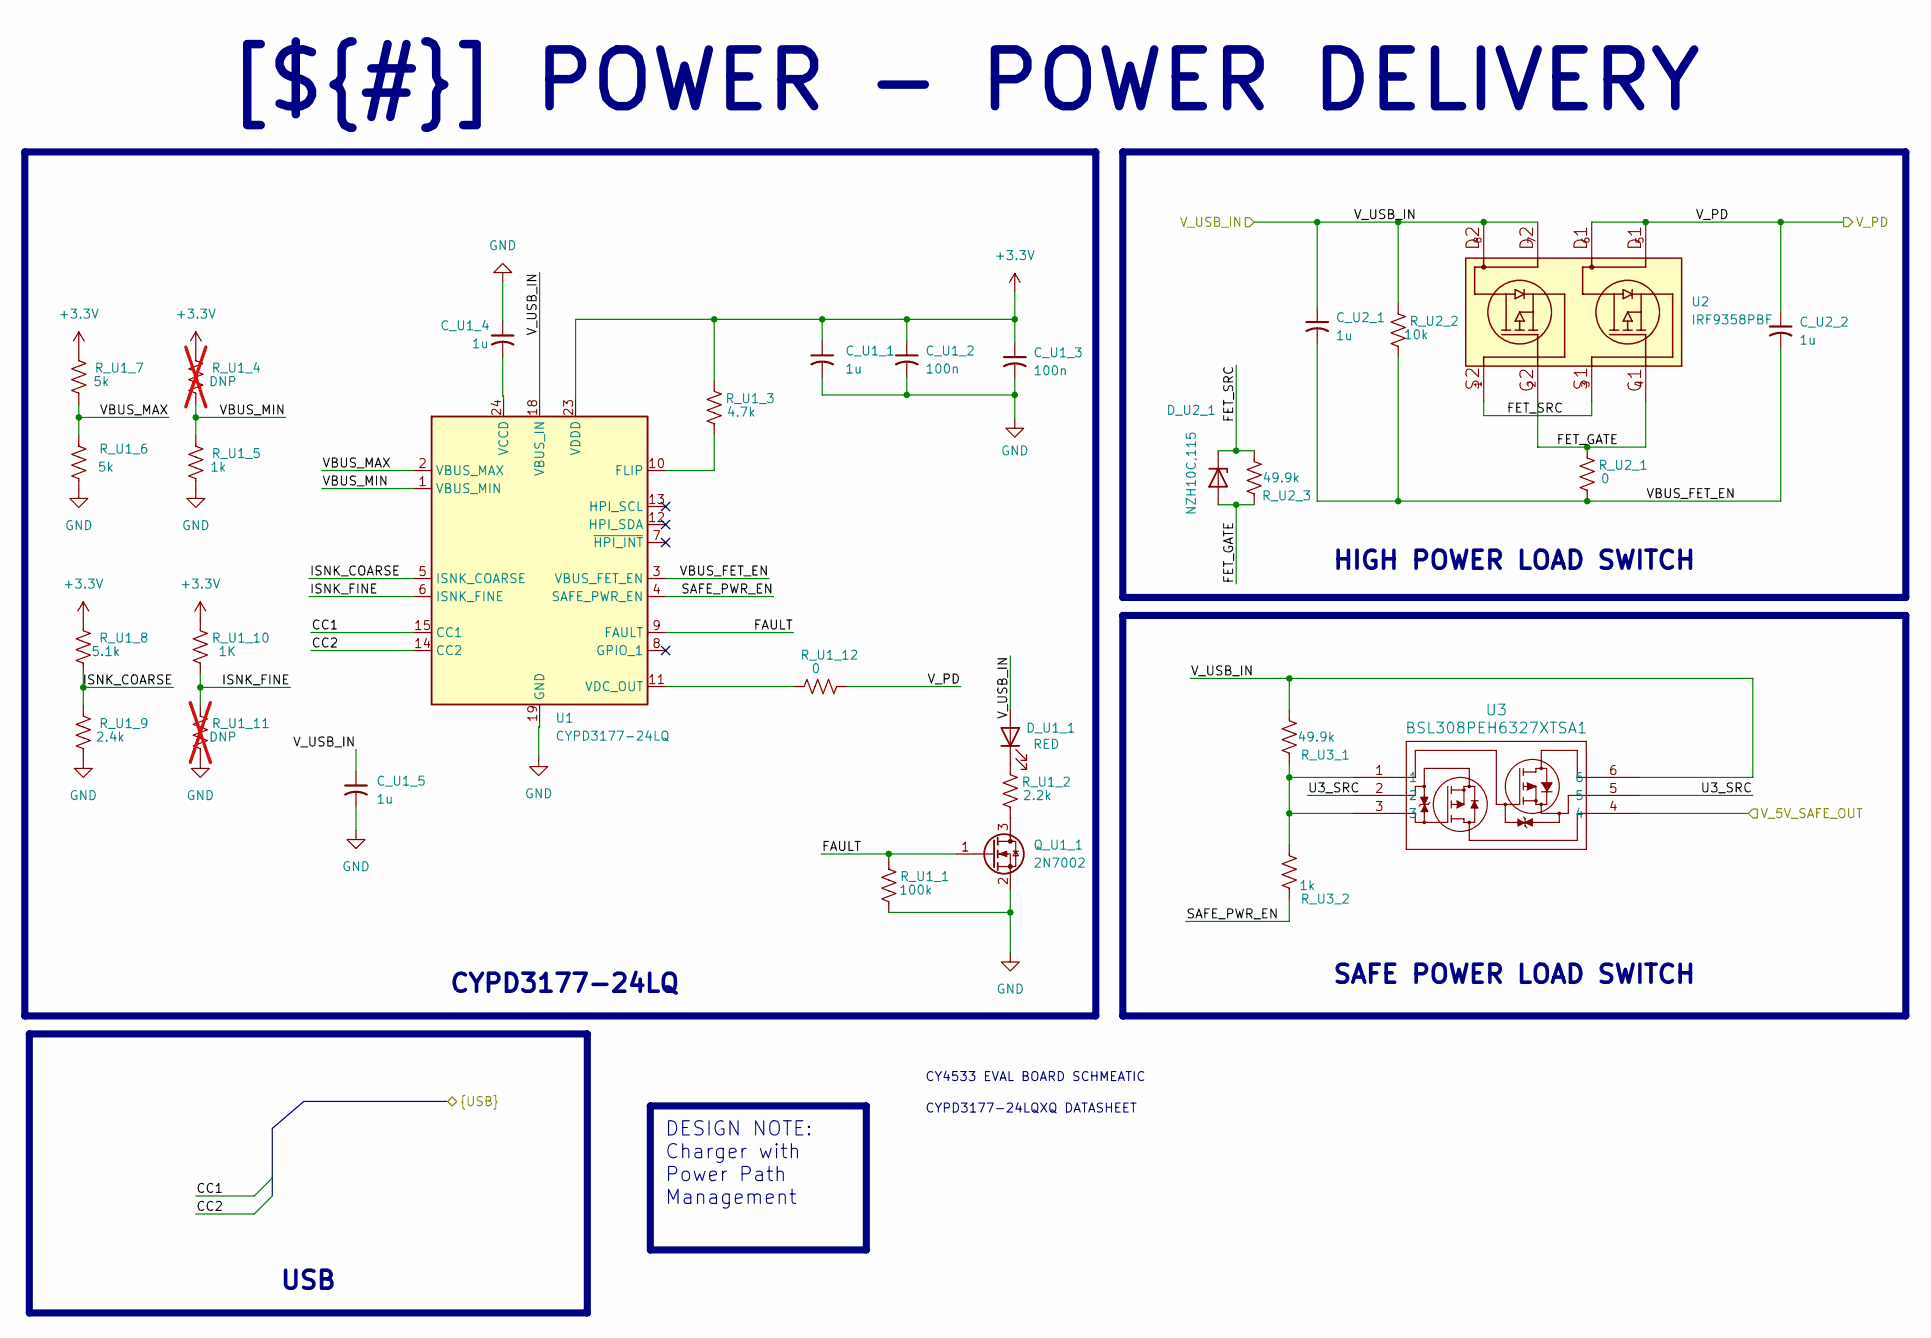
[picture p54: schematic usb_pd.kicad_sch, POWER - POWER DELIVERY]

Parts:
C_U1_1, C_U1_5, C_U2_1, C_U2_2: 1u; R_0603_1608Metric_Pad0.98x0.95mm_HandSolder
C_U1_2, C_U1_3: 100n; C_0402_1005Metric
C_U1_4: 1u; C_0402_1005Metric
D_U1_1: RED; LED_0603_1608Metric; LCSC C2286
D_U2_1: NZH10C,115; D_SOD-123F
Q_U1_1: 2N7002; SOT-23
R_U1_1: 100k; R_0402_1005Metric; LCSC C25091
R_U1_2: 2.2k; R_0402_1005Metric; LCSC C25091
R_U1_3: 4.7k; R_0402_1005Metric; LCSC C25091
R_U1_4, R_U1_11: DNP; R_0603_1608Metric_Pad0.98x0.95mm_HandSolder; LCSC C25091; not fitted
R_U1_5, R_U3_2: 1k; R_0603_1608Metric_Pad0.98x0.95mm_HandSolder; LCSC C25091
R_U1_6, R_U1_7: 5k; R_0603_1608Metric_Pad0.98x0.95mm_HandSolder; LCSC C25091
R_U1_8: 5.1k; R_0603_1608Metric_Pad0.98x0.95mm_HandSolder; LCSC C25091
R_U1_9: 2.4k; R_0603_1608Metric_Pad0.98x0.95mm_HandSolder; LCSC C25091
R_U1_10: 1K; R_0603_1608Metric_Pad0.98x0.95mm_HandSolder; LCSC C25091
R_U1_12, R_U2_1: 0; R_0603_1608Metric_Pad0.98x0.95mm_HandSolder; LCSC C25091
R_U2_2: 10k; R_0603_1608Metric_Pad0.98x0.95mm_HandSolder; LCSC C25091
R_U2_3, R_U3_1: 49.9k; R_0603_1608Metric_Pad0.98x0.95mm_HandSolder; LCSC C25091
U1: CYPD3177-24LQ; QFN-24-1EP_4x4mm_P0.5mm_EP2.75x2.75mm
U2: IRF9358PBF; SOIC8-150
U3: BSL308PEH6327XTSA1; PG-TSOP6-6-4_INF

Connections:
+3.3V: C_U1_1.1, C_U1_2.1, C_U1_3.1, R_U1_3.2, R_U1_4.2, R_U1_7.2, R_U1_8.2, R_U1_10.2, U1.23 (VDDD)
/Project Architecture/POWER - CHARGER/V_PD: C_U2_2.1, R_U1_12.1, U2.5, U2.6; also elsewhere on the board
/Project Architecture/POWER - CONNECTOR/CC1: U1.15 (CC1); also elsewhere on the board
/Project Architecture/POWER - CONNECTOR/CC2: U1.14 (CC2); also elsewhere on the board
/Project Architecture/POWER - POWER DELIVERY/FAULT: Q_U1_1.1 (G), R_U1_1.2, U1.9 (FAULT)
/Project Architecture/POWER - POWER DELIVERY/FET_GATE: D_U2_1.2 (A), R_U2_1.2, R_U2_3.1, U2.2, U2.4
/Project Architecture/POWER - POWER DELIVERY/FET_SRC: D_U2_1.1 (K), R_U2_3.2, U2.1, U2.3
/Project Architecture/POWER - POWER DELIVERY/ISNK_COARSE: R_U1_8.1, R_U1_9.2, U1.5 (ISNK_COARSE)
/Project Architecture/POWER - POWER DELIVERY/ISNK_FINE: R_U1_10.1, R_U1_11.2, U1.6 (ISNK_FINE)
/Project Architecture/POWER - POWER DELIVERY/SAFE_PWR_EN: R_U3_2.1, U1.4 (SAFE_PWR_EN)
/Project Architecture/POWER - POWER DELIVERY/U3_SRC: U3.2, U3.5
/Project Architecture/POWER - POWER DELIVERY/VBUS_FET_EN: C_U2_1.2, C_U2_2.2, R_U2_1.1, R_U2_2.1, U1.3 (VBUS_FET_EN)
/Project Architecture/POWER - POWER DELIVERY/VBUS_MAX: R_U1_6.2, R_U1_7.1, U1.2 (VBUS_MAX)
/Project Architecture/POWER - POWER DELIVERY/VBUS_MIN: R_U1_4.1, R_U1_5.2, U1.1 (VBUS_MIN)
/Project Architecture/POWER - POWER DELIVERY/V_5V_SAFE_OUT: U3.4; also elsewhere on the board
/Project Architecture/POWER - POWER DELIVERY/V_USB_IN: C_U1_5.1, C_U2_1.1, D_U1_1.2 (A), R_U2_2.2, R_U3_1.2, U1.18 (VBUS_IN), U2.7, U2.8, U3.6; also elsewhere on the board
GND: C_U1_1.2, C_U1_2.2, C_U1_3.2, C_U1_4.1, C_U1_5.2, Q_U1_1.2 (S), R_U1_1.1, R_U1_5.1, R_U1_6.1, R_U1_9.1, R_U1_11.1, U1.19 (GND), U1.22 (GND), U1.25 (GND); also elsewhere on the board
unnamed: D_U1_1.1 (K), R_U1_2.2
unnamed: Q_U1_1.3 (D), R_U1_2.1
unnamed: R_U3_1.1, R_U3_2.2, U3.1, U3.3
unnamed: R_U1_3.1, U1.10 (FLIP)
unnamed: C_U1_4.2, U1.24 (VCCD)
unnamed: R_U1_12.2, U1.11 (VDC_OUT)

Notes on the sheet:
CYPD3177-24LQXQ DATASHEET
CY4533 EVAL BOARD SCHMEATIC
[${#}] ${TITLE}
CYPD3177-24LQ
SAFE POWER LOAD SWITCH
DESIGN NOTE: Charger with Power Path Management
USB
HIGH POWER LOAD SWITCH

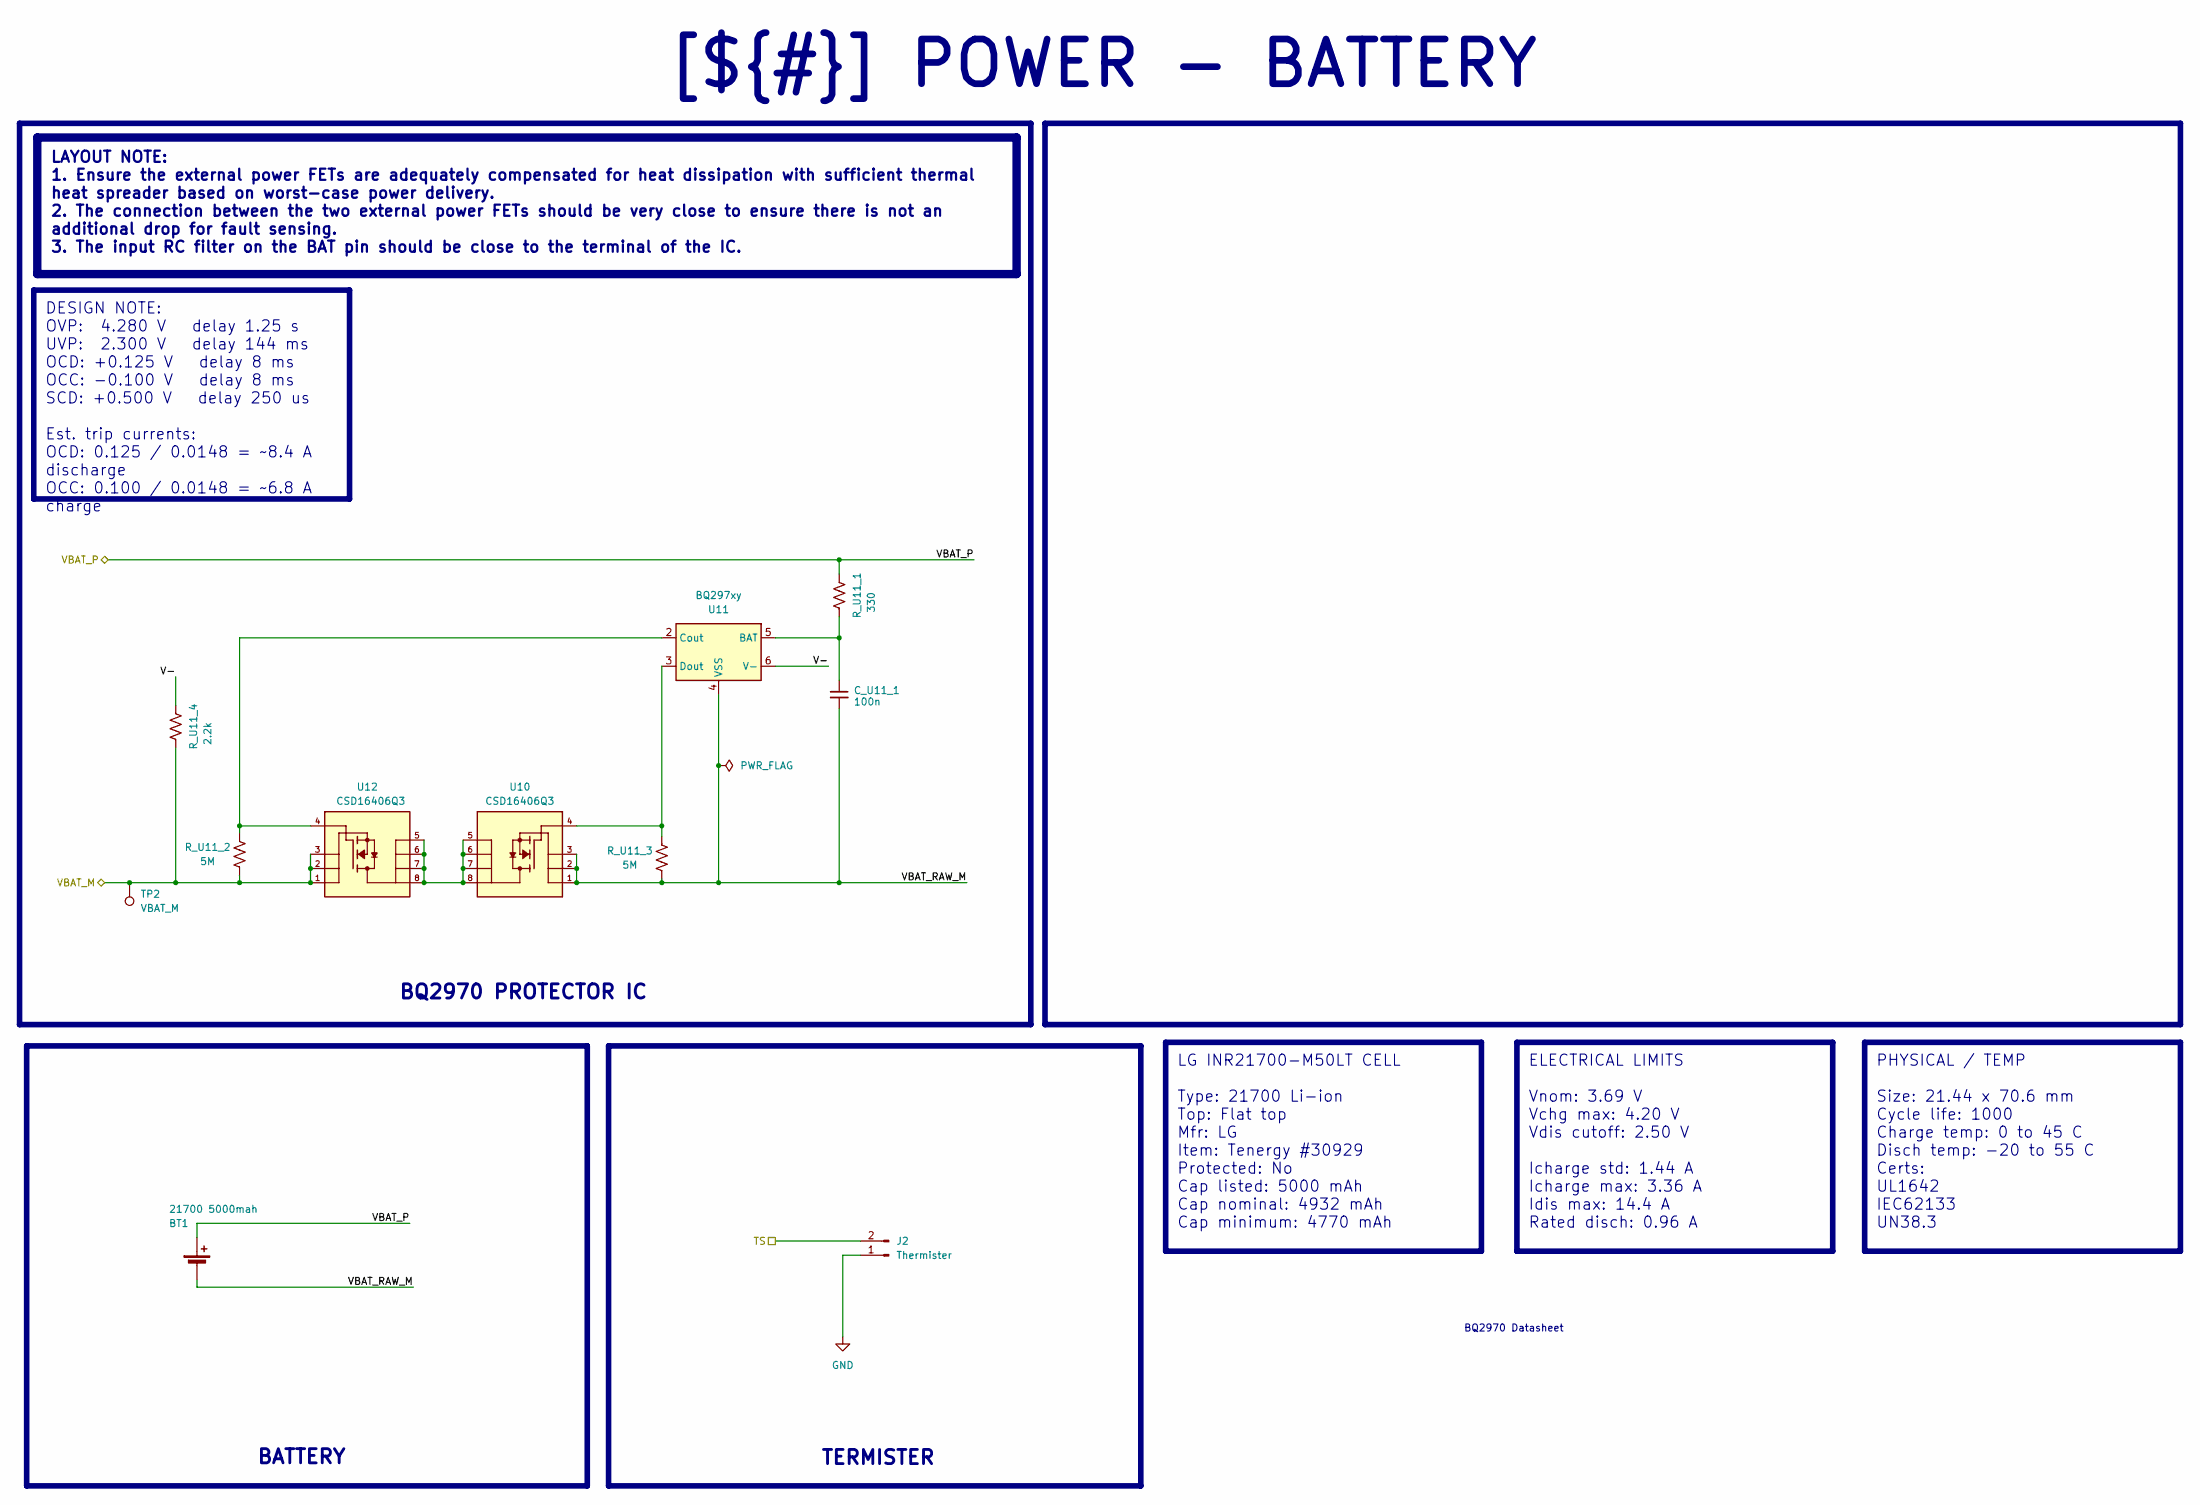
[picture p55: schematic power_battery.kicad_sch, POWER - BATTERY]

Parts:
BT1: 21700 5000mah; BISTOOK_BATTERY_HOLDER_21700
C_U11_1: 100n; C_0603_1608Metric; LCSC C1525
J2: Thermister; PinHeader_1x02_P2.54mm_Vertical
R_U11_1: 330; R_0603_1608Metric_Pad0.98x0.95mm_HandSolder; LCSC C25091
R_U11_2, R_U11_3: 5M; R_0603_1608Metric_Pad0.98x0.95mm_HandSolder; LCSC C25091
R_U11_4: 2.2k; R_0603_1608Metric_Pad0.98x0.95mm_HandSolder; LCSC C25091
TP2: VBAT_M; TestPoint_Pad_D1.5mm
U10, U12: CSD16406Q3; TRANS_CSD16406Q3
U11: BQ297xy; WSON-6_1.5x1.5mm_P0.5mm

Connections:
/Project Architecture/POWER - BATTERY/TS: J2.2; also elsewhere on the board
/Project Architecture/POWER - BATTERY/V-: R_U11_4.1, U11.6 (V-)
/Project Architecture/POWER - BATTERY/VBAT_P: BT1.1 (+), R_U11_1.1; also elsewhere on the board
/Project Architecture/POWER - BATTERY/VBAT_RAW_M: BT1.2 (-), C_U11_1.2, R_U11_3.1, U10.1, U10.2, U10.3, U11.4 (VSS)
GND: J2.1, R_U11_2.1, R_U11_4.2, TP2.1 (1_1), U12.1, U12.2, U12.3; also elsewhere on the board
unnamed: U10.5, U10.6, U10.7, U10.8, U12.5, U12.6, U12.7, U12.8
unnamed: C_U11_1.1, R_U11_1.2, U11.5 (BAT)
unnamed: R_U11_2.2, U11.2 (Cout), U12.4
unnamed: R_U11_3.2, U10.4, U11.3 (Dout)

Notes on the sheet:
BQ2970 Datasheet
TERMISTER
BATTERY
DESIGN NOTE: OVP: 4.280 V delay 1.25 s UVP: 2.300 V delay 144 ms OCD: +0.125 V delay 8 ms OCC: -0.100 V delay 8 ms SCD: +0.500 V delay 250 us Est. trip currents: OCD: 0.125 / 0.0148 = ~8.4 A discharge OCC: 0.100 / 0.0148 = ~6.8 A charge
PHYSICAL / TEMP Size: 21.44 x 70.6 mm Cycle life: 1000 Charge temp: 0 to 45 C Disch temp: -20 to 55 C Certs: UL1642 IEC62133 UN38.3
[${#}] ${TITLE}
LAYOUT NOTE: 1. Ensure the external power FETs are adequately compensated for heat dissipation with sufficient thermal heat spreader based on worst-case power delivery. 2. The connection between the two external power FETs should be very close to ensure there is not an additional drop for fault sen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
ELECTRICAL LIMITS Vnom: 3.69 V Vchg max: 4.20 V Vdis cutoff: 2.50 V Icharge std: 1.44 A Icharge max: 3.36 A Idis max: 14.4 A Rated disch: 0.96 A
LG INR21700-M50LT CELL Type: 21700 Li-ion Top: Flat top Mfr: LG Item: Tenergy #30929 Protected: No Cap listed: 5000 mAh Cap nominal: 4932 mAh Cap minimum: 4770 mAh
BQ2970 PROTECTOR IC

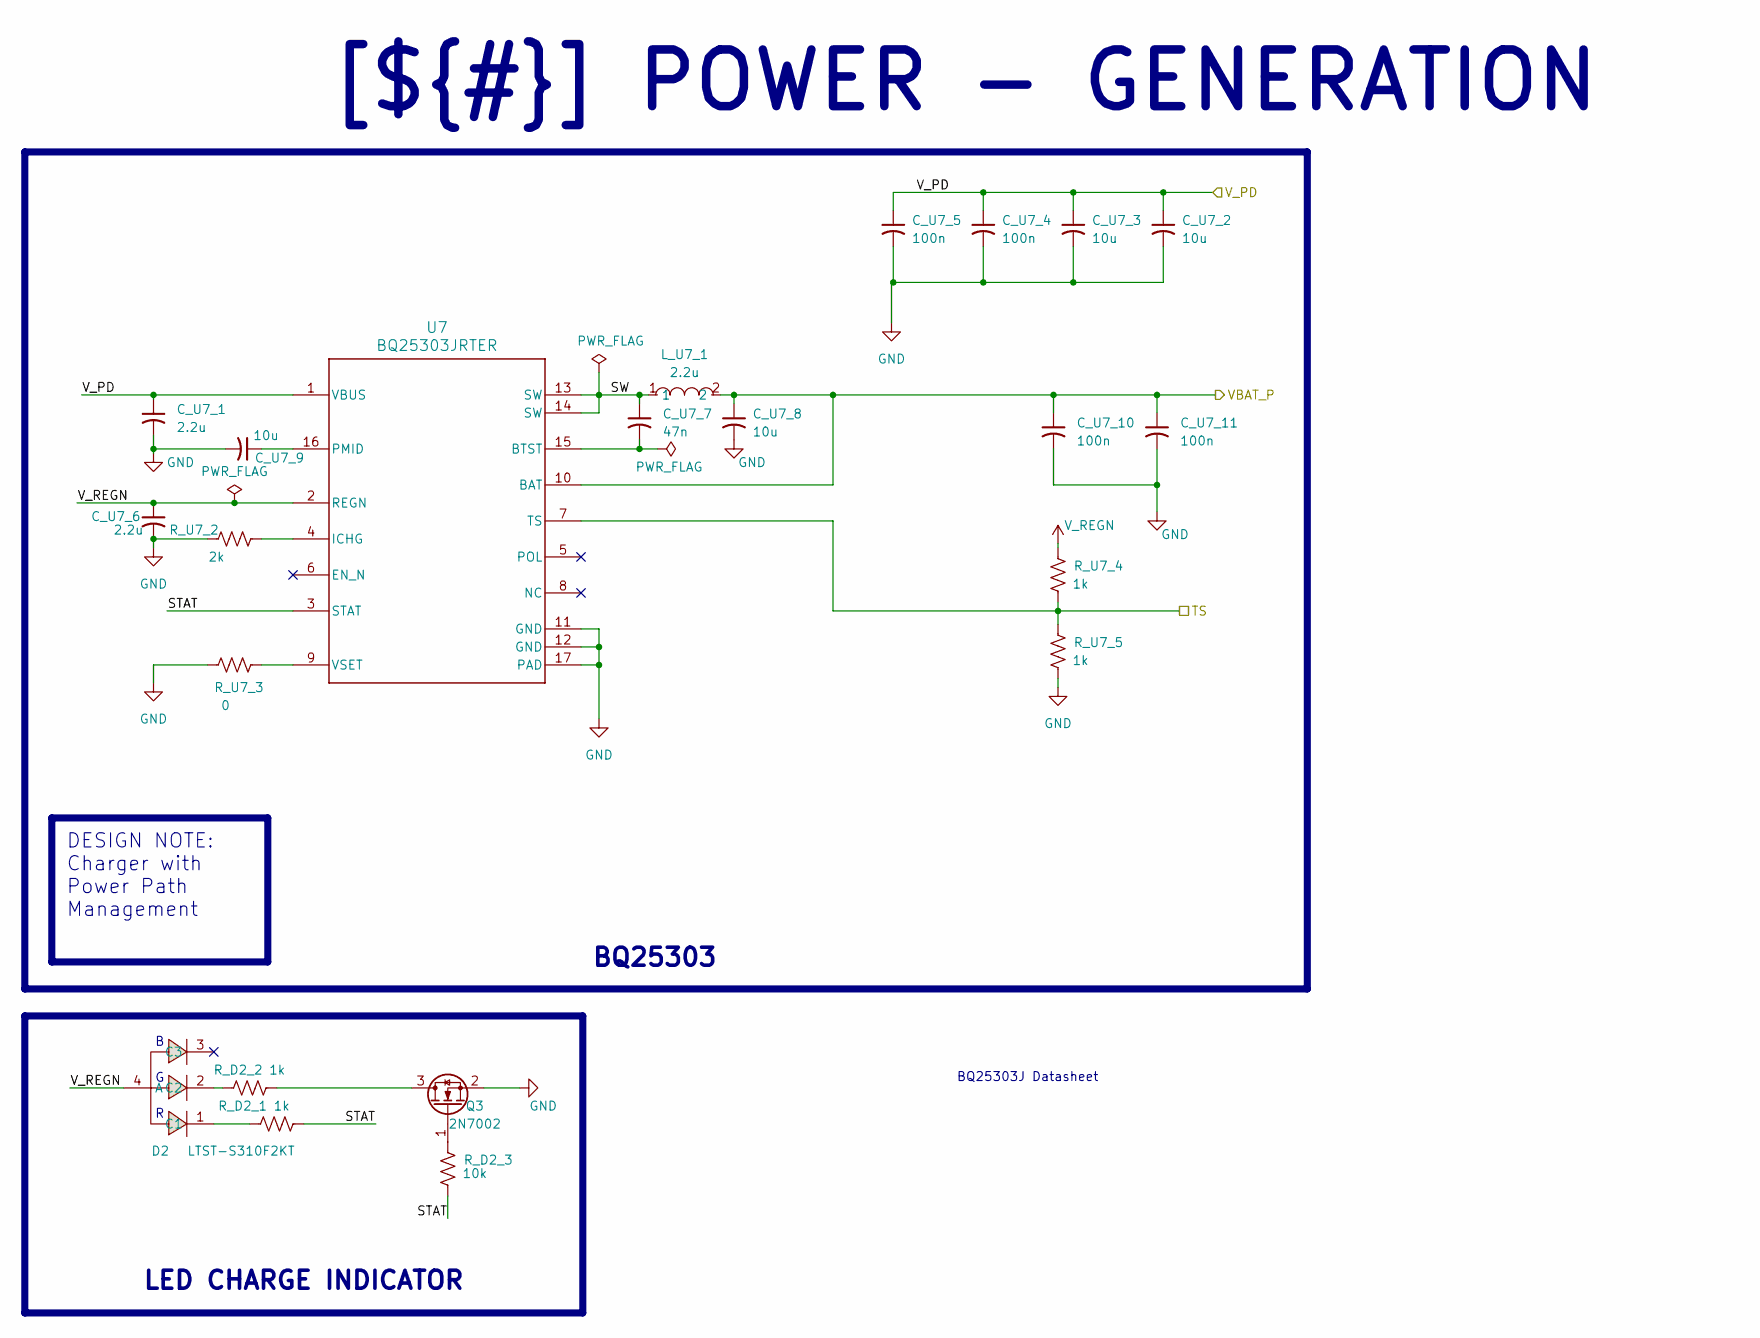
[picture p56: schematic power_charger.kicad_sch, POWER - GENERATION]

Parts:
C_U7_1, C_U7_6: 2.2u; C_0402_1005Metric
C_U7_2, C_U7_3, C_U7_8, C_U7_9: 10u; C_0603_1608Metric
C_U7_4, C_U7_5, C_U7_10, C_U7_11: 100n; C_0402_1005Metric
C_U7_7: 47n; C_0402_1005Metric
D2: LTST-S310F2KT; LED-SMD_4P-L3.2-W1.5_LTST-S310F2KT; LCSC Part C284950
L_U7_1: 2.2u; IND-SMD_L5.0-W5.0_SWPA5040S; MPN NR5040-2R2MTSX01; LCSC Part C22459305
Q3: 2N7002; SOT-23
R_D2_1, R_D2_2: 1k; R_0402_1005Metric; LCSC C25744
R_D2_3: 10k; R_0402_1005Metric; LCSC C25091
R_U7_2: 2k; R_0402_1005Metric; LCSC C25091
R_U7_3: 0; R_0402_1005Metric; LCSC C25091
R_U7_4, R_U7_5: 1k; R_0402_1005Metric; LCSC C25091
U7: BQ25303JRTER; RTE0016C_NV

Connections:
/Project Architecture/POWER - BATTERY/TS: R_U7_4.2, R_U7_5.1, U7.7 (TS); also elsewhere on the board
/Project Architecture/POWER - BATTERY/VBAT_P: C_U7_8.1, C_U7_10.1, C_U7_11.1, L_U7_1.2, U7.10 (BAT); also elsewhere on the board
/Project Architecture/POWER - CHARGER/STAT: R_D2_1.1, R_D2_3.1, U7.3 (STAT)
/Project Architecture/POWER - CHARGER/SW: C_U7_7.1, L_U7_1.1, U7.13 (SW), U7.14 (SW)
/Project Architecture/POWER - CHARGER/V_PD: C_U7_1.1, C_U7_2.1, C_U7_3.1, C_U7_4.1, C_U7_5.1, U7.1 (VBUS); also elsewhere on the board
GND: C_U7_1.2, C_U7_2.2, C_U7_3.2, C_U7_4.2, C_U7_5.2, C_U7_6.2, C_U7_8.2, C_U7_9.2, C_U7_10.2, C_U7_11.2, Q3.2 (S), R_U7_2.2, R_U7_3.2, R_U7_5.2, U7.11 (GND), U7.12 (GND), U7.17 (PAD); also elsewhere on the board
unnamed: D2.1 (C1), R_D2_1.2
unnamed: D2.2 (C2), R_D2_2.2
unnamed: Q3.3 (D), R_D2_2.1
unnamed: Q3.1 (G), R_D2_3.2
unnamed: C_U7_7.2, U7.15 (BTST)
unnamed: R_U7_2.1, U7.4 (ICHG)
unnamed: C_U7_9.1, U7.16 (PMID)
unnamed: R_U7_3.1, U7.9 (VSET)
V_REGN: C_U7_6.1, D2.4 (A), R_U7_4.1, U7.2 (REGN)

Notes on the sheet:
BQ25303J Datasheet
DESIGN NOTE: Charger with Power Path Management
[${#}] ${TITLE}
BQ25303
LED CHARGE INDICATOR

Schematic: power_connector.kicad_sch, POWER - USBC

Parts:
C_J1_1, C_J1_2: 3.3u; R_0603_1608Metric_Pad0.98x0.95mm_HandSolder
D_J1_1: GREEN; LED_0603_1608Metric; LCSC C2286
J1: TYPE-C-31-M-12; USB-C_SMD-TYPE-C-31-M-12; LCSC Part C165948
R_J1_D1_1: 2.2k; R_0402_1005Metric; LCSC C25091
U6: SMF05CT1G; SOT65P210X110-6N; LCSC C15879; not fitted

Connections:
/Project Architecture/POWER - CONNECTOR/CC1: J1.B5 (CC2); also elsewhere on the board
/Project Architecture/POWER - CONNECTOR/CC2: J1.A5 (CC1); also elsewhere on the board
/Project Architecture/POWER - POWER DELIVERY/V_USB_IN: C_J1_1.1, C_J1_2.1, D_J1_1.2 (A), J1.A4 (VBUS), J1.A9 (VBUS), J1.B4 (VBUS), J1.B9 (VBUS); also elsewhere on the board
GND: C_J1_1.2, C_J1_2.2, J1.0 (SHIELD), J1.1 (SHIELD), J1.2 (SHIELD), J1.3 (SHIELD), J1.A1 (GND), J1.A12 (GND), J1.B1 (GND), J1.B12 (GND), R_J1_D1_1.1, U6.2; also elsewhere on the board
unnamed: D_J1_1.1 (K), R_J1_D1_1.2

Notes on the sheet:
ESD
[${#}] ${TITLE}
USB
USB-C

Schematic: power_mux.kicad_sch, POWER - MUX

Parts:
C_U13_1, C_U13_2, C_U17_2, C_U17_3: 1u; C_0402_1005Metric; LCSC C1525
C_U14_1: 100n; C_0402_1005Metric; LCSC C1525
C_U16_1, C_U16_2: 10u; C_0603_1608Metric; LCSC C1525
D_Q1_1, D_Q2_1: GREEN; LED_0603_1608Metric; LCSC C2286
L_U16_1: 4.7u; IND-SMD_L3.0-W3.0_SMNR3015; MPN SMNR3015-4R7MT; LCSC Part C23960
Q1, Q2: 2N7002; SOT-23
R_Q1_1, R_Q2_1: 1k; R_0402_1005Metric; LCSC C25091
R_U14_1: 100; R_0603_1608Metric_Pad0.98x0.95mm_HandSolder; LCSC C25091
R_U16_1: 0; R_0603_1608Metric_Pad0.98x0.95mm_HandSolder; LCSC C25091
R_U16_2: DNP; R_0603_1608Metric_Pad0.98x0.95mm_HandSolder; LCSC C25091; not fitted
U13, U15: CSD16406Q3; TRANS_CSD16406Q3
U14, U17: LM5050-1; TSOT-23-6
U16: TPS61222DCK; Texas_R-PDSO-G6

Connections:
/Project Architecture/POWER - BATTERY/VBAT_P: C_U16_1.1, C_U17_2.1, D_Q1_1.2 (A), D_Q2_1.2 (A), L_U16_1.1, U15.1, U15.2, U15.3, U16.1 (VIN), U16.6 (EN), U17.4 (IN); also elsewhere on the board
/Project Architecture/POWER - CHARGER/V_PD: C_U13_1.1, U13.1, U13.2, U13.3, U14.4 (IN); also elsewhere on the board
/Project Architecture/POWER - MUX/PD_SEL: Q2.1 (G), U13.4, U14.5 (GATE)
/Project Architecture/POWER - MUX/VBAT_SEL: Q1.1 (G), U15.4, U17.5 (GATE)
/Project Architecture/POWER - MUX/VBAT_VS_BIAS: C_U16_2.1, R_U16_1.2, U16.4 (VOUT), U17.1 (VS)
/Project Architecture/POWER - MUX/V_SYS_OUT: C_U13_2.1, C_U17_3.1, R_U14_1.1, U13.5, U13.6, U13.7, U13.8, U14.6 (OUT), U15.5, U15.6, U15.7, U15.8, U17.6 (OUT); also elsewhere on the board
GND: C_U13_1.2, C_U13_2.2, C_U14_1.2, C_U16_1.2, C_U16_2.2, C_U17_2.2, C_U17_3.2, Q1.2 (S), Q2.2 (S), R_U16_2.2, U14.2 (GND), U16.3 (GND), U17.2 (GND); also elsewhere on the board
unnamed: D_Q1_1.1 (K), R_Q1_1.1
unnamed: D_Q2_1.1 (K), R_Q2_1.1
unnamed: Q1.3 (D), R_Q1_1.2
unnamed: Q2.3 (D), R_Q2_1.2
unnamed: C_U14_1.1, R_U14_1.2, U14.1 (VS)
unnamed: R_U16_1.1, R_U16_2.1, U16.2 (FB)
unnamed: L_U16_1.2, U16.5 (L)

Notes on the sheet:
BQ25303J Datasheet
TPS61222 BIAS VOLTAGE
LM5050-1 POWER MUX
LED CHARGE INDICATOR
[${#}] ${TITLE}

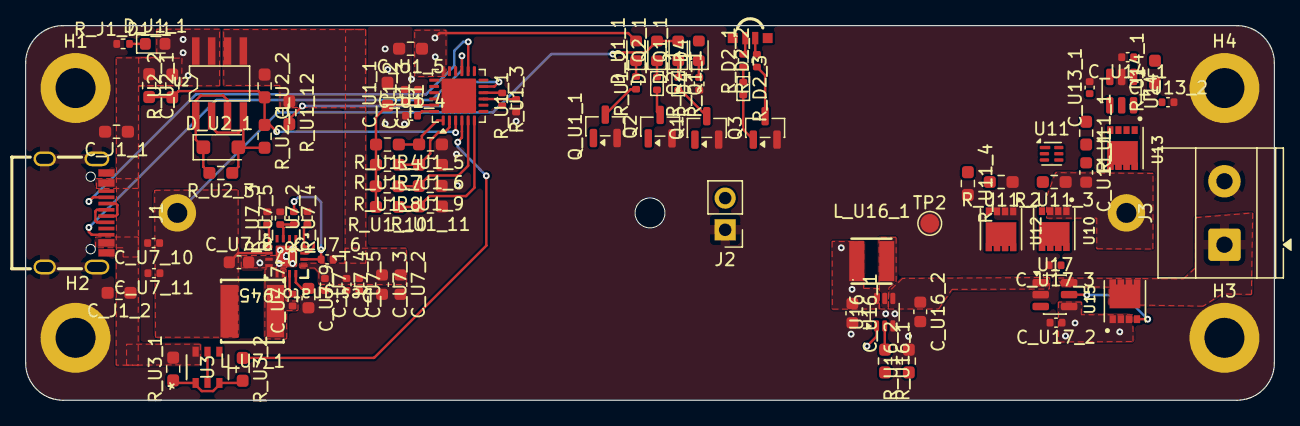
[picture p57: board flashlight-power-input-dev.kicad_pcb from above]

Board: 4 copper layers, 100.0 x 30.0 mm, 97 parts (1 on the bottom side), 55 nets.

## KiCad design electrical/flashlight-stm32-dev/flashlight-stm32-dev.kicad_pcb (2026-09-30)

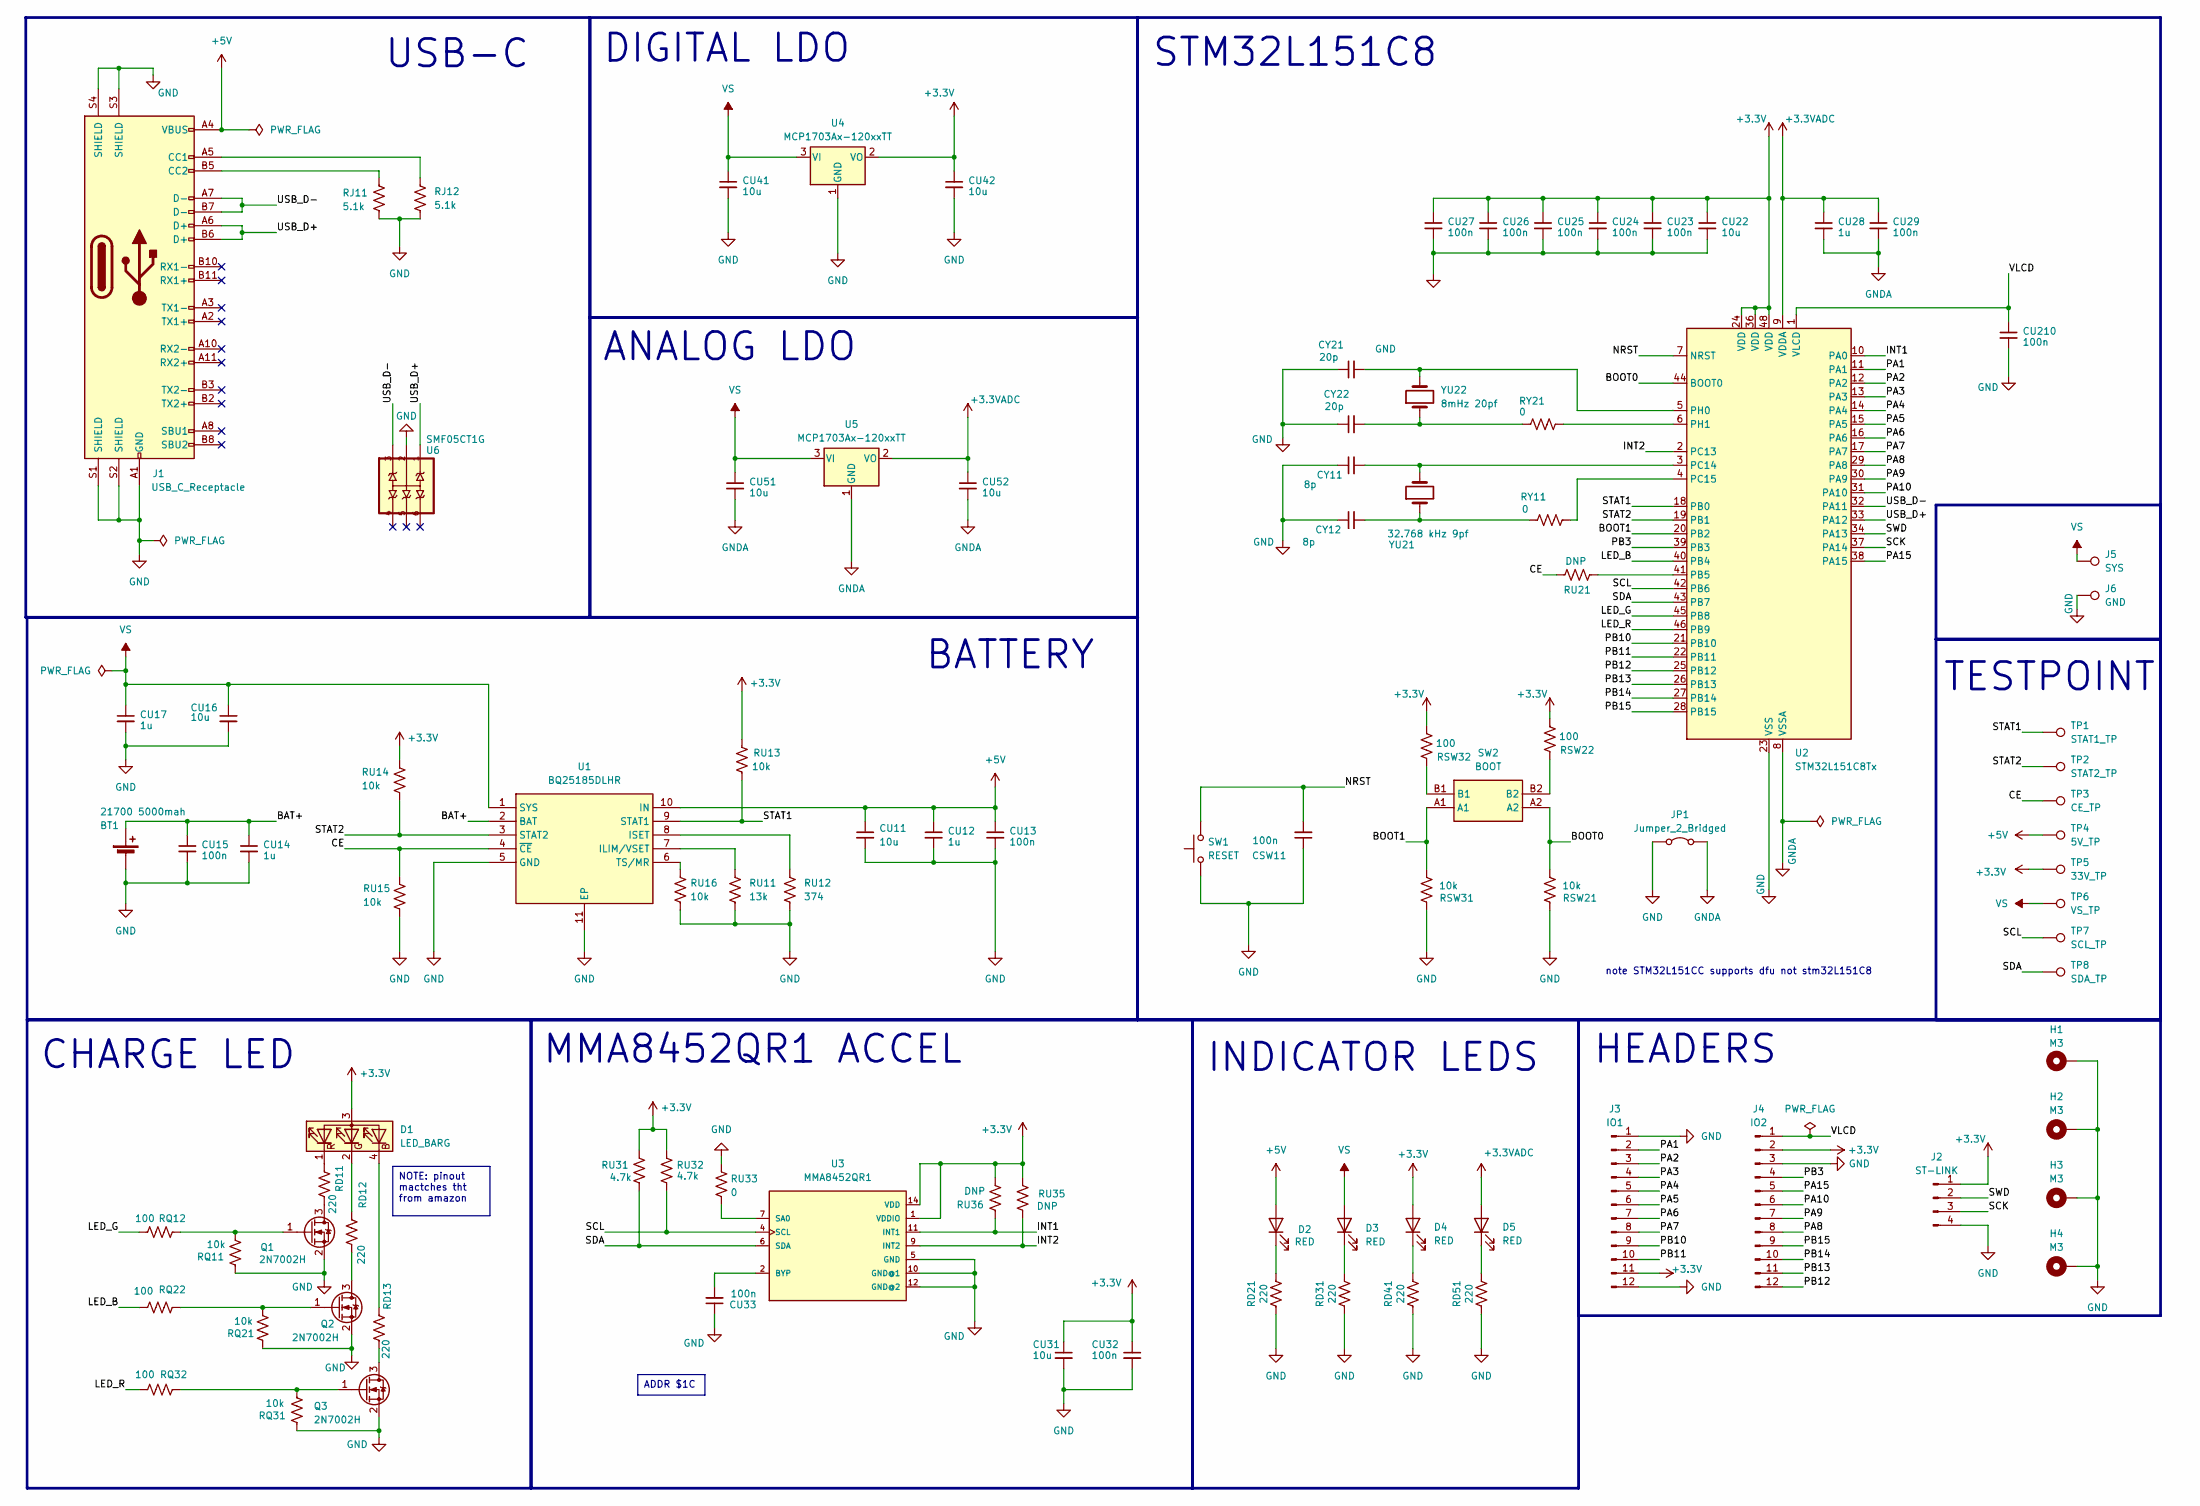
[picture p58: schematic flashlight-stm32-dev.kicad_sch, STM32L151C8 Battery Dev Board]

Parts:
BT1: 21700 5000mah; BISTOOK_BATTERY_HOLDER_21700
CSW11: 100n; C_0402_1005Metric; LCSC C1525
CU11, CU22, CU31, CU41, CU42, CU51, CU52: 10u; C_0603_1608Metric; LCSC C96446
CU12, CU28: 1u; C_0603_1608Metric; LCSC C15849
CU13, CU15, CU23, CU24, CU25, CU26, CU27, CU29, CU32, CU33: 100n; C_0402_1005Metric; LCSC C1525
CU14: 1u; C_0402_1005Metric; LCSC C52923
CU16: 10u; C_0603_1608Metric; LCSC C15849
CU17: 1u; C_0402_1005Metric; LCSC C1525
CU210: 100n; C_0603_1608Metric_Pad1.08x0.95mm_HandSolder; LCSC C1525
CY11, CY12: 8p; C_0402_1005Metric; LCSC C1578
CY21, CY22: 20p; C_0402_1005Metric; LCSC C76959
D1: LED_BARG; LED-SMD_4P-L1.6-W1.6-BR-RD
D2, D3, D4, D5: RED; LED_0603_1608Metric; LCSC C2286
H1, H2, H3, H4: M3; MountingHole_2.7mm_Pad
J1: USB_C_Receptacle; AMPHENOL_12401832E402A; LCSC C464604
J2: ST-LINK; PinHeader_1x04_P2.54mm_Vertical
J3: IO1; PinHeader_1x12_P2.54mm_Vertical
J4: IO2; PinHeader_1x12_P2.54mm_Vertical
J5: SYS; Pin_D1.3mm_L11.0mm
J6: GND; Pin_D1.3mm_L11.0mm
JP1: Jumper_2_Bridged; SolderJumper-2_P1.3mm_Bridged_RoundedPad1.0x1.5mm
Q1, Q2, Q3: 2N7002H; SOT-23_Handsoldering; LCSC C8545
RD11, RD12, RD13, RD21, RD31, RD41, RD51: 220; R_0402_1005Metric; LCSC C25091
RJ11: 5.1k; R_0402_1005Metric; LCSC C25905
RJ12: 5.1k; R_0402_1005Metric; LCSC C25768
RQ11, RQ21, RQ31: 10k; R_0402_1005Metric; LCSC C25744
RQ12, RQ22, RQ32: 100; R_0402_1005Metric; LCSC C25076
RSW21, RSW31: 10k; R_0402_1005Metric; LCSC C25744
RSW22, RSW32: 100; R_0402_1005Metric; LCSC C25076
RU11: 13k; R_0603_1608Metric_Pad0.98x0.95mm_HandSolder; LCSC C22797
RU12: 374; R_0603_1608Metric_Pad0.98x0.95mm_HandSolder; LCSC C23149
RU13, RU14, RU15: 10k; R_0402_1005Metric; LCSC C25744
RU16: 10k; R_0603_1608Metric_Pad0.98x0.95mm_HandSolder; LCSC C25804
RU21: DNP; R_0603_1608Metric_Pad0.98x0.95mm_HandSolder
RU31, RU32: 4.7k; R_0402_1005Metric; LCSC C25744
RU33: 0; R_0603_1608Metric_Pad0.98x0.95mm_HandSolder; LCSC C21189
RU35, RU36: DNP; R_0603_1608Metric_Pad0.98x0.95mm_HandSolder; LCSC C25744
RY11, RY21: 0; R_0603_1608Metric_Pad0.98x0.95mm_HandSolder; LCSC C21189
SW1: RESET; TS1187ABAB; LCSC C318884
SW2: BOOT; 2182LPSTR; Manufacturer_Part_Number 218-2LPSTR; Mouser Part Number 774-2182LPSTR
TP1: STAT1_TP; TestPoint_Pad_D2.0mm
TP2: STAT2_TP; TestPoint_Pad_D2.0mm
TP3: CE_TP; TestPoint_Pad_D2.0mm
TP4: 5V_TP; TestPoint_Pad_D2.0mm
TP5: 33V_TP; TestPoint_Pad_D2.0mm
TP6: VS_TP; TestPoint_Pad_D2.0mm
TP7: SCL_TP; TestPoint_Pad_D2.0mm
TP8: SDA_TP; TestPoint_Pad_D2.0mm
U1: BQ25185DLHR; SON40P220X200X80-11N; Manufacturer_Part_Number BQ25185DLHR; Mouser Part Number 595-BQ25185DLHR
U2: STM32L151C8Tx; LQFP-48_7x7mm_P0.5mm; LCSC C95578
U3: MMA8452QR1; PQFN50P300X300X100-16N
U4, U5: MCP1703Ax-120xxTT; SOT-23_Handsoldering; LCSC C5446
U6: SMF05CT1G; SOT65P210X110-6N; LCSC C15879
YU21: 32.768 kHz 9pf; Crystal_SMD_2012-2Pin_2.0x1.2mm; LCSC C96341
YU22: 8mHz 20pf; Crystal_SMD_5032-2Pin_5.0x3.2mm; LCSC C115962

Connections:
+3.3V: CU22.1, CU23.1, CU24.1, CU25.1, CU26.1, CU27.1, CU31.1, CU32.1, CU42.1, D1.3 (A), D4.2 (A), J2.1, J3.11, J4.2, RSW22.1, RSW32.1, RU13.2, RU14.2, RU31.2, RU32.2, RU35.2, RU36.1, TP5.1, U2.24 (VDD), U2.36 (VDD), U2.48 (VDD), U3.1 (VDDIO), U3.14 (VDD), U4.2 (VO)
+3.3VADC: CU28.1, CU29.1, CU52.1, D5.2 (A), U2.9 (VDDA), U5.2 (VO)
+5V: CU11.1, CU12.1, CU13.1, D2.2 (A), J1.A4 (VBUS), J1.A9 (VBUS), J1.B4 (VBUS), J1.B9 (VBUS), TP4.1, U1.10 (IN)
/BAT+: BT1.1 (+), CU14.1, CU15.1, U1.2 (BAT)
/BOOT0: RSW21.2, SW2.A2, U2.44 (BOOT0)
/BOOT1: RSW31.2, SW2.A1, U2.20 (PB2)
/CE: RU15.2, RU21.2, TP3.1, U1.4 (~CE)
/INT1: RU36.2, U2.10 (PA0), U3.11 (INT1)
/INT2: RU35.1, U2.2 (PC13), U3.9 (INT2)
/LED_B: RQ22.1, U2.40 (PB4)
/LED_G: RQ12.1, U2.45 (PB8)
/LED_R: RQ32.1, U2.46 (PB9)
/NRST: CSW11.2, SW1.2, U2.7 (NRST)
/PA1: J3.2, U2.11 (PA1)
/PA2: J3.3, U2.12 (PA2)
/PA3: J3.4, U2.13 (PA3)
/PA4: J3.5, U2.14 (PA4)
/PA5: J3.6, U2.15 (PA5)
/PA6: J3.7, U2.16 (PA6)
/PA7: J3.8, U2.17 (PA7)
/PA8: J4.8, U2.29 (PA8)
/PA9: J4.7, U2.30 (PA9)
/PA10: J4.6, U2.31 (PA10)
/PA15: J4.5, U2.38 (PA15)
/PB3: J4.4, U2.39 (PB3)
/PB10: J3.9, U2.21 (PB10)
/PB11: J3.10, U2.22 (PB11)
/PB12: J4.12, U2.25 (PB12)
/PB13: J4.11, U2.26 (PB13)
/PB14: J4.10, U2.27 (PB14)
/PB15: J4.9, U2.28 (PB15)
/SCK: J2.3, U2.37 (PA14)
/SCL: RU32.1, TP7.1, U2.42 (PB6), U3.4 (SCL)
/SDA: RU31.1, TP8.1, U2.43 (PB7), U3.6 (SDA)
/STAT1: RU13.1, TP1.1, U1.9 (STAT1), U2.18 (PB0)
/STAT2: RU14.1, TP2.1, U1.3 (STAT2), U2.19 (PB1)
/SWD: J2.2, U2.34 (PA13)
/USB_D+: J1.A6 (D+), J1.B6 (D+), U2.33 (PA12), U6.1
/USB_D-: J1.A7 (D-), J1.B7 (D-), U2.32 (PA11), U6.3
/VLCD: CU210.1, J4.1, U2.1 (VLCD)
GND: BT1.2 (-), CSW11.1, CU11.2, CU12.2, CU13.2, CU14.2, CU15.2, CU16.2, CU17.2, CU22.2, CU23.2, CU24.2, CU25.2, CU26.2, CU27.2, CU31.2, CU32.2, CU33.1, CU41.2, CU42.2, CU210.2, CY11.1, CY12.1, CY21.1, CY22.1, H1.1, H2.1, H3.1, H4.1, J1.A1 (GND), J1.A12 (GND), J1.B1 (GND), J1.B12 (GND), J1.S1 (SHIELD), J1.S2 (SHIELD), J1.S3 (SHIELD), J1.S4 (SHIELD), J2.4, J3.1, J3.12, J4.3, J6.1, JP1.1 (A), Q1.2 (S), Q2.2 (S), Q3.2 (S), RD21.1, RD31.1, RD41.1, RD51.1, RJ11.2, RJ12.1, RQ11.1, RQ21.1, RQ31.1, RSW21.1, RSW31.1, RU11.1, RU12.1, RU15.1, RU16.1, RU33.1, SW1.1, U1.5 (GND), U1.11 (EP), U2.23 (VSS), U2.35 (VSS), U2.47 (VSS), U3.5 (GND), U3.10 (GND@1), U3.12 (GND@2), U4.1 (GND), U6.2
GNDA: CU28.2, CU29.2, CU51.2, CU52.2, JP1.2 (B), U2.8 (VSSA), U5.1 (GND)
unnamed: CY12.2, RY11.2, YU21.1
unnamed: CY22.2, RY21.2, YU22.1
unnamed: D1.4 (BK), RD13.2
unnamed: D1.2 (GK), RD12.2
unnamed: D1.1 (RK), RD11.2
unnamed: D2.1 (K), RD21.2
unnamed: D3.1 (K), RD31.2
unnamed: D4.1 (K), RD41.2
unnamed: D5.1 (K), RD51.2
unnamed: J1.A5 (CC1), RJ12.2
unnamed: J1.B5 (CC2), RJ11.1
unnamed: Q1.3 (D), RD11.1
unnamed: Q1.1 (G), RQ11.2, RQ12.2
unnamed: Q2.3 (D), RD12.1
unnamed: Q2.1 (G), RQ21.2, RQ22.2
unnamed: Q3.3 (D), RD13.1
unnamed: Q3.1 (G), RQ31.2, RQ32.2
unnamed: RSW22.2, SW2.B2
unnamed: RSW32.2, SW2.B1
unnamed: RU11.2, U1.7 (ILIM/VSET)
unnamed: RU12.2, U1.8 (ISET)
unnamed: RU16.2, U1.6 (TS/MR)
unnamed: RU21.1, U2.41 (PB5)
unnamed: CY11.2, U2.3 (PC14), YU21.2
unnamed: RY11.1, U2.4 (PC15)
unnamed: CY21.2, U2.5 (PH0), YU22.2
unnamed: RY21.1, U2.6 (PH1)
unnamed: CU33.2, U3.2 (BYP)
unnamed: RU33.2, U3.7 (SA0)
VS: CU16.1, CU17.1, CU41.1, CU51.1, D3.2 (A), J5.1, TP6.1, U1.1 (SYS), U4.3 (VI), U5.3 (VI)

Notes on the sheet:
NOTE: pinout mactches tht from amazon
ADDR $1C
USB-C
note STM32L151CC supports dfu not stm32L151C8
HEADERS
ANALOG LDO
MMA8452QR1 ACCEL
TESTPOINT
DIGITAL LDO
BATTERY
CHARGE LED
INDICATOR LEDS
STM32L151C8

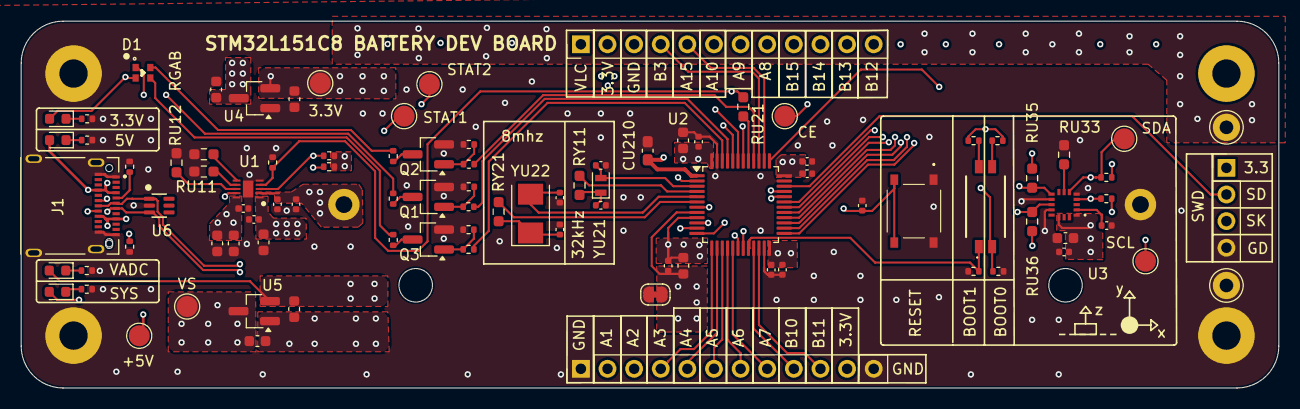
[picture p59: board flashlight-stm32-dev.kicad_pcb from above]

Board: 6 copper layers, 120.0 x 35.0 mm, 99 parts (1 on the bottom side), 72 nets.

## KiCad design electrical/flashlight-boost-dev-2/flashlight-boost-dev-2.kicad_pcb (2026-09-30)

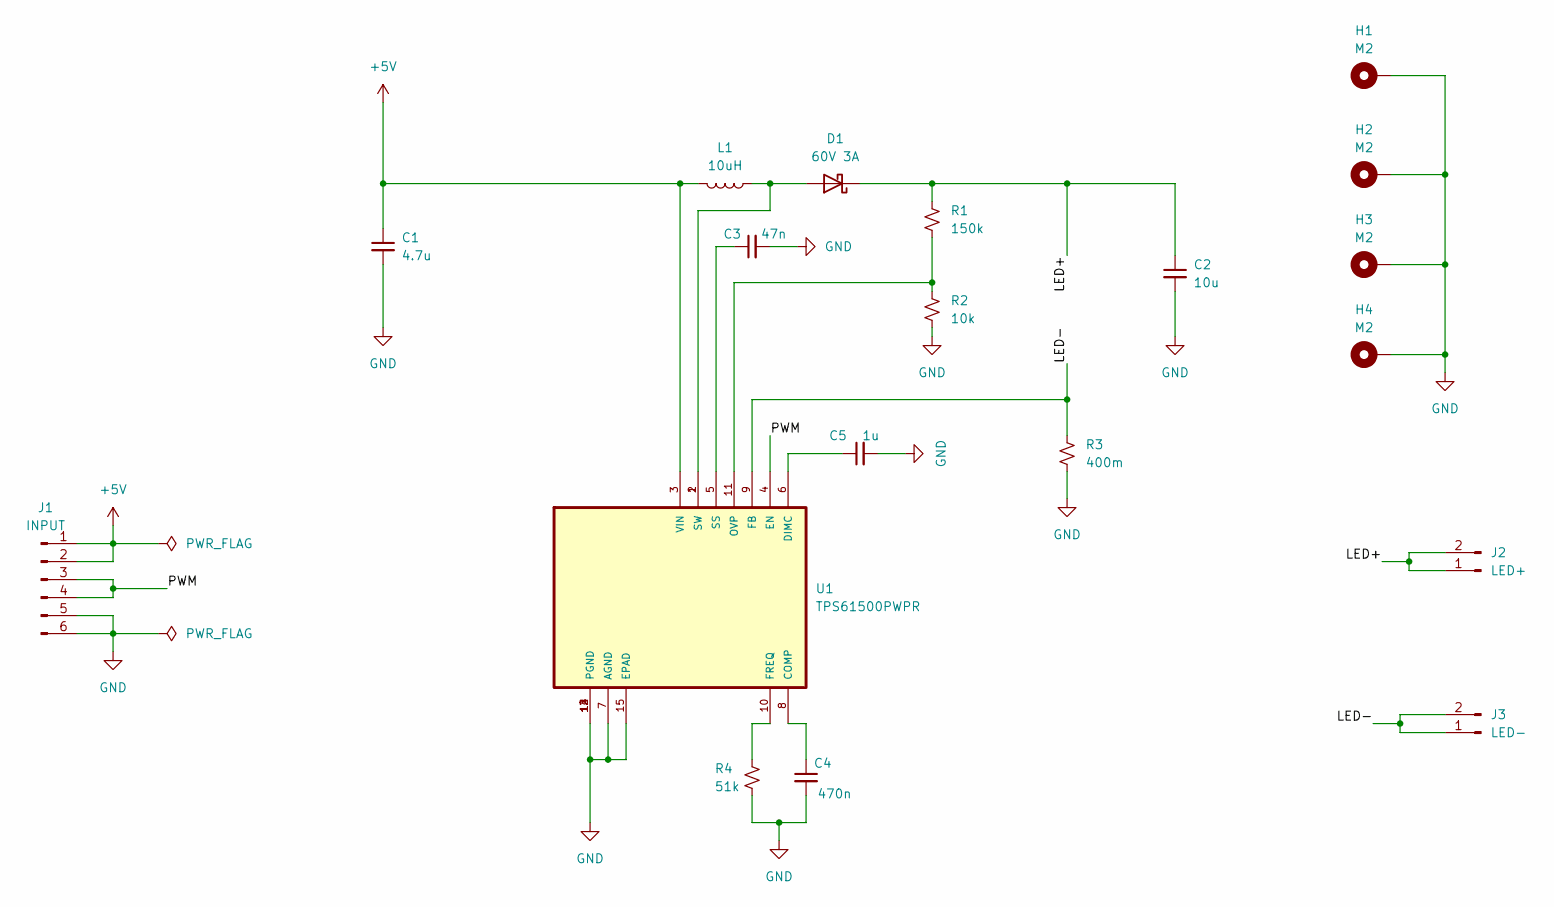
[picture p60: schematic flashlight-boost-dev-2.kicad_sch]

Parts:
C1: 4.7u; C_0603_1608Metric_Pad1.08x0.95mm_HandSolder; LCSC C19666
C2: 10u; C_0603_1608Metric_Pad1.08x0.95mm_HandSolder; LCSC C96446
C3: 47n; C_0603_1608Metric_Pad1.08x0.95mm_HandSolder; LCSC C1622
C4: 470n; C_0603_1608Metric_Pad1.08x0.95mm_HandSolder; LCSC C1623
C5: 1u; C_0603_1608Metric_Pad1.08x0.95mm_HandSolder; LCSC C15849
D1: 60V 3A; DIOM7959X262N; LCSC C35722
H1, H2, H3, H4: M2; MountingHole_2.5mm_Pad
J1: INPUT; PinHeader_1x06_P2.54mm_Vertical
J2: LED+; PinHeader_1x02_P2.54mm_Vertical
J3: LED-; PinHeader_1x02_P2.54mm_Vertical
L1: 10uH; L_10.4x10.4_H4.8; LCSC C171589
R1: 150k; R_0603_1608Metric_Pad0.98x0.95mm_HandSolder; LCSC C22807
R2: 10k; R_0603_1608Metric_Pad0.98x0.95mm_HandSolder; LCSC C25804
R3: 400m; R_0603_1608Metric_Pad0.98x0.95mm_HandSolder; LCSC C57344
R4: 51k; R_0603_1608Metric_Pad0.98x0.95mm_HandSolder; LCSC C23196
U1: TPS61500PWPR; IC_TPS27S100BPWPR; LCSC C71160

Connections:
+5V: C1.1, J1.1, J1.2, L1.2, U1.3 (VIN)
/LED+: C2.1, D1.1 (K), J2.1, J2.2, R1.1
/LED-: J3.1, J3.2, R3.1, U1.9 (FB)
/PWM: J1.3, J1.4, U1.4 (EN)
GND: C1.2, C2.2, C3.2, C4.2, C5.2, H1.1, H2.1, H3.1, H4.1, J1.5, J1.6, R2.2, R3.2, R4.2, U1.7 (AGND), U1.12 (PGND), U1.13 (PGND), U1.14 (PGND), U1.15 (EPAD)
unnamed: D1.2 (A), L1.1, U1.1 (SW), U1.2 (SW)
unnamed: C4.1, U1.8 (COMP)
unnamed: C5.1, U1.6 (DIMC)
unnamed: R4.1, U1.10 (FREQ)
unnamed: R1.2, R2.1, U1.11 (OVP)
unnamed: C3.1, U1.5 (SS)


Board: 2 copper layers, 33.0 x 33.0 mm, 19 parts (0 on the bottom side), 11 nets.

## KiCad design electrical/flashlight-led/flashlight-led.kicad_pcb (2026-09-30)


Board: 2 copper layers, 32.0 x 32.0 mm, 8 parts (0 on the bottom side), 4 nets, no tracks yet.

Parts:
D1, D2, D3: LED_WARM; JR5050CWTEB30EB0000N0000001
H1, H2, H3: MountingHole; MountingHole_2.2mm_M2
J1: +18V; TestPoint_THTPad_D3.0mm_Drill1.5mm
J3: GND; TestPoint_THTPad_D3.0mm_Drill1.5mm

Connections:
+18V: D1.2 (A), J1.1
/D12: D1.1 (K), D2.2 (A)
/D23: D2.1 (K), D3.2 (A)
GND: D3.1 (K), J3.1

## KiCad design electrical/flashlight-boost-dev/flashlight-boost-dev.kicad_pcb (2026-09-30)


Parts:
CU11, CU13: 4.7u; C_0805_2012Metric_Pad1.18x1.45mm_HandSolder
CU12: 1u; C_0603_1608Metric
DU11: NSR0240P2T5G; SOD-923
H1, H2, H3, H4: M2; MountingHole_2.2mm_M2_Pad
J1: IN; PinHeader_1x06_P2.54mm_Vertical
J2: LED1-; PinHeader_1x02_P2.54mm_Vertical
J3: LED1+; PinHeader_1x02_P2.54mm_Vertical
LU11: 4.7u; WE-MAPI_4030
RU11: 0.5; R_1206_3216Metric_Pad1.30x1.75mm_HandSolder
U1: TPS61169DCKR; SOT65P210X110-5N; PARTREV A

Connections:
+5V: CU11.1, CU12.1, J1.5, J1.6, LU11.1, U1.5 (VIN)
/LED1+: CU13.1, DU11.P$1, J3.1, J3.2
/LED1-: J2.1, J2.2, RU11.1, U1.3 (FB)
/PWM1: J1.3, J1.4, U1.4 (CTRL)
/VOUT: DU11.P$2, LU11.2, U1.1 (SW)
GND: CU11.2, CU12.2, CU13.2, H1.1, H2.1, H3.1, H4.1, J1.1, J1.2, RU11.2, U1.2 (GND)


Board: 2 copper layers, 32.0 x 32.0 mm, 14 parts (0 on the bottom side), 6 nets.

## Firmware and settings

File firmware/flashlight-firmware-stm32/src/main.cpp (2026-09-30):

#include <Arduino.h>
#include <Wire.h>                 // Must include Wire library for I2C
#include "SparkFun_MMA8452Q.h"    // Click here to get the library: http://librarymanager/All#SparkFun_MMA8452Q
#include <stdio.h>
#include <STM32LowPower.h>
#include <rtc.h>

const PinMap PinMap_I2C_SDA[] = {
  {PB_7,  I2C1, STM_PIN_DATA(STM_MODE_AF_OD, GPIO_NOPULL, GPIO_AF4_I2C1)}, // RADIO_RF_CBT_HF
  {NC,    NP,   0}
};

const PinMap PinMap_I2C_SCL[] = {
  {PB_6,  I2C1, STM_PIN_DATA(STM_MODE_AF_OD, GPIO_NOPULL, GPIO_AF4_I2C1)}, // RADIO_RF_CRX_RX
  {NC,    NP,   0}
};

MMA8452Q accel;                   // create instance of the MMA8452 class
STM32RTC &rtc = STM32RTC::getInstance();

volatile bool transientDetected = false;  // ISR flag
unsigned long lastShakeTime = 0;
bool on = false;
unsigned long switchedOnT = -1;

void configureTransientDetection() {
  accel.standby();

  accel.writeRegister(TRANSIENT_CFG, 0b00010110); // X/Y axes, latch enabled
  accel.writeRegister(TRANSIENT_THS, 12);       // 127=8g, 0=0.063g
  accel.writeRegister(TRANSIENT_COUNT, 25);     // COUNT * 20ms 
  accel.writeRegister(CTRL_REG4, 0x20);           // Enable transient interrupt
  accel.writeRegister(CTRL_REG5, 0x20);           // Route to INT1

  accel.active();
}

void onTransientInterrupt() {
  transientDetected = true;
}

unsigned long rtcSeconds() {
  return (rtc.getHours() * 3600UL +
          rtc.getMinutes() * 60UL +
          rtc.getSeconds()) * 1000UL;
}

void setup() {
  pinMode(PB9, OUTPUT);
  Serial.begin(9600);

  Wire.setSDA(PB_7);
  Wire.setSCL(PB_6);
  Wire.begin();

  if (accel.begin(Wire, 0x1C) == false) {
    Serial.println("Not Connected. Please check connections and read the hookup guide.");
    while (1) {
      Serial.println("Not Connected...");
      digitalWriteFast(PB_9, 1);
      delay(1000);
      digitalWriteFast(PB_9, 0);
      delay(1000);
    }
  }
  configureTransientDetection();
  LowPower.attachInterruptWakeup(PA0, onTransientInterrupt, FALLING, SLEEP_MODE);

  rtc.setClockSource(STM32RTC::LSI_CLOCK); // or LSE_CLOCK if you have a crystal
  rtc.begin();           
  rtc.setHours(0);
  rtc.setMinutes(0);
  rtc.setSeconds(0);

  byte intSource = accel.readRegister(INT_SOURCE);
  byte src = accel.readRegister(TRANSIENT_SRC); // Clear the interrupt
  Serial.println("Setup complete.\n");
}

void loop() {
  LowPower.deepSleep();
  delay(20);

  if (transientDetected) { 
    Serial.println("Interrtupt\n");
    transientDetected = false;
    
    unsigned long now = rtcSeconds();
    byte intSource = accel.readRegister(INT_SOURCE);
    byte src = accel.readRegister(TRANSIENT_SRC); // Clear the interrupt

    if (now == lastShakeTime && now != switchedOnT) {
      switchedOnT = now;
      Serial.println("LED!\n");
      on = !on;
      if (on) {
        digitalWriteFast(PB_9, 1);
      }
      else {
        digitalWriteFast(PB_9, 0);
      }
    }

    lastShakeTime = now;
  }
}

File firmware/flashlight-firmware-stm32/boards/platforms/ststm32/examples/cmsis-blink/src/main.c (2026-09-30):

#ifdef STM32L0
    #include "stm32l0xx.h"
    #define LEDPORT (GPIOB)
    #define LED1 (3)
    #define ENABLE_GPIO_CLOCK (RCC->IOPENR |= RCC_IOPENR_GPIOBEN)
    #define _MODER    MODER
    #define GPIOMODER (GPIO_MODER_MODE3_0)
#elif STM32L1
    #include "stm32l1xx.h"
    #define LEDPORT (GPIOB)
    #define LED1 (6)
    #define ENABLE_GPIO_CLOCK (RCC->AHBENR |= RCC_AHBENR_GPIOBEN)
    #define _MODER    MODER
    #define GPIOMODER (GPIO_MODER_MODER6_0)
#elif STM32L4
    #include "stm32l4xx.h"
    #define LEDPORT (GPIOB)
    #define LED1 (3)
    #define ENABLE_GPIO_CLOCK (RCC->AHB2ENR |= RCC_AHB2ENR_GPIOBEN)
    #define _MODER    MODER
    #define GPIOMODER (GPIO_MODER_MODE3_0)
#elif STM32L5
    #include "stm32l5xx.h"
    #define LEDPORT (GPIOB)
    #define LED1 (6)
    #define ENABLE_GPIO_CLOCK (RCC->AHBENR |= RCC_AHBENR_GPIOBEN)
    #define _MODER    MODER
    #define GPIOMODER (GPIO_MODER_MODER6_0)
#elif STM32F0
    #include "stm32f0xx.h"
    #define LEDPORT (GPIOC)
    #define LED1 (8)
    #define ENABLE_GPIO_CLOCK (RCC->AHBENR |= RCC_AHBENR_GPIOCEN)
    #define _MODER    MODER
    #define GPIOMODER (GPIO_MODER_MODER8_0)
#elif STM32F1
    #include "stm32f1xx.h"
    #define LEDPORT (GPIOC)
    #define LED1 (13)
    #define ENABLE_GPIO_CLOCK (RCC->APB2ENR |= RCC_APB2ENR_IOPCEN)
    #define _MODER    CRH
    #define GPIOMODER (GPIO_CRH_MODE13_0)
#elif STM32F2
    #include "stm32f2xx.h"
    #define LEDPORT (GPIOB)
    #define LED1 (0)
    #define ENABLE_GPIO_CLOCK (RCC->AHB1ENR |= RCC_AHB1ENR_GPIOBEN)
    #define _MODER    MODER
    #define GPIOMODER (GPIO_MODER_MODER8_0)
#elif STM32F3
    #include "stm32f3xx.h"
    #define LEDPORT (GPIOE)
    #define LED1 (8)
    #define ENABLE_GPIO_CLOCK (RCC->AHBENR |= RCC_AHBENR_GPIOAEN)
    #define _MODER    MODER
    #define GPIOMODER (GPIO_MODER_MODER8_0)
#elif STM32F4
    #include "stm32f4xx.h"
    #define LEDPORT (GPIOD)
    #define LED1 (12)
    #define ENABLE_GPIO_CLOCK (RCC->AHB1ENR |= RCC_AHB1ENR_GPIODEN)
    #define _MODER    MODER
    #define GPIOMODER (GPIO_MODER_MODER12_0)
#elif STM32F7
    #include "stm32f7xx.h"
    #define LEDPORT (GPIOB)
    #define LED1 (0)
    #define ENABLE_GPIO_CLOCK (RCC->AHB1ENR |= RCC_AHB1ENR_GPIOBEN)
    #define _MODER    MODER
    #define GPIOMODER (GPIO_MODER_MODER0_0)
#elif STM32H7
    #include "stm32h7xx.h"
    #define LEDPORT (GPIOB)
    #define LED1 (0)
    #define ENABLE_GPIO_CLOCK (RCC->AHB4ENR |= RCC_AHB4ENR_GPIOBEN)
    #define _MODER    MODER
    #define GPIOMODER (GPIO_MODER_MODE0_0)
#elif STM32G0
    #include "stm32g0xx.h"
    #define LEDPORT (GPIOA)
    #define LED1 (5)
    #define ENABLE_GPIO_CLOCK (RCC->IOPENR |= RCC_IOPENR_GPIOAEN)
    #define _MODER    MODER
    #define GPIOMODER (GPIO_MODER_MODE5_0)
#elif STM32G4
    #include "stm32g4xx.h"
    #define LEDPORT (GPIOA)
    #define LED1 (5)
    #define ENABLE_GPIO_CLOCK (RCC->AHB2ENR |= RCC_AHB2ENR_GPIOAEN)
    #define _MODER    MODER
    #define GPIOMODER (GPIO_MODER_MODE5_0)
#endif


void ms_delay(int ms)
{
   while (ms-- > 0) {
      volatile int x=500;
      while (x-- > 0)
         __asm("nop");
   }
}

//Alternates blue and green LEDs quickly
int main(void)
{
    ENABLE_GPIO_CLOCK;              // enable the clock to GPIO
    LEDPORT->_MODER |= GPIOMODER;   // set pins to be general purpose output
    for (;;) {
    ms_delay(500);
    LEDPORT->ODR ^= (1<<LED1);  // toggle diodes
    }

    return 0;
}

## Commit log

2025-02-17 with headers
    [flashlight-stm32-dev.kicad_pcb, flashlight-stm32-dev.kicad_sch]
2025-02-17 jlc init
    [flashlight-stm32-dev.kicad_pcb]
2025-02-18 updated accel and usbc cc
    [BOM-flashlight-stm32-dev.csv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]
2025-02-19 final for review
    [BOM-flashlight-stm32-dev.csv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]
2025-04-01 jlc result
    [BOM-flashlight-stm32-dev.csv, flashlight-boost-dev-2.kicad_pcb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]
2025-04-21 full init
    [flashlight-full-v1.kicad_pcb, flashlight-full-v1.kicad_sch, pcb-mural-board-holder-stm32-dev.SLDPRT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]
2025-04-24 TPS61088 added to lib
    [flashlight-full-v1.kicad_sch]
2025-04-26 full new
    [accelerometer.kicad_sch, block_diagram.kicad_sch, current_sense.kicad_sch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]
2026-09-30 Reorganize into standard project layout; add power-input board and report
    Move KiCad boards to electrical/, STM32 firmware to firmware/, CAD to mechanical/,
    boost-converter MATLAB sim to analysis/, proposal and final report to docs/reports/
    per docs/STRUCTURE.md. Adds flashlight-power-input-dev (USB-PD power input board)
    and other previously uncommitted work. admin/ is git-ignored.
    Claude-Session: https://claude.ai/code/session_011fcbtq5kvbvgwpsb6ou6yg
    [18650-battery.SLDPRT, ASSEMBLY.SLDPRT, BOM-flashlight-boost-dev-2.csv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]
2026-09-30 Rewrite README with build, reproduction and design details; add board renders
    Claude-Session: https://claude.ai/code/session_011fcbtQ5KvbvgwPSb6oU6YG
2026-09-30 Remove personal text from copied mp3 silkscreen files
    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
    [mp3-project-v2-SilkBottom.gbr]
